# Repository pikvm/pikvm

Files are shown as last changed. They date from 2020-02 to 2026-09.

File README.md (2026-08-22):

# Open and inexpensive DIY IP-KVM based on Raspberry Pi
 

A very simple and fully functional Raspberry Pi-based KVM (Keyboard-Video-Mouse) over IP that you can make with your own hands. This device helps to manage servers or workstations remotely, regardless of the health of the operating system or whether one is installed. You can fix any problem, configure the BIOS, and even reinstall the OS using the virtual CD/DVD or Flash Drive.

The website: [pikvm.org](https://pikvm.org). Also check out [the documentation](https://docs.pikvm.org) and join the [Discord Community Chat](https://discord.gg/bpmXfz5) for news, questions and support! Also you can visit our [Support Forum](https://forum.pishop.com/c/pikvm).

| Web UI                                     |
| ------------------------------------------ |
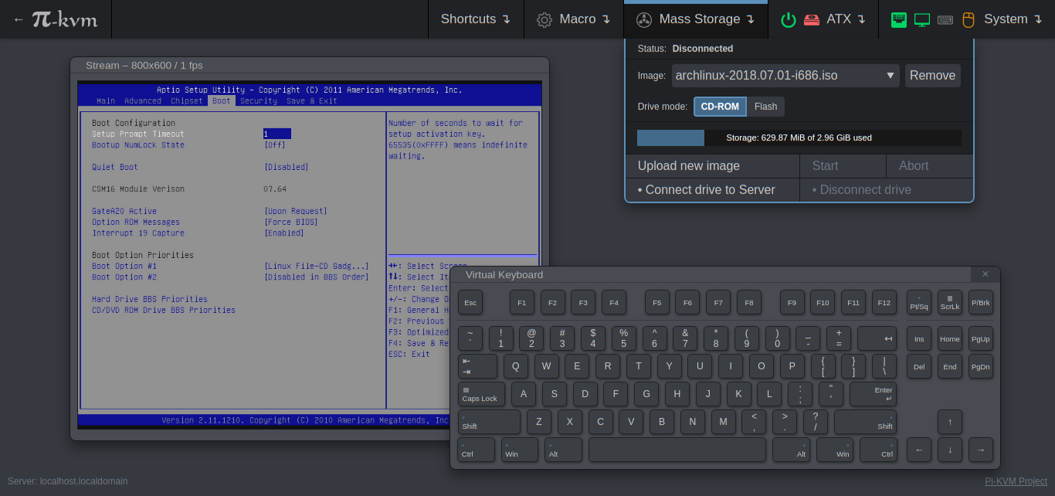
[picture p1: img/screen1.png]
|  |

# Features
* Can be made based on **Raspberry Pi 2**, **Pi 3**, **Pi 4**, **Pi 5** and **Zero2W**;
* **FullHD video** using advanced **HDMI-to-CSI bridge** or **USB dongle**;
* [Proven](https://docs.pikvm.org/latency) lowest **35-50ms H.264 latency** among all KVMs on the market;
* WebRTC, H.264-over-HTTP and MJPEG video;
* Bootable **Virtual CD/DVD** and **Flash Drive**, ability to store images on **NFS**;
* USB **Keyboard** and **mouse** (with leds and the wheel), Bluetooth HID, Mouse jiggler, full support of PS/2;
* **Control the server power** using ATX functions;
* Access via **Web UI** or **VNC**;
* Ability to use **IPMI BMC**, **IPMI SoL**, **Redfish** and **Wake-on-LAN** to control the server;
* **The ready-made OS** with read-only filesystem;
* **Extensible authorization** and HTTPS out of the box;
* **Health monitoring** of the Pi;
* Control **GPIO** ports and **USB relays**;
* 100% Open Source!

# Variants

PiKVM supports several different hardware configurations, referred to as **platforms**.
All of them uses our common open source software stack.

### PiKVM V3 & V4 - Now with web camera!

* **PiKVM V4** and **V3** are our own **plug-and-play, fully assembled, industrial grade, robust** devices.<br>
    Supports **H.264 video, audio, microphone and web camera** transmission, **host power management**, **mass-storage emulation** and much more.
    They are really well-made, reliable things which you can use yourself or provide to your clients.
    V4 and V3 also have more features than DIY builds.

* **PiKVM V2** and **V1** devices are **DIY** so you can make it with your own hands.<br>
   If you don't know where to put your old Raspberry Pi, here's a great goal.

**Look at what Tech Bloggers are saying about us :)**

<table>
<tr>
    <td align="center"><b>PiKVM V4 Plus &amp; Mini</b></td>
    <td align="center"><b>PiKVM V3</b></td>
    <td align="center"><b>DIY PiKVM</b></td>
</tr>
<tr>
    <td align="center"> <!-- V4 Plus/Mini -->
        <a href=https://youtu.be/2HqbQdZUEmY><b>Novaspirit Tech</b></a><br>
        <a href=https://youtu.be/Kx5MlT2jYxU><b>Level1Techs</b></a><br>
        <a href=https://www.youtube.com/watch?v=PppcpSVYh0E><b>Jeff Geerling</b><br>
    </td>
    <td align="center"> <!-- V3 -->
        <a href=https://www.youtube.com/watch?v=232opnNPGNo><b>~~~ LINUS TECH TIPS ~~~</b></a><br>
        <a href=https://youtu.be/dTchVKxx7Fo><b>Novaspirit Tech</b></a><br>
        <a href=https://www.youtube.com/watch?v=LwsznhIBPMc><b>Level1Techs</b></a><br>
        <a href=https://www.youtube.com/watch?v=aOgcqVcY4Yg><b>Techno Tim</b></a><br>
        <a href=https://www.youtube.com/watch?v=fnd6wojrw3c><b>The Geek Freaks</b> (DE)</a><br>
    </td>
    <td align="center"> <!-- DIY -->
        <a href=https://youtu.be/plP9Y1likRg><b>Novaspirit Tech</b></a><br>
        <a href=https://hackaday.com/2020/11/24/true-networked-kvm-without-breaking-the-bank><b>Hackaday</b></a><br>
        <a href=https://www.tomshardware.com/how-to/kvm-over-ip-raspberry-pi><b>Tom's HARDWARE</b></a><br>
        <a href=https://www.elektormagazine.com/news/pikvm-raspberry-pi-as-a-kvm-remote-control><b>Elector MAG</b></a><br>
        <a href=https://youtu.be/9YhPWjWv5gw>Our boring presentation of DIY</a><br>
    </td>
</tr>
<tr>
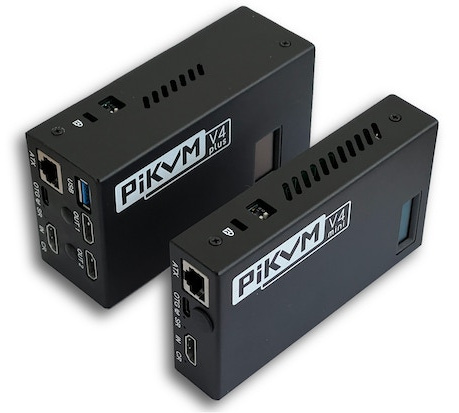
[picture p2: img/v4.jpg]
    <td align="center"></td>
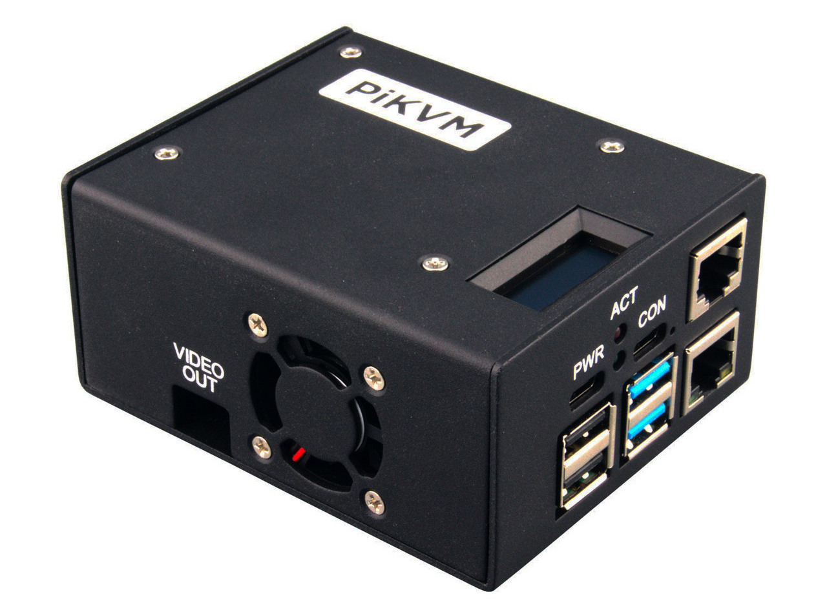
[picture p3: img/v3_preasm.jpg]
    <td align="center"></td>
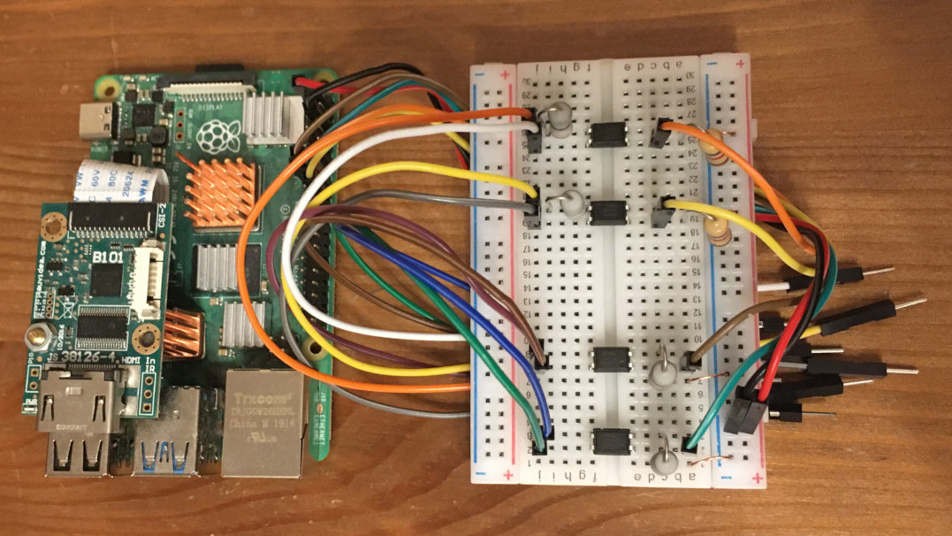
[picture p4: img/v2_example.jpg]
    <td align="center"></td>
</tr>
<tr>
    <td align="center"><a href=https://pikvm.org/buy><br><b>~~~ BUY IT NOW ~~~</b></a><br><br></td>
    <td align="center"><a href=https://pikvm.org/buy><br><b>~~~ BUY IT NOW ~~~</b></a><br><br></td>
    <td align="center"><a href=#diy-getting-started><br><b>DIY Getting Started</b></a><br><br></td>
</tr>
</table>

<hr>

**NEW PRODUCT! [PiKVM Switch](https://docs.pikvm.org/switch) will help you to transform PiKVM into a multiport device!**



<hr>

| <div align="center">⭐ ⭐ ⭐ **CORE SYSTEM** ⭐ ⭐ ⭐</div> | **V4 Plus** | **V4 Mini** | |  **V3**  | | **DIY V2** | **DIY V1** |
|---|:---:|:---:|---|:---:|---|:---:|:---:|
| | | | | | | | |
| **Plug and Play out of box!** | ✅ | ✅ | | ✅ | | DIY | DIY |
| Base Raspberry unit | CM4<br><sup>Included!</sup> | CM4<br><sup>Included!</sup> | | RPi4<br><sup>Included!</sup> | | RPi5<br>RPi4<br>Zero2W | RPi3<br>RPi2<br>Zero2W |
||
||
| <div align="center">⭐ ⭐ ⭐ **VIDEO** ⭐ ⭐ ⭐</div> | **V4 Plus** | **V4 Mini** | |  **V3**  | | **DIY V2** | **DIY V1** |
||
| [**Video passthrough** to local display](https://docs.pikvm.org/pass) | ✅ | ❌ | | ❌ | | ❌ | ❌ |
| **HDMI 1920x1200@60Hz** support<br>for big displays | ✅ | ✅ | | ❌ | | ❌ | ❌ |
| **HDMI 1920x1080@60Hz** support<br>for better BIOS/UEFI compatibility | ✅ | ✅ | | ❌ | | ❌ | ❌ |
| **HDMI audio** capture | ✅ | ✅ | | ✅ | | ❌ | ❌ |
| **Microphone** for two-way audio | ✅ | ✅ | | ✅ | | ❌ | ❌ |
| **Web camera** for video calls | ✅ | ✅ | | ✅ | | ❌ | ❌ |
| **Super fast H.264 & MJPEG video:**<br>up to 1080p 60fps | ✅ | ✅ | | ✅ | | ✅ | ✅ |
||
||
| <div align="center">⭐ ⭐ ⭐ **PERIPHERY** ⭐ ⭐ ⭐</div> | **V4 Plus** | **V4 Mini** | |  **V3**  | | **DIY V2** | **DIY V1** |
||
| USB keyboard/mouse emulation | ✅ | ✅ | | ✅ | | ✅ | ✅ |
| Virtual **Flash Drive** / **CD/DVD** emulation | ✅ | ✅ | | ✅ | | ✅ | ❌ |
| Ability to simulate **"eject/insert"** for USB | ✅ | ✅ | | ✅ | | ❌ | ❌ |
| **Onboard ATX controller** for power management of the host | ✅ | ✅ | | ✅ | | DIY | DIY |
| **Built-in OLED** with IP and other info | ✅ | ✅ | | ✅ | | ❌ | ❌ |
| **Multiport KVM switches** support | ✅ | ❌ | | ✅ | | ✅ | ✅ |
||
||
| <div align="center">⭐ ⭐ ⭐ **HARDWARE ABILITIES** ⭐ ⭐ ⭐</div> | **V4 Plus** | **V4 Mini** | |  **V3**  | | **DIY V2** | **DIY V1** |
||
| **Internal secured USB 3.0** storage port | ✅ | ❌ | | ❌ | | ❌ |  ❌ |
| **USB serial** console port | ✅ | ✅ | | ✅ | | ❌ |  ❌ |
| **CISCO-style RJ-45** console port | ✅ | ❌ | | ✅ | | ❌ |  ❌ |
| A **real-time clock** for accurate logging | ✅ | ✅ | | ✅ | | ❌ |  ❌ |
| **Locator LED** to find device in the rack | ✅ | ✅ | | ❌ | | ❌ |  ❌ |
| [**mPCIe slot** with USB lines for **LTE/5G** cards](https://docs.pikvm.org/modem) | ✅ | ❌ | | ❌ | | ❌ |  ❌ |
| **SIM card slot** for modem | ✅ | ❌ | | ❌ | | ❌ |  ❌ |
| **External antenna** support | ✅ | ✅ | | ❌ | | ❌ |  ❌ |
| USB host support (external USB devices connectivity) | ✅ | ❌ | | ✅ | | ✅ |  ✅ |
||
||
| <div align="center">⭐ ⭐ ⭐ **POWER AND COOLING** ⭐ ⭐ ⭐</div>  | **V4 Plus** | **V4 Mini** | |  **V3**  | | **DIY V2** | **DIY V1** |
||
| Cooling system / fan type | Quiet<br>Radial | Fanless | | Axial | | DIY | DIY |
| PWM fan controller | ✅ | ❌ | | ✅ | | ❌ |  ❌ |
| **Fan speed and health** monitoring | ✅ | ❌ | | ❌ | | ❌ |  ❌ |
| Power consumption in idle mode | 3.3W | 2.65W | | 3.3W | | | |
||
||
| <div align="center">⭐ ⭐ ⭐ **MISCELLANEOUS** ⭐ ⭐ ⭐</div> | **V4 Plus** | **V4 Mini** | |  **V3**  | | **DIY V2** | **DIY V1** |
||
| USB relays, lamps, smartplugs control | ✅ | ❌ | | ✅ | | ✅ | ✅ |
| Pi's GPIO ports control from the Web UI | ❌ | ❌ | | ✅ | | ✅ | ✅ |

<details>
  <summary><b>More indepth details about the PiKVM features</b></summary>

## Fully-featured and modern IP-KVM
* **Cheaper, but better than commercial solutions**  
  Costs between $30 and $100 depending on the features desired. Even the most expensive configuration will be cheaper than a $500 commercial IP-KVM.
* **Easy to build - For the V1 variant**  
  A ready-to-use OS that can be created just by running `make build` and installed to an SD-card using `make install`. The hardware can be made in half an hour and without soldering.
* **The widest hardware support**  
  There are many ways to build a PiKVM. Video capture devices can be attached using the CSI-2 or USB interfaces. Raspberry Pi models 2, 3, 4 or Zero2W may be used. Any combination of hardware is supported, and PiKVM implements the maximum possible set of features.
* **Very low latency**  
  ~35-50 milliseconds of video latency. This is the smallest delay of all existing solutions.
* **Extra lightweight and fancy Web UI**  
  No weird proprietary clients. No ugly Java applets. Just use your favorite browser to connect to the PiKVM. No flash plugins either!
* **Keyboard and mouse**  
  Mouse usage works directly in the browser. The keyboard emulator supports displaying the state of the keyboard LEDs.
* **Mass Storage Drive**  
  On the Raspberry Pi 4, 5 and Zero2W, PiKVM can emulate a virtual CD/DVD or Flash Drive. A live image can be uploaded to boot the attached server.
* **ATX power management**  
  With a very simple circuit that can be assembled on a breadboard, the power button of the attached server can be controlled using the ATX button headers on the motherboard.
* **Security**  
  PiKVM can be opened to the Internet and no one will get access without the password. SSL is used to protect traffic from being intercepted by third parties.
* **Local monitoring**  
  PiKVM monitors the health of the Raspberry Pi board and will warn you if it's too hot or is not receiving enough power.
* **GPIO management**
  You can control GPIO and USB relays via the web interface. The extensible interface allows you to make anything out of it.

## Production-ready  
* **Linux-based embedded OS**  
  The PiKVM OS is based on [Arch Linux ARM](https://archlinuxarm.org) and can be customized for any needs. Thousands of pre-built binary packages are at your service and can be updated with a single command!
* **Read-only filesystem**  
  By default the OS runs in read-only mode, as an embedded system should. This prevents damage to the memory card due to a sudden power outage.
* **VNC server**  
  The managed server and its BIOS can be accessed using a regular VNC client which supports JPEG compression.
* **IPMI BMC and Redfish**  
  Use `ipmitool`, `ipmiutil` or any existing network infrastructure that supports IPMI to monitor and manage the server's power. Redfish and `redfishtool` supported too.
* **Wake-on-LAN**  
  PiKVM can be configured to power up a managed server using WoL. This will be available in the Web menu.
* **Extensible authorization methods**  
  Multiple PiKVMs can be configured to use a [common authorization service](https://github.com/pikvm/kvmd-auth-server). PAM and its rich authorization mechanisms can also be used to integrate PiKVM into your existing authentication infrastructure.
* **Macro scripts**  
  If repetitive actions must be performed on the attached server (or on several different servers), a macro can be recorded with keyboard & mouse actions and can be played back multiple times.

## Open Source
* **Community & support**  
  PiKVM has a large community. Join the [discord chat](https://discord.gg/bpmXfz5) or [Forum](https://forum.pishop.com/c/pikvm) if you have any questions.
* **Extensible**  
  PiKVM was designed as a set of microservices with a plug-in architecture. It's very easy to modify and maintain.
* **Comprehensive API**  
  Everything that can be done via the user interface can also be done via a powerful HTTP API.
* **Know-how**  
  We created [our very own MJPG video server](https://github.com/pikvm/ustreamer) written in C with multi-threading support and GPU video encoding - the fastest streaming solution available to provide the best video quality for PiKVM. We also tested a lot of hardware configurations so that you can be sure devices you assemble will work reliably.
</details>

-----

# DIY Getting Started
PiKVM supports several different DIY platforms. Now available: **V2** and **V1**.
* **Recommended**: **V2** is the most powerful implementation for **Raspberry Pi 4**, **Pi 5** and **Zero2W** supporting all of the features of PiKVM including the **Mass Storage Drive**. **It's also the easiest to make**.
* **V1** was designed to work with **Raspberry Pi 2** and **3** that do not have USB emulation port and requires a few more components for a basic implementation. It also does not support the Mass Storage Drive feature.

The full list of parts is at the very beginning according to the assembly instructions for the corresponding platform.
You can review both options to decide which one is most suitable for you.

So, again, in short:

* **DIY PiKVM V2:**
  * [Here are the instructions and a complete list of components](https://docs.pikvm.org/v2).
  * Requires Raspberry Pi 4 (recommended), Pi 5 or Zero 2 W.
  * Supports H.264 (for recommended CSI capture).
  * Supports CD/DVD and Flash Drive (mass storage) emulation.
  * It is recommended as a simpler and more feature-rich way compared to V1.

* **DIY PiKVM V1:**
  * [Here are the instructions and a complete list of components](https://docs.pikvm.org/v1).
  * Requires Raspberry Pi 2 or 3.
  * Requires Raspberry Pi Pico for the keyboard/mouse emulation.
  * Requires extra wiring and little bit more parts.
  * Supports H.264 (for recommended CSI capture).
  * Doesn't support CD/DVD and Flash Drive (mass storage) emulation.

-----

# Donate
This project is developed by Open Source enthusiasts. If you find PiKVM useful or it has saved you a long trip to check on an unresponsive server, you can support us by donating a few dollars on [Patreon](https://www.patreon.com/pikvm) or [Paypal](https://paypal.me/pikvm) or buying our devices. With this money, we will be able to buy new hardware (Raspberry Pi boards and other components) to test and maintain various configurations of PiKVM, and generally devote significantly more time to the project. At the bottom of this page are the names of all the people who have helped this project develop with their donations. Our gratitude knows no bounds!

If you wish to use PiKVM in production, we accept orders to modify it for your needs or implement custom features you require. Contact us via [live chat](https://discord.gg/bpmXfz5) or email the lead developer at: mdevaev@gmail.com

-----

# Special thanks
These kind people donated money to the PiKVM project and supported work on it. We are very grateful for their help, and commemorating their names is the least we can do in return.

<details>
  <summary>View all people!</summary>

* A. Isenring
* Aaron Graubert
* Aaron Heise
* Aaron Stein
* Accalia
* Adam Goodbar
* Adam S
* Adam Stuart
* AdamBomb
* adipisicing
* Adrian Basham
* Adrian Popescu
* Ahmed Syed
* Alberto Bassi
* alejandro
* Aleksei Brusianskii
* Alessio Curri
* Alex T
* Alex Z
* Alexander Karmanov
* Alexander Lahuerta
* Alexander Martin
* Alexander Pankov
* Alexandre Jablonski
* Alexey Kamenskiy
* alm0241
* Alok Anand
* Alucard
* Ananthaneshan Elampoornan
* Andreas Grundler
* Andreas Marufke
* Andreas Schmid
* Andrew Brant
* Andrew Melton
* Andrew Reusch
* Andrew Ruan
* Andrzej V
* Andy
* Andy Keys
* Anish Patel
* Anix
* Anonymous
* Anthony Junk
* Anton Kovalenko
* Armen
* Aron Green
* Aron Perelman
* Artem Simonov
* Arthur Mayer
* Arthur Woimbée
* Ashlesh Chaudhari
* Asim Shakour
* Augusto Becciu
* AVS Computer
* awkspace
* Badal Patel
* baddog
* Bao Tin Hoang
* Bean Co.
* Bela Bargel
* Belf Igor
* Ben Gordon
* Ben Scott
* Benedikt Heine
* Benedikt Meier
* Benjamin Frewert
* Benjamin Melancon
* Benjamin Schwartz
* Benjamin Stegmann
* Benni Stauder
* Bernhard Fitzke
* Beu
* bikmaek
* bitjoe
* Bits and Bytes Computers LLC
* Bjoern Petsch
* Blair Hasler
* Blindside
* Blue Frog LLC
* Bootstrapper - Programmierung erklärt
* Bosco
* Bradford King
* Brainspore Networks
* Branden Shaulis
* Brandon Daniels
* Brian
* Brian Moses
* Brian T Mulcahy
* Brian Vecchiarelli
* Brian White
* brodonalds
* Bruno Gomes
* Bryan Adams
* Bryan Montgomery
* Buzzer
* C P ELSE
* Calanish
* Cameron Hatcher
* Cameron Tacklind
* Carl Mercier
* Carl-Fredrik Johansson
* Carlos Eduardo Porter Herrera
* Carlos Garcia
* Carlos Manuel Torres
* cbad536
* César Nascimento
* CHINATERA LIMITED
* Chris Blackmon
* Chris Burton
* Chris Campbell
* Chris Jackson
* Chris Lewis
* Chris Rizio
* Christi King
* Christian Schlögl
* Christian Svensson
* Christoph Dette
* Christof Maluck
* Christoffer Lund
* Christopher Bulla
* Christopher Gelatt
* Christopher Hearn
* Christopher Mandlbaur
* Christopher Mendoza
* Christopher Simms
* Chucktastic
* Cihan VURAL
* clauskj3r
* Clifford Coleman
* Clinton Lee Taylor
* Cole Imhoff
* Colin Goodman
* Corey Layton
* Corey Lista
* Craig Keenan
* Crossfactor
* Cruzzer
* ctag
* Curt Sammer
* CyB0rgg
* DeMentor
* Desmond Whitt
* Daegara
* DailyAneurism
* Damon Meledones
* Dan Berkowitz
* Dan Brakeley
* Daniel Bowder
* Daniel Cabrera
* Daniel Davila
* Danilo Saft
* Danne
* Dariusz Techmański
* David
* David Brausewetter
* David Davis
* David Godibadze
* David Howell
* David Irvine
* David Klinkman
* David Niemann
* David Shay
* David Ye
* David York
* Denis
* Denis Andreev
* Denis Yatsenko
* Dennis Becker
* Dennis Joslin
* Dennis Lomet
* Derek Jarvis
* Derek Yap
* Didrik
* digitalbaconbits
* Dimitrij Jedich
* dixon wong
* dizztrukshin
* Dmitry Shilov
* DogeLabs
* Dominic Phoon
* Dominik Klonowski
* Donald Hays
* Edmon Abdul Nur
* Edward Wang
* Egan Ford
* Elani Ferri
* Elliot Woo
* Entt
* Eric Phenix
* Ethan Shold
* Eugene Sukhodolin
* ewook
* eye-catcher.com
* Fabian Druschke
* Fabiano Sidler
* Far Pin Solutions, LLC
* Felyx Gabryel
* Fergus McKay
* Finn Ebenritter
* floppy
* fo0bar
* Foad Yousef
* Foamy
* Foli Ayivoh
* Folkert Weistra
* Francisco Pavon
* Frank
* Frank Sander
* Frederick Czajka
* Fredrik Idréus
* Garrett Dangerfield
* Ge Men
* Geekworm
* Genkinger Andreas
* Geijer
* Geoffrey Wright
* George Becker
* Georgy Brodsky
* Gerald
* Gerardus Vernimmen
* Gernot Neuschröer
* Giovanni Fulco
* GK
* Glen Dragon
* Greg Winterstein
* Gregory Smith
* Gregory Treantos
* grewil
* Grey Cynic
* Guenter Honisch
* Guido Bernacchi
* Gustin Johnson
* György Tamás Vizi
* Haiberg GmbH
* Haven Zheng
* Heibunny
* Heikki Tiittanen
* Helio Leonardo Pinheiro e Mota
* Henrik Ählström
* Henry Hood
* HimKo
* HouseFPV
* Howard Simons
* HyunohRyu
* Icculus
* iks
* INFO TRX INC
* Invader Monks
* Ioannis Karageorgos
* Isaac
* IT Lifesaver
* Ivan Ganev
* Ivan Josiah Lapis
* Ivan Shapovalov
* iwbjhbweriuhf
* J
* J L
* Jaanus
* Jackson Wyatt
* Jacob Karaffa
* Jacob Morgan
* James Cadd
* James Cobb
* James Edwards
* James Kocher
* James Mayhugh
* James Noonan
* James Ye
* Jamie Murphy
* Jamie Scott
* Jan Niehusmann
* Jannick Oursin
* Jari Hiltunen
* Jason Crossley
* Jason Downey
* Jason Toland
* Jasper Backer
* Jay Davis
* Jay Isaacs
* Jazereel Goh
* Jean-Daniel Croteau
* Jean-Philippe Guilbault
* Jeff
* Jeff Bowman
* Jeff Urlwin
* Jennifer Herting
* Jennifer Rowlett
* Jeremy Abel
* Jeremy Combs
* Jeremy Hines
* Jerremy Holland
* Jerry Nall
* Jerry Y. Chen
* Jim Bailey
* Jim Harbin
* Jimmy Burgett
* Jimmy Stanley
* Joachim Bruening
* Joe Hanson
* Joe Hinteregger
* Joe Ventura
* Joel Jacobs
* Johannes Heigermose
* John Andersen
* John Copeland
* John F Glenn
* John Holmes
* John Kelley
* John McGovern
* Johnny Henson
* Jon Ferguy
* Jon-Eric
* Joni Ruuskanen
* Jonas Fischer
* Jonathan Slenders
* Jonathan Vaughn
* Joost Backer
* Joseph Swift
* Josh Nethery
* Josh Ricker
* Josh VanDeraa
* Joshua Futterer
* Jordan Blake
* Jordi Pakey-Rodriguez
* Joris van Embden
* Jozef Riha
* Jörgen Fredriksson
* Julian Forero
* Julian Schneider
* Julien Angelier
* Justin
* Justin Waters
* Kai Hadler
* Kamil Chyba
* Kari Matti Korpi
* Karl Dunne
* Karl Moos
* Keith Muggleton
* Ken Lee
* Kenneth Younger III
* Kenny Hui
* KeonWoo PARK
* Kevin Bajohr
* Kevin Schwartz
* Kevin Sherwood
* Kiera Kujisawa
* Kiran Schuler
* Koloman
* Konrad Neitzel
* Krzysztof Żelaśkiewicz
* Lance Ward
* Larry Meaney
* Lars
* Lars Reinhardt
* Lee Wilkinson
* LeeNX
* Leon Siegl
* Leonard Feineis
* Lewis Wild
* Liran
* Liviu Dimitriu
* Lizardo Hernandez
* LoCascio
* Lordbob75
* Lothar Schweikle-Droll
* Louis Müller
* LSDTripp
* Ľubor Slušný
* Luca Di Diomede
* Lucio De Carli
* Luiz Bizzio
* Lukas Bischof
* Lukas Kammerer
* Lukas Söder
* Maksim Terehin
* Malcolm Cameron
* Manfred Radeschnig
* Marc Khouri
* Marcin Wilk
* Marcio Zimbres
* Marco Rossi
* Marcos Wolf
* Marek Marczykowski-Górecki
* Marius
* Mar. Balske
* Mark Farrell
* Mark Gilbert
* Mark Knam
* Mark Robinson
* Markrosoft
* Markus Halm
* Markus Schicker
* Markus Sobczack
* Marshall Bjerke
* Marten Hermans
* Martin Gasser
* Martin Hofbauer
* Martin Raine
* Martin Suelmann
* Martin Wilhelmi
* Marvin Honderboom
* Mateusz Grabowski
* Mathias Uhl
* Matt Kane
* Matthew Cameron
* Mauricio Allende
* Max Evans
* Mecky
* Mehmet Aydoğdu
* Michael Bartholomew
* Michael Bell
* Michael Bombe
* Michael Collins
* Michael Copeland
* Michael Ho
* Michael Kovacs
* Michael Lynch
* Michael Pennington
* Michael Sage
* Michael Stella
* Michael Thalmann
* Michael Wu
* MichaelZ
* Michel Bissonnette
* Mikael Wikström
* Mike Mason
* Mikhael Mariano
* Milan Burda
* Milan Múčka
* Miles Davis
* Minh Tang
* Moez Tharani
* Morgan Helton
* Murad Khasawneh
* Myron Weber
* N Patel
* Nathaniel Griswold
* Nelson Lee
* nezu
* Nicholas Jeppson
* Nicholas Kopas
* Nicholas Walczak
* Nick Leffler
* Nick Roethemeier
* Nico Baumgartner
* Nicolai Kragh-Hansen
* Nicolas Christener
* Nigel Smith
* Nihal Fernando
* Nils Orbat
* Nis Wechselberg
* Nithin Philips
* Nod Swal
* Nolan Haynes
* Noxigen LLC
* nubbn
* nybble
* Oh Be
* Oliver Schwarz
* Oliver Zimmer
* Omar El-Domeiri
* Omar Siam
* Oscar
* Patrick
* Patrick Fortin-Ducharme
* Patrick McDowell
* Patrick Wagstrom
* Paul Bishop
* Paul De La Rosa
* Paul Pietkiewicz
* Paul Tan
* Pawel Trofimiuk
* Peder Madsen
* Peter
* Peter Drayton
* Peter Farrelly
* Peter Okelmann
* Petra Lohmann
* Petri Heiskanen
* Phil Wu
* Philip Edwards
* Philip Merricks
* Pierre Brassart
* Pierre Peine
* posicat
* pozitron03
* Przemysław Szypowicz
* P_Dmitrij
* Qteal
* Quattro Uno
* Quentin Peten
* Ralph Borchers
* Ranc1d
* Randall D Bilbrey
* RandomJerk
* Ref Chowdhury
* Raphael Schitz
* René Rathenau
* ReysDad
* Ricardo Marques
* Richard
* Richard Bernarts
* Richard Fancher
* Richard Freemantle
* Richard Michael
* Rico Cantrell
* Rob
* Rob Holden
* Rob Tongue
* Robert Klauco
* Robert Weemhoff 
* Robin Gfatter
* Rodion DENISYUK
* Rohit Priyadarshi
* Rolfs 3D UG
* Ronald LeBaron
* Ronald Wells
* Ronny Haldorsen
* rotx
* Rufo Sanchez
* Russell Scott
* Ryan
* Ryan Peacock
* Samed Ozoglu
* Sameul Davies
* Samuel Cote
* Samuel Vetsch
* Samuel Walker
* Sarah Foster
* Sarten X
* Satish Alwani
* Scott
* Scott Gagon
* Scott Spicola
* Scott Tusing
* Scott Worthington
* Scuba
* Sean
* Sean Akers
* Sean c Rickard
* SEAT
* Sebastian
* Seonwoo Lee
* Sergey Lukjanov
* Seth Jennings
* Shane Selling
* Shawn Butts
* Sheran Gunasekera
* Shichun Chen
* Shin Guey Wong
* Simon Evans
* Simon Sundgaard
* Simplistic Realities
* Sirmo
* Snowy Maslov
* Solve Technology
* srepac
* Stefan Bautz
* Stefan Müller
* Stefan Stemmer
* Stefan Vaillant
* Stephan Schmidt
* Stephen
* Stephen Hocking
* Steve Jones
* Steve Kerr
* Steve Ovens
* Steve Stringham
* Steven Richter
* Stratagem Solutions Ltd
* Sven Breckler
* sudo34
* SuperHiTech
* Tango_Echo_Alpha
* Tarlak Desaydrone
* TechBear
* techlobo
* Ted
* Tejun Heo
* TheSnowedOne
* TheTechGiant
* Thomas Charisoulis
* Thomas Gitlin
* Thomas Hagenmaier
* Thomas Hedberg Jensen
* Thomas Price
* Thomas Søfteland
* Tim Lenz
* Tim Wilkinson
* Timo Brinkmann
* Timothee Besset
* TitomusPrime
* Tom Lawson
* Tom York
* Tomas Kuchta
* Tomáš hrubý
* Torsten Droste
* Torsten Knoll
* Tobias Schafferhans
* Tracy Fitch
* Tristan Schoening
* Truman Kilen
* turbochris
* tutanak
* Tyler
* Udo Schroeter
* Uli Fahrer
* Vasily Lazarev
* Venmo
* Vicente Salvador Cubedo
* Vidru Eduard
* Viktor Aschenbrenner
* Viktor Ekmark
* Vincent Chov
* Vlad Sterescu
* Volker Gropp
* Walli
* Walter_Ego
* William Wenzel
* Will Froning
* William Hooper
* William Perrin
* William Stearns
* Woojin Son
* xMdb
* Yanko Kaneti
* Yaroslav Kulikovskikh
* Yethal
* Yevgeniy Kuksenko
* Yew Kay Yan
* Yogi
* Yigal Dar
* YURI LEE
* Yurii Ostapchuk
* Zeljko
* zgen
* Zoltan Magyari
* Zsombor Vari
</details>

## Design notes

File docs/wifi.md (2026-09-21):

---
title: Setting up Wi-Fi
description: Learn how to configure a Wi-Fi connection on your PiKVM to one or multiple networks
---

!!! tip
    * There is nothing more reliable than wired Ethernet, so it's better to use it. Wi-Fi with the steel case (on PiKVM V3 and V4) results in poor performance. But who are we to stop you... :)
    * Devices based on Raspberry Pi Zero 2 W does not support 5GHz Wi-Fi.

The following describes how to setup a Wi-Fi connection. We recommend to
do this while having a display and keyboard or a serial console
connected directly to the Raspberry Pi as you will loose network
connectivity once you connect to a Wi-Fi. Alternatively you can connect
to the PiKVM via SSH. The built-in Web Terminal (available through the
browser) should also work.

!!! warning "Take a look at the easiest way"
    This guide describes how to manually set up a Wi-Fi. An easier way is to use [On-boot config](on_boot_config.md).
    It is also mandatory for Zero 2 W board.

-----
## Setting up Wi-Fi manually

1. Make filesystem writable using the `rw` command.

2. Create the Wi-Fi settings file `/etc/systemd/network/wlan0.network` with the following content:

    ```ini
    [Match]
    Name=wlan0

    [Network]
    DHCP=yes
    DNSSEC=no

    [DHCP]
    ClientIdentifier=mac
    RouteMetric=50
    ```

3. Set network ESSID and password:

    ```console
    [root@pikvm ~]# wpa_passphrase 'MyNetwork' 'P@assw0rd' > /etc/wpa_supplicant/wpa_supplicant-wlan0.conf
    [root@pikvm ~]# chmod 640 /etc/wpa_supplicant/wpa_supplicant-wlan0.conf
    ```

    [PiKVM V3](v3.md), [PiKVM V4](v4.md), and DIY builds based on Raspberry Pi 4
    include experimental support for connecting to WPA3 networks. To connect to
    a WPA3 network, you need to make sure your PiKVM is up-to-date, and edit the
    `/etc/wpa_supplicant/wpa_supplicant-wlan0.conf` file after creating it:

      1. uncomment the plain-text `psk=` line, and comment/remove the hashed `psk=` line;
      2. add options `key_mgmt=SAE` and `ieee80211w=2` before the closing `}` line;
      3. finally, add a global option `sae_pwe=2` before the `network={` line.

    For instance, if your `/etc/wpa_supplicant/wpa_supplicant-wlan0.conf` looks like this:
    ```
    network={
      ssid="MyNetwork"
      #psk="P@assw0rd"
      psk=4134d31e95e6387761d485796310894b1ac5e9bb86b3b96e0dd3473cea440014
    }
    ```

    You need to change it as follows:
    ```
    sae_pwe=2

    network={
      ssid="MyNetwork"
      psk="P@assw0rd"
      #psk=4134d31e95e6387761d485796310894b1ac5e9bb86b3b96e0dd3473cea440014
      key_mgmt=SAE
      ieee80211w=2
    }
    ```

    !!! note "Connecting to mixed WPA2/3 networks in WPA2 mode (older devices)"
        Add options `key_mgmt=WPA-PSK-SHA256 WPA-PSK` and `ieee80211w=1`
        to `/etc/wpa_supplicant/wpa_supplicant-wlan0.conf` inside the `network={` block.

        This enables WPA2 PMF (protected management frame) support, which is
        often necessary to connect to WPA2/3 mixed mode networks.

    !!! note "Using Wi-Fi with hidden ESSID"
        Add global option `scan_ssid=1` to `/etc/wpa_supplicant/wpa_supplicant-wlan0.conf`

    !!! note "Using 5GHz Wi-Fi in the USA"
        Add global option `country=US` to `/etc/wpa_supplicant/wpa_supplicant-wlan0.conf`

    !!! note "Block 2 GHz or 5 GHz"
        Add option `bssid=xx:xx:xx:xx:xx:xx` to `/etc/wpa_supplicant/wpa_supplicant-wlan0.conf`
        inside the `network={` block.

        Here, `xx:xx:xx:xx:xx:xx` is the MAC address of the specific 2 GHz or 5 GHz
        AP that you want to _allow_. All other APs in this network will be blocked.

4. Enable the `wpa_supplicant@wlan0` service:

    ```console
    [root@pikvm ~]# systemctl enable wpa_supplicant@wlan0.service
    ```

5. Make filesystem read-only again using `ro` command

6. Reboot PiKVM for immediate use with `reboot` command or apply network settings in current boot with `networkctl reload && networkctl reconfigure wlan0`.

-----
## Multiple Wi-Fi networks

You can configure PiKVM to connect to one of several known Wi-Fi networks.
To do this, just simply add the configuration of these networks.
Pay attention to the symbol `>>`, it is used to append at the end of configuration,
while a single `>` will overwrite the entire configuration.

1. Make the filesystem writeble with `rw` command.

2. Add some new networks:

    ```console
    [root@pikvm ~]# wpa_passphrase 'Wifi1' 'P@assw0rd' >> /etc/wpa_supplicant/wpa_supplicant-wlan0.conf
    [root@pikvm ~]# wpa_passphrase 'Wifi2' 'P@assw0rd' >> /etc/wpa_supplicant/wpa_supplicant-wlan0.conf
    [root@pikvm ~]# wpa_passphrase 'Wifi3' 'P@assw0rd' >> /etc/wpa_supplicant/wpa_supplicant-wlan0.conf
    ```

    If any of those networks enable or require WPA3, edit your `wpa_supplicant-wlan0.conf`
    as described above, making changes to relevant `network={...}` blocks.

3. Restart the service: `systemctl restart wpa_supplicant@wlan0.service`.

4. Make the filesystem read-only again using `ro` command

-----
## Antenna on PiKVM V4

PiKVM V4 has a robust metal case that protects your device from physical damage and electromagnetic interference.
This also means that an external antenna must be used for Wi-Fi. We recommend the official Antenna Kit for Raspberry Pi.

To install the antenna, fix it in the round hole in the back side of the PiKVM, and plug the wire to the connector
on the Compute Module 4.

Next, to activate the antenna, add line `dtparam=ant2` to the `/boot/config.txt` file on PiKVM, and perform `reboot`.

type:video

-----
## Useful console commands

* `iwconfig` - Manipulate the basic wireless parameters.
* `iwlist` - Allow's you to initiate scanning and list frequencies, bit-rates, encryption keys, etc.
* `iwspy` - Displays per node link quality.
* `iwpriv` - Allow's you to manipulate the Wireless Extensions specific to a driver (private).

??? example "Some examples"
    ```console
    [root@pikvm ~]# iw dev wlan0 scan | egrep "signal:|SSID:" | sed -e "s/\tsignal: //" -e "s/\tSSID: //" | awk '{ORS = (NR % 2 == 0)? "\n" : " "; print}' | sort
    ```
    ```console
    [root@pikvm ~]# iwlist wlan0 scan | egrep "Cell|ESSID|Signal|Rates"
    ```
    ```console
    [root@pikvm ~]# iwlist wlan0 scan
    ```
    ```console
    [root@pikvm ~]# iw wlan0 info
    ```

-----
## Additional resources

* [Arch Linux Wiki for systemd-networkd](https://wiki.archlinux.org/title/systemd-networkd)

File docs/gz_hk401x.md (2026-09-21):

# GZVich (广正维创) 4-port HDMI USB KVM Switch



This KVM seems only selling in China (On [Taobao](https://item.taobao.com/item.htm?id=608572288478) and [JD](https://item.jd.com/61870996709.html)). It can control by the buttons on panel, by remote control (IR or RF), and a RS232 port in a 3.5mm headphone Jack

!!! warning
    Audio was not tested, it is assumed to be non-functional

## Connections

1. Make a custom RS232 cable with a 3.5mm headphone jack. See the pin definition at below table

    | Pin | Definition (From host prospective) |
    | ---| ---|
    | Top | RX |
    | Middle | TX |
    | Bottom | GND |

2. Connect the HDMI out from the KVM switch to the Raspberry Pi CSI-2 to HDMI input.

3. Connect host USB and HDMI cables from the KVM switch to the machines to be managed per the switch instructions.

4. Connect the RS232 port to Raspberry Pi via USB to serial bridge or TTL to RS232 Converter

## Serial port control protocol

 !!! info
    This KVM switch does not have serial command to query active port. Also, it does not send notify message to serial when switching port by using panel button or IR remote. So the LED in Web UI will not sync if the port was switched in these 2 ways.

|Action|Command|
|---|---|
|Switch to port 1|0xfe 0x00 0x33 0x31 0xaa|
|Switch to port 2|0xfe 0x00 0x33 0x32 0xaa|
|Switch to port 3|0xfe 0x00 0x33 0x33 0xaa|
|Switch to port 4|0xfe 0x00 0x33 0x34 0xaa|

## Adding UI elements to control the KVM switch

The UI can be updated to add buttons to switch between KVM inputs and indicators for which input is currently selected.  The instructions below will make these available in the PiKVM UI after clicking the "GPIO" menu button in the KVM view.

1. SSH into PiKVM

2. Enable read-write mode on the sd card via `rw`

3. Edit the `/etc/kvmd/override.yaml` file and include the following. 

   | Method   | Device         |
   |----------|----------------|
   | USB to RS232 Bridge   | `/dev/ttyUSB0` |
   | TTL to RS232 Converter | `/dev/ttyAMA0` |

   ```yaml
   kvmd:
       gpio:
           drivers:
               hk:
                   type: gz_hk401x
                   device: /dev/ttyUSB0
           scheme:
               ch0_led:
                   driver: hk
                   pin: 0
                   mode: input
               ch1_led:
                   driver: hk
                   pin: 1
                   mode: input
               ch2_led:
                   driver: hk
                   pin: 2
                   mode: input
               ch3_led:
                   driver: hk
                   pin: 3
                   mode: input
               ch0_button:
                   driver: hk
                   pin: 0
                   mode: output
                   switch: false
               ch1_button:
                   driver: hk
                   pin: 1
                   mode: output
                   switch: false
               ch2_button:
                   driver: hk
                   pin: 2
                   mode: output
                   switch: false
               ch3_button:
                   driver: hk
                   pin: 3
                   mode: output
                   switch: false
           view:
               table:
                   - ["#Input 1", ch0_led, ch0_button]
                   - ["#Input 2", ch1_led, ch1_button]
                   - ["#Input 3", ch2_led, ch2_button]
                   - ["#Input 4", ch3_led, ch3_button]
   ```

4. Return to read-only mode for the sd card via `ro`

5. Restart the kvmd service: `systemctl restart kvmd`

## Switching between hosts in the UI

To switch between hosts, enter the KVM UI and click the "GPIO" menu. You should see 4 inputs, one of which will have a green circle indicating it is currently selected. Click the other inputs to change the selected host.

## Regarding HDMI Backpower

This KVM switch have the HDMI backpower issue. You can use either the solutions in [Multiport KVM over IP](https://docs.pikvm.org/multiport/). Or use the below solution (Need a hot air rework station).

1. Remove the diode marked below.
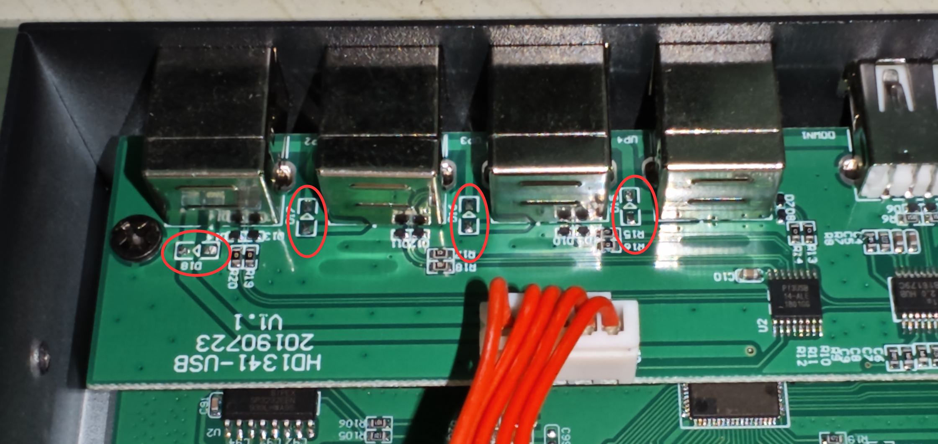
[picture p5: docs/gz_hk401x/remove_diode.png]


2. Use USB to DC Cable to power the KVM switch by using the USB port on the Pi

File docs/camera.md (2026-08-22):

---
title: Web Camera on PiKVM V4 and V3
description: How to setup web camera on PiKVM V4 Mini/Plus and PiKVM V3
---

Official [PiKVM V4 Mini/Plus](v4.md) and [PiKVM V3](v3.md) devices have an exclusive webcam feature.
With it, you can transfer an image from your local web camera to the remote host to use it for streaming,
video calls, debugging, and so on.

The host sees the virtual camera as a completely ordinary USB device which doesn't require any special drivers.
The maximum supported resolution at present is 1280x720.

If you also want enable a microphone for video calls and other applications,
after this instruction, please follow [here](audio.md#microphone-outgoing-audio).

!!! warning "Limitations"

    By installing the `ucamera` (follows), you agree that it will be used only on official [PiKVM V3](v3.md) and [PiKVM V4](v4.md) devices.

    We put a lot of effort into making this feature possible, so we want to keep it exclusive to PiKVM for a certain period.
    After that, we will publish the full source code of `ucamera` under GPLv3.

    Please note that this feature is in early access. Using the camera may cause PiKVM to fail.
    This is not fatal for PiKVM V3 and V4 since they have a robust hardware watchdog
    which reboot your device after a fail, but just remember that not everything can work perfectly.

    If you encounter a problem, we will be glad to receive your bug report to fix it:
    use our [support chat](https://pikvm.org/support) or [GitHub Issues](https://github.com/pikvm/pikvm/issues).

-----
## Enabling the camera

{!_usb_limits.md!}

??? info "A recommended hardware modification for PiKVM V3"

    [PiKVM V3](v3.md) is a good old workhorse that was not designed for the kind of computing loads that the camera provides.
    It was released many years ago and was made for completely different requirements.
    However, we want V3 users to be able to enjoy our latest features as long as possible.

    A cooling system fan is installed inside V3, but there is no radiator on the CPU since it was simply not needed.

    Using the camera uses a lot of hardware blocks that we haven't used before,
    so in order to avoid potential overheating (if the fan is turned off or fails),
    we recommend [buying and attaching additional heatsinks](https://www.pishop.us/product/aluminum-heatsink-for-raspberry-pi-4b-3-pack/).

    Both PiKVM V4 contains a good heatsink inside, so no modifications are required.

1. Perform OS update:

    {!_update_os.md!}

2. Switch filesystem to RW-mode:

    ```console
    [root@pikvm ~]# rw
    ```

3. Install `ucamera` package:

    ```console
    [root@pikvm ~]# pacman -S ucamera
    ```

3. Add a config to `/etc/kvmd/override.yaml`:

    ```yaml
    otg:
        devices:
            camera:
                enabled: true
    ```

5. Add parameter `gpu_freq=700` to `/boot/config.txt` **on a separate line**.

6. Add parameter `isolcpus=3` to `/boot/cmdline.txt` **to the end of existing one-line**, separate with a space.

4. Perform reboot:

    ```console
    [root@pikvm ~]# reboot
    ```

-----
## Using the camera

To use the camera, you will need Firefox, Chrome, or Safari of the latest version,
operability on old/other browsers is not guaranteed. If you use macOS, you will have to
update macOS entirely to update Safari.

A camera is a device that is completely controlled by the host.
The host tells it when to turn on the stream and what resolution should be used.

To receive audio in the PiKVM Web UI, go to the **System** menu and switch the video mode to `WebRTC`.
Before using the camera, you need to allow the PiKVM Web UI to access it.
Enable **Multimedia** switch and enable the **Camera** switch too. You can also choose a specific device.
The settings are saved in the browser's local storage.

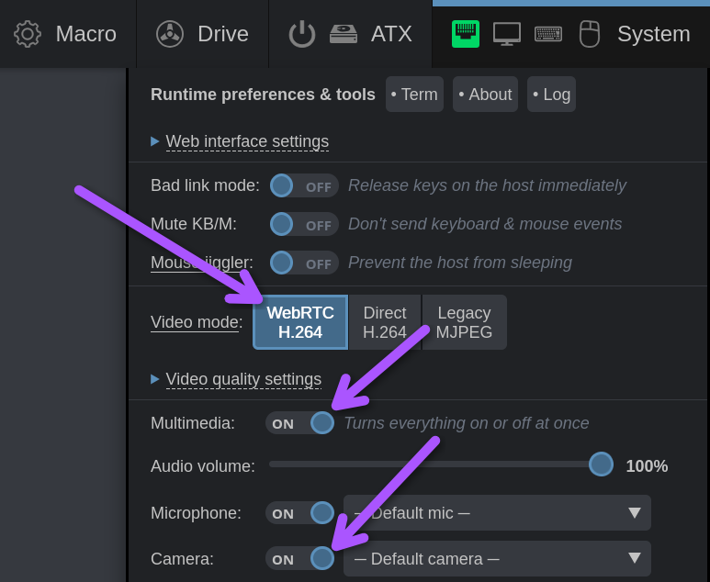
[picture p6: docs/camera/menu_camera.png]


When the host asks the PiKVM device to provide it with an image, the stream will start.

-----
## Troubleshooting

* If the browser does not play sound or does not show multimedia submenu, try a different browser
    and/or incognito mode without extensions. Firefox and Google Chrome works best.

* Check the log: `journalctl -u kvmd-janus` -u `ucamera`.

* If nothing helped, please report about the problem [to our support](https://pikvm.org/support/)

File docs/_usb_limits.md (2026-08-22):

---
search:
    exclude: true
---

!!! info "USB limitations"

    Each emulated USB device consumes a limited hardware resource called **endpoints**.
    On the default PiKVM, **you can add only one or two of additional USB devices**
    depending of its endpoint requirements.

    [See here](usb.md) to get more information about the endpoints, add devices
    and flexibly manage the configuration on the fly.

    Also note that all USB devices uses [the same USB identifiers](id.md)
    as the keyboard, mouse and other stuff.
    You can change everything together, but not separately.

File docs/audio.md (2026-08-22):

---
title: PiKVM V4 and V3 two-way audio
description: How to setup two-way audio on PiKVM V4 Mini/Plus and PiKVM V3
---

Official [PiKVM V4 Mini/Plus](v4.md) and [PiKVM V3](v3.md) devices have an exclusive audio transmission feature,
including **two-way** communication with microphone directly in the browser.

The incoming stream is captured from the target host via HDMI, the outgoing stream is transmitted to an emulated USB microphone.
This brings the user experience of working with voice applications on the remote host even closer to the local one.

!!! note

    * Audio does not work with DIY devices, either CSI or USB video dongles.

    * [VNC](vnc.md) does not support audio, it only works in the Web UI in [WebRTC](video.md) mode.

-----
## Speakers (incoming audio)

* On [PiKVM V4 Mini and Plus](v4.md), this feature is enabled by default, unless you didn't disable it [with custom EDID](edid.md).

* On [PiKVM V3](v3.md), this is disabled for historical reasons so as not to break old user's configurations
    that was created before audio support was introduced.

    ??? example "Enabling audio on PiKVM V3"

        1. Make sure that you have not removed the [audio jumpers (4)](v3.md#io-ports-and-jumpers)
            on the V3 HAT board and have not deleted or commented the `dtoverlay=tc358743-audio`
            line in `/boot/config.txt`. Return everything as it was, if you changed it.

        2. Update OS and reboot:

            {!_update_os.md!}

        3. Enable the Basic Audio support in the [EDID](edid.md) in the `/etc/kvmd/tc358743-edid.hex` and reboot the device again:

            ```console
            [root@pikvm ~]# rw
            [root@pikvm ~]# kvmd-edidconf --set-audio=yes
            [root@pikvm ~]# reboot
            ```

The target host determines whether it is possible to output audio via HDMI. Each OS does this in its own way.
In general, make sure that the audio output is HDMI in the mixer.
PiKVM supports stereo mode with any standard bits and frequencies like 32/44.1/48 kHz with 16/24 bit.

* **Mac OS** usually understands the priority of HDMI for audio output on its own,
    but you can specify this explicitly in the settings.

* **Windows** requires explicit specifying of the audio output device.

* In **Linux**, everything depends on the distribution you use. In ancient times, the audio required performing
    a ritual dance under the full Moon. For now, a working Pipewire or Pulseaudio most likely be enough.
    Just specify HDMI as the audio sink in the mixer.

To receive audio in the PiKVM Web UI, go to the **System** menu and switch the video mode to `WebRTC`.
If everything is in order, the multimedia section will appear. Set the **Multimedia** switch on,
and and just the volume for non-zero value.
The video stream will restart and you should start hearing sounds from the target host.

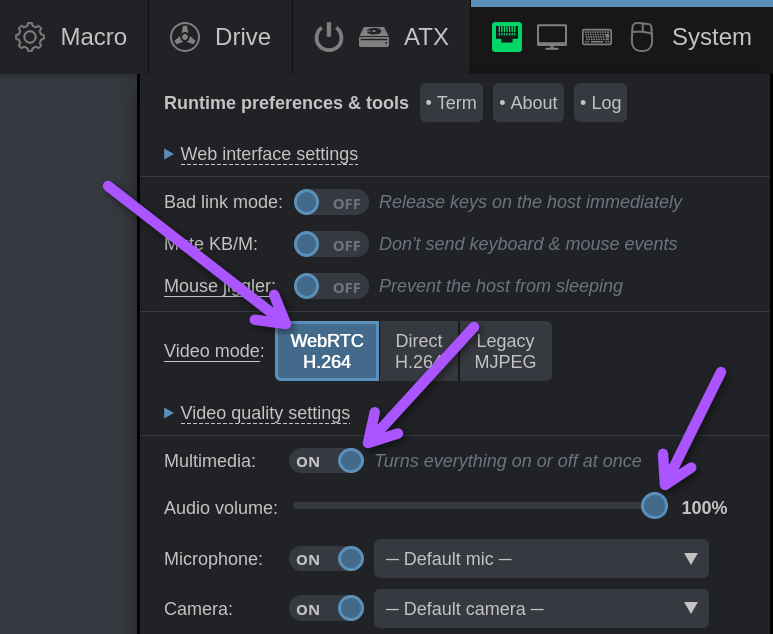
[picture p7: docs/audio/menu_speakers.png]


If the volume slider is set to zero, PiKVM does not accept the audio stream to save traffic,
while the target host will still assume that the audio output to HDMI is available.

-----
## Microphone (outgoing audio)

PiKVM [V3](v3.md) and [V4](v4.md) is able to emulate a USB microphone on the target host to transmit
your speech from the browser to the host.

If you also want enable a webcam for video calls and other applications,
after this instruction, please follow [here](camera.md).

{!_usb_limits.md!}

??? example "Enabling USB Microphone"

    1. Microphone requires speakers support so check the previous paragraph. Also perform OS updating and reboot if you didn't:

        {!_update_os.md!}

    2. Switch filesystem to RW-mode:

        ```console
        [root@pikvm ~]# rw
        ```

    3. Add a config to `/etc/kvmd/override.yaml`:

        ```yaml
        otg:
            devices:
                audio:
                    enabled: true
        ```

    4. Perform reboot:

        ```console
        [root@pikvm ~]# reboot
        ```

To receive audio in the PiKVM Web UI, go to the **System** menu and switch the video mode to `WebRTC`.
Before using the microphone, you need to allow the PiKVM Web UI to access it.
Enable **Multimedia** switch and enable the **Microphone** switch too. You can also choose a specific device.
The settings are saved in the browser's local storage.

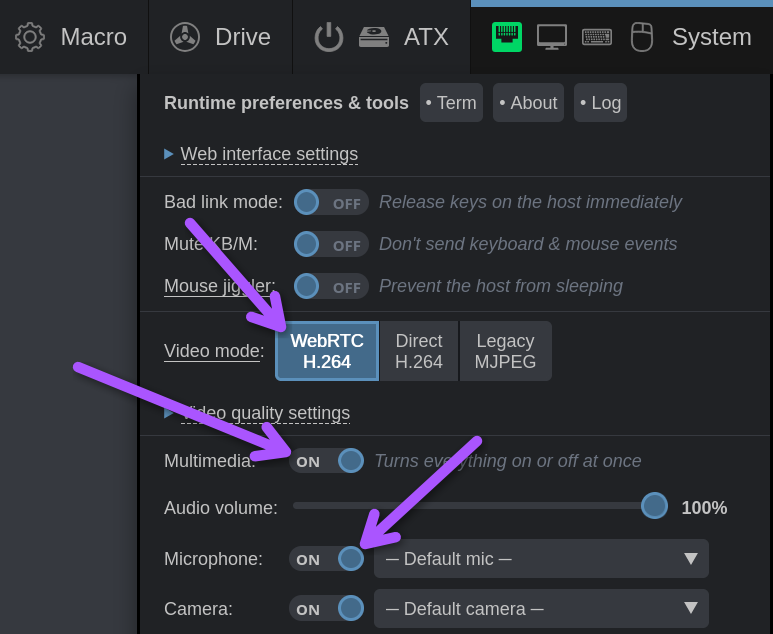
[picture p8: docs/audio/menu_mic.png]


-----
## Troubleshooting

* If the browser does not play sound or does not show audio slider, try a different browser
    and/or incognito mode without extensions. Firefox and Google Chrome works best.

* Check the log: `journalctl -u kvmd-janus`.

* If nothing helped, please report about the problem [to our support](https://pikvm.org/support/)

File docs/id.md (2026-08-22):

---
title: Identifying PiKVM on the target host
description: How PiKVM is presented to the target host's operating system, and how this can be changed
---

This page explains how PiKVM is presented to the target host's operating
system, and how this can be changed. This is useful for developers,
testers and system administrators who need PiKVM to emulate a specific
USB device or monitor.

!!! tip

    Before exploring this page, we recommend to read the [PiKVM configuration guide](config.md)
    so that you understand the terminology and how exactly the parameters described below change.

-----
## Basics

PiKVM is a combined emulator of several devices for user interaction.
Simply put, your host sees the connected PiKVM not just as a single device, but as a set of multiple devices.

In the most default case out of the box, these are the following:

- HDMI video display;
- USB keyboard;
- USB mouse (two mice for [PiKVM V4](v4.md));
- USB mass storage drive (ejectable);

Thus, PiKVM emulates two types of devices: HDMI and USB. Each of them has a specific set of identifiers.
For example, if you go to monitor settings on the host, you will see something like `PiKVM V4 Plus`.
It works in a similar way with USB.

-----
## Replicating setups

Using PiKVM utilities, you can replicate the entire IDs of peripheral devices in automatic or manual way.

* [PiKVM V4 Plus](v4.md) is able to import and adopt both EDID and USB IDs directly from your physical display and some USB device.
* [PiKVM V4 Mini](v4.md) doesn't have HDMI output and extra USB, but you can change configuration manually.
* [PiKVM V3](v3.md) or [DIY V2](v2.md) is able to import USB IDs, but not EDID.

**Both automatic and manual paths are fully described later on this page.**

-----
## HDMI Identifiers

The EDID (Extended Display Identification Data) is responsible for presenting the display.
It also provides the host with information about the resolutions that PiKVM supports.
More information about this is written on the [EDID guide](edid.md), and here we will provide brief information.

Please note that this applies to [PiKVM V3](v3.md), [V4](v4.md) and DIY based on CSI bridge.
It is impossible to change the EDID for the HDMI-USB dongle.

{!_edidconf_options.md!}

For a detailed guide on customizing EDID identifiers, please visit the [EDID guide](edid.md).

-----
## USB Identifiers

What is described here concerns only the USB identifiers, not the device structure.
Your typical PiKVM setup is recognized as a keyboard with a built-in mouse and flash drive.
If you encounter USB compatibility issues due to legacy OS or buggy drivers on the target host,
there are two things you can do:

  * Change USB identifiers (described further);
  * [Disable some of emulated devices to simplify the device structure](usb.md).
    For example, keep only keyboard and one mouse (for example, this is useful for buggy UEFI on DELL and HP),
    and disable Mass Storage and other devices.

Please note that this applies to PiKVM V2+. Identifiers on V1 and/or the [Pico HID](pico_hid.md) can't be changed
without recompilation and reflashing of the firmware.

!!! tip "Quick USB IDs changing"

    All PiKVMs (except DIY based on Zero W) have a simple way to read and adopt USB identifiers
    from a physical USB keyboard or mouse connected to any USB port. This way, the target host
    will recognize PiKVM as your regular USB device.

    To adopt USB identifiers, connect a keyboard or mouse to PiKVM and run these commands:

    ```console
    [root@pikvm ~]# rw
    [root@pikvm ~]# kvmd-otgconf --import-usb-ids
    [root@pikvm ~]# reboot
    ```

    Now the device can be unplugged. PiKVM will remember the new settings (in `/etc/kvmd/override.yaml`)
    and apply them after reboot (the last command).

As you may have found out from the [PiKVM configuration guide](config.md) (if you haven't read it yet, now is the time),
you can get the list of all configuration parameters using the `kvmd -m` command.

Below is a listing of all the parameters, from which the unrelated and those USB parameters
that should not be changed have been removed. In the context of identifiers, we are interested in the following:

```yaml
[root@pikvm ~]# kvmd -m
otg:
    vendor_id: 7531
    product_id: 260
    manufacturer: PiKVM
    product: PiKVM Composite Device
    serial: CAFEBABE
    device_version: -1
    max_power: 250

    devices:
        drives:
            default:
                inquiry_string:
                    cdrom:
                        vendor: PiKVM
                        product: Optical Drive
                        revision: '1.00'

                    flash:
                        vendor: PiKVM
                        product: Flash Drive
                        revision: '1.00'

        msd:
            default:
                inquiry_string:
                    cdrom:
                        vendor: PiKVM
                        product: Optical Drive
                        revision: '1.00'

                    flash:
                        vendor: PiKVM
                        product: Flash Drive
                        revision: '1.00'
```

Pay attention to the nesting levels. The parameters are always located in certain sections.
All numeric values are displayed in decimal form, but in the config you can use a hex form.
The generally accepted names from the USB specifications are shown too.

| Parameter | USB Spec | Description |
|---|---|---|
| `vendor_id` | `idVendor` | Unique [vendor ID](https://usb.org/sites/default/files/vendor_ids051920_0.pdf) assigned by USB.org. |
| `product_id` | `idProduct` | Just an ID for the product assigned by this vendor. |
| `manufacturer` | `iManufacturer` to 0x409 | ASCII name of the vendor. |
| `product` | `iProduct` to 0x409 | ASCII name of the product. |
| `serial` | `iSerialNumber` to 0x409 | ASCII serial number of the product. |
| `device_version` | `bcdDevice` | Kinda the revision of the device. Assigned automatically. It can be changed to 256, 257, 258 or something like this |

These IDs are also used for the [microphone](audio.md#microphone-outgoing-audio) and [camera](camera.md) on PiKVM V3 and V4.

The strings under `otg/drives` and `otg/msd` sections deserve a special description.
They relate to virtual media emulation and are separate parts of the SCSI inquiry string, the drive identifier used by the OS driver.
All three parameters `vendor`, `product`, and `revision` are short ASCII strings responsible for CD/DVD or Flash representation.

The `msd` refers to a virtual drive accessible from the Web UI,
and the `drives` describes all additional drives if you have configured them (disabled by default).
Note that mass storage drive can be [completely disabled](msd.md#disabling-mass-storage).

To change the parameters, use the `/etc/kvmd/override.yaml`, for example, like this:

```yaml
otg:
    vendor_id: 0x6940
    product_id: 0x6973
    manufacturer: Corsair
    product: Gaming RGB
    serial: 1000

    devices:
        msd:
            default:
                inquiry_string:
                    cdrom:
                        vendor: Corsair
                        product: DVD
                        revision: '1.00'

                    flash:
                        vendor: Corsair
                        product: STICK
                        revision: '1.00'
```

After changing validate the config using `kvmd -M`. You will see a list with your changes and default values,
or a message about configuration error.

If everything is fine, perform the soft `reboot` command.

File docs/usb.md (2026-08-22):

---
title: USB configuration
description: How USB works on the PiKVM, what endpoints are available, and how to configure it
---

PiKVM V2+ emulates a small set of USB devices to ensure normal
operation: a keyboard, [mouse](mouse.md) and [mass storage
drive](msd.md). However, the possibilities are not limited to this.
Optionally, you can add a [USB ethernet](usb_ethernet.md), [serial
port](usb_serial.md), or (exclusive to [PiKVM V3](v3.md) and [V4
Mini/Plus](v4.md)) [a microphone to support two-way audio](audio.md).

In rare cases, the target host's BIOS/UEFI may not understand such a
large number of emulated devices on single USB port, and some of them
may need to be disabled.

A complete USB configuration changing (adding or removing devices)
requires a reboot, but it is possible to temporarily disable and then
re-enable existing emulated devices in preset.

-----
## Basics

For information on how emulated devices are represented on the target host
and how to change USB identifiers, please see [this page](id.md).

Each emulated USB device consumes a limited hardware resource called **endpoints**.
Depending on the device, the number of required endpoints varies:

| Device | Endpoints |
|---|---|
| Keyboard, mouse | 1 for each |
| Mass Storage Drive | 2 for each |
| USB Microphone | 2 |
| USB Web Camera | 2 |
| USB Ethernet, USB Serial | 3 for each |

**In total, PiKVM provides 9 endpoints for USB emulation**, some of which are used by default:

* PiKVM V2-V3 emulates one absolute mouse and one mass storage and uses 4 of 9 endpoints.

* PiKVM V4 Mini/Plus also adds a relative mouse by default so it uses 5 of 9 endpoints.

You can add other devices remaining endpoints, disable existing ones
at all to free some endpoints, or do this only temporarily.

Moreover, you can configure the preset with a large number of devices
(more than PiKVM allows by endpoints), and then dynamically enable only
the necessary ones.

If you have configured too many devices that consume more than
9 endpoints in total, the least important of them will be inactive.
You can enable them using dynamic configuration.

To configure additional devices, please refer to the corresponding pages:

* [USB Microphone](audio.md) - Two-way audio communication for voice
  applications on the target host. Exclusive to [PiKVM V3](v3.md) and [V4 Mini/Plus](v4.md).

* [USB Web Camera](camera.md) - Two-way video with web camera for video
  calls from the target host and much more. Exclusive to [PiKVM V3](v3.md) and [V4 Mini/Plus](v4.md).

* [Absolute and relative mouse](mouse.md) - The most convenient type
  of mouse is an absolute mouse, but some BIOSes may not understand it.
  In this case, the relative one will help you.

* [USB Ethernet](usb_ethernet.md) - An FTP or Samba server on PiKVM
  can be configured, and the target host will see this over the network.
  It is also possible that PiKVM can work as a router to connect a host
  to a big network.

* [USB Serial Port](usb_serial.md) - It can be used for terminal access
  from the target host to the PiKVM, or for any other purpose that
  requires a serial connection.

-----
## Default preset

Device setup includes two stages: adding to config and starting.

When you add a device as described on the pages above, it automatically
turns on after PiKVM reboot and becomes available on the target device.
This behaviour can be changed: the device will be created, but not
active until you turn it on dynamically.

The `/etc/kvmd/override.yaml` file is used for such changes. In the following example,
there are [USB Serial Port](usb_serial.md) and [Microphone](audio.md) enabled,
but the serial port is not started by default:

```yaml
otg:
    devices:
        serial:
            enabled: true
            start: false
        audio:
            enabled: true
```

The `start` parameter is also available for all USB devices, see `kvmd -m` for the entire configuration tree.

## Dynamic configuration

### Command-line utility

The `kvmd-otgconf` utility allows you to view and modify the USB configuration on the fly.

It will also inform you about the number of endpoints used.

Changing requires root permissions.

Let's take a look at the configuration:

```console
[root@pikvm ~]# kvmd-otgconf 
# Endpoints used: 5 of 9
# Endpoints free: 4
+ hid.usb0  # [1]  Keyboard  # otg/devices/hid/keyboard/start
+ hid.usb1  # [1]  Absolute Mouse  # otg/devices/hid/mouse/start
+ hid.usb2  # [1]  Relative Mouse  # otg/devices/hid/mouse_alt/start
+ mass_storage.usb0  # [2]  Mass Storage Drive  # otg/devices/msd/start
```

Each line represents an emulated device, left to right:

* Plus or minus sign: the state (enabled or not).
* The device name (e.g., `hid.usb0`).
* The number of required endpoints (e.g., `[2]`).
* The description (e.g., `Absolute mouse`).
* Path to the relevant configuration parameter (e.g., `otg/devices/hid/mouse/start`) you can use to boot or not boot a service when `kvmd` launches.

Sometimes it's impossible to get into the UEFI/BIOS due to their bugs
in USB support, and you need to boot from the PiKVM mass storage.

In this case, you can disable all devices except keyboard and relative
mouse, and enter the BIOS:

```console
[root@pikvm ~]# kvmd-otgconf -d mass_storage.usb0 uac2.usb0 hid.usb1
# Endpoints used: 2 of 9
# Endpoints free: 7
+ hid.usb0  # [1]  Keyboard  # otg/devices/hid/keyboard/start
- hid.usb1  # [1]  Absolute Mouse  # otg/devices/hid/mouse/start
+ hid.usb2  # [1]  Relative Mouse  # otg/devices/hid/mouse_alt/start
- mass_storage.usb0  # [2]  Mass Storage Drive  # otg/devices/msd/start
```

Then change the boot order in the BIOS by setting the USB sticks
as first priority.

Exit the BIOS, and turn on mass storage again. Use it as usual to boot
the image from PiKVM mass storage:

```console
[root@pikvm ~]# kvmd-otgconf -e mass_storage.usb0
# Endpoints used: 4 of 9
# Endpoints free: 5
+ hid.usb0  # [1]  Keyboard  # otg/devices/hid/keyboard/start
- hid.usb1  # [1]  Absolute Mouse  # otg/devices/hid/mouse/start
+ hid.usb2  # [1]  Relative Mouse  # otg/devices/hid/mouse_alt/start
+ mass_storage.usb0  # [2]  Mass Storage Drive  # otg/devices/msd/start
```

You can also enable `uac2.usb0` and `hid.usb1` again.

### Web UI menu

Using the pseudo-GPIO driver, you can USB control devices via the menu in the web interface.
Read about GPIO basics [here](gpio.md).

To setup the menu, use `kvmd-otgconf --make-gpio-config` to generate the configuration, and merge it
with your existing one in `/etc/kvmd/override.yaml` in a usual way.

??? example "The example of `kvmd-otgconf --make-gpio-config` output"
    ```yaml
    # kvmd-otgconf --make-gpio-config
    kvmd:
        gpio:
            drivers:
                otgconf:
                    type: otgconf
            scheme:
                hid.usb0:
                    driver: otgconf
                    mode: output
                    pin: hid.usb0
                    pulse: false
                hid.usb1:
                    driver: otgconf
                    mode: output
                    pin: hid.usb1
                    pulse: false
                hid.usb2:
                    driver: otgconf
                    mode: output
                    pin: hid.usb2
                    pulse: false
                mass_storage.usb0:
                    driver: otgconf
                    mode: output
                    pin: mass_storage.usb0
                    pulse: false
            view:
                table:
                    - ["#Keyboard", "#hid.usb0", hid.usb0]
                    - ["#Absolute Mouse", "#hid.usb1", hid.usb1]
                    - ["#Relative Mouse", "#hid.usb2", hid.usb2]
                    - ["#Mass Storage Drive", "#mass_storage.usb0", mass_storage.usb0]
    ```

Please note that this menu is not dynamically generated, you need
to update the configuration if you added or deleted devices.

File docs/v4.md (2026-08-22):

---
title: PiKVM V4 Mini & Plus quickstart guide
description: Getting started with PiKVM V4 Mini & Plus
---

# PiKVM V4 Mini & Plus quickstart guide

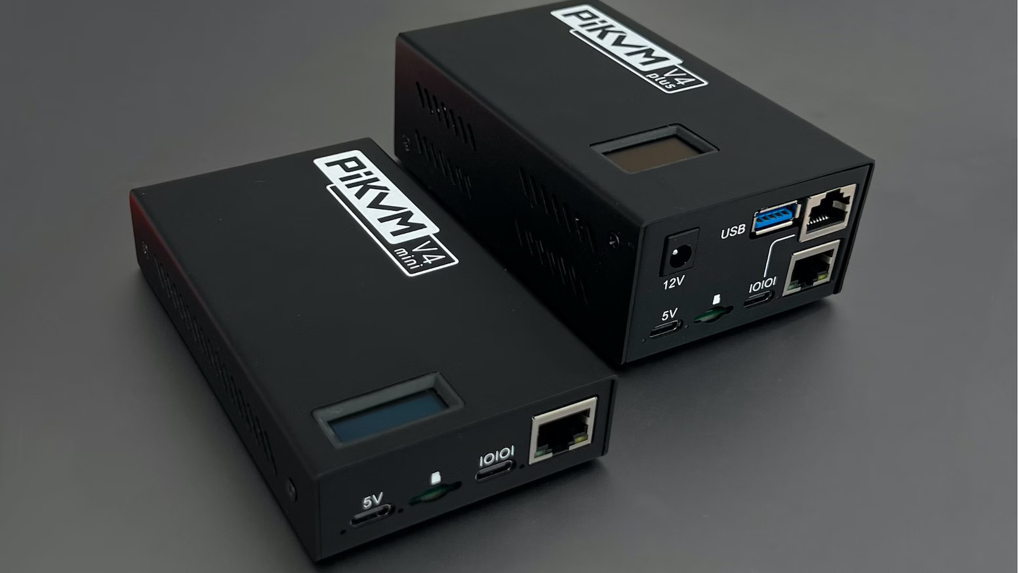
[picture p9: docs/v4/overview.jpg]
PiKVM V4 Mini & Plus PiKVM V4 Mini (left) & Plus (right)


PiKVM is a feature-rich, production-grade, open-source, Raspberry Pi based KVM-over-IP device. It allows you to turn your computer on or off, restart it, configure the UEFI/BIOS, and even reinstall the OS using the Virtual CD-ROM or flash drive.

PiKVM uses your remote keyboard and mouse to simulate a local keyboard, mouse, and monitor, which are then presented in a web browser as if you were working on a remote system directly.

**Datasheets**:

[PiKVM V4 Mini](v4mini_datasheet.pdf){ .md-button } [PiKVM V4 Plus](v4plus_datasheet.pdf){ .md-button }

-----
## What's in the box

- PiKVM V4 Mini or Plus device
- Micro SD card with pre-imaged PiKVM software
- ATX control board
- ATX connection cables
- ATX installation brackets
- 1 x Ethernet cable
- 1 x ATX cable
- 1 x USB C to USB A cable
- 12V 2A Power Supply (international adapters)

-----
## Interface

=== "Front view"

    V4 front view

    1. Power LED (Green)
    2. Power Input 5.1V 3A
    3. Activity LED (Red)
    4. Micro SD card slot
    5. USB 2.0 Serial console port
    6. Serial console active LED / Beacon LED (Green)
    7. RJ45 1Gb Ethernet port
    8. RJ45 Serial console port **(V4 Plus only)**
    9. USB 3.0 port 1 **(V4 Plus only)**
    10. Power Input 12V 2A **(V4 Plus only)**

=== "Rear view"

    V4 rear view

    1. RJ45 ATX control port
    2. USB 2.0 OTG connector
    3. Beacon LED
    4. Video source ready status LED
    5. HDMI video input port
    6. Video capture ready status LED
    7. Optional antenna mounting hole **(only one in V4 Mini)**
    8. HDMI video output port 2 **(V4 Plus only)**
    9. HDMI video output port 1 **(V4 Plus only)**
    10. USB 3.0 port 2 **(V4 Plus only)**
    11. Optional antenna mounting hole **(only one in V4 Mini)**

=== "Right view"

    V4 right view

    1. Service switches
    2. Kensington Security Slot

=== "Top view"

    V4 top view

    1. Display

-----
## Flashing the OS

Most of the time, this step is not necessary. However, if there is a possibility that your device had a previous owner (e.g. "Used - Like New" on Amazon), we recommend reflashing the OS to ensure a clean start. Please follow [this guide](flashing_os.md).

-----
## Wiring

Let's connect all the wires before you power up the device.

### Network

Ethernet wiring

Connect **Ethernet** (**bottom right** on the **front** side) to the network using the cable from the kit. The kit includes two Ethernet cables of different colors: one for the network, the second for ATX. Use whichever one you like best.

### HDMI and USB-C

HDMI and USB-C wiring

**HDMI input** (the **bottom right** on the **rear** side) and **OTG** port (USB emulation) should be connected to the computer.

Optionally, the **[ATX port](atx_board.md)** can be connected to control the power. There should be no USB hub between PiKVM and the computer, as some UEFI/BIOS cannot detect them at the boot stage.

-----
## Power up

Power supply wiring

V4 Mini and V4 Plus have different power supplies:

- The Mini comes with USB-C 5V power supply
- The Plus comes with with Barrel 12V

The Plus can also work from 5V. In that case, avoid creating a significant power load on USB (external flash sticks, cameras, and so on).

Attach the appropriate connector on the **front** side. Do **not** block the ventilation holes on the sides of the device.

After turning on the power, PiKVM OS generates unique SSH keys and certificates and performs all necessary operations on the memory card. It takes a few minutes. Do **not** turn off the device until it's fully booted for the first time. Once it's done, the PiKVM will show a greeting on the built-in display.

-----
## Connect and set up

### Configure the display

The operating system on your remote computer will treat PiKVM as an additional display and use it in the Extend mode by default. That's why you will see an empty desktop when you first connect.

To avoid that, go to the display settings in your remote computer's operating system and enable the mirror mode for the external screen that your operating system identifies as PiKVM. Refer to your operating system's documentation on that.

### Access PiKVM

By default, PiKVM receives a dynamic IP address via DHCP and shows it in the top row of the OLED display:

```console
192.168.0.26
(|) iface: eth0
cpu: 1% mem: 13%
```

Let's assume that PiKVM has received the address `192.168.0.26` and has also been assigned a hostname `pikvm`.

Type the URL in the browser's address bar and press **Enter**: https://192.168.0.26/ or https://pikvm/.

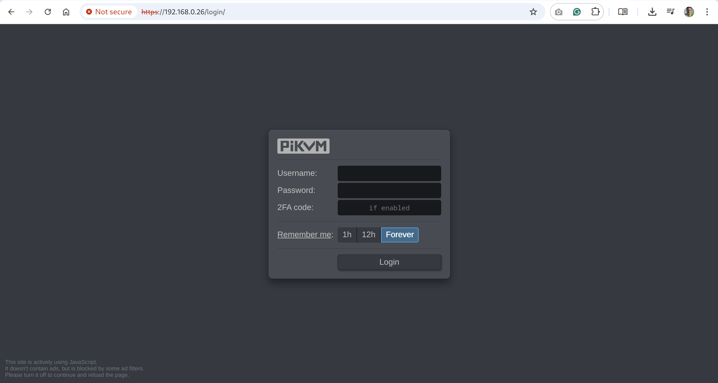
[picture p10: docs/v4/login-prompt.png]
Login screen


Submit the default credentials and click **Login**:

- Username: `admin`
- Password: `admin`
- 2FA Code: disabled by default, skip this field

You will see the initial dashboard screen of the PiKVM, where you can access the remote host, connect to the PiKVM command line, or log out:

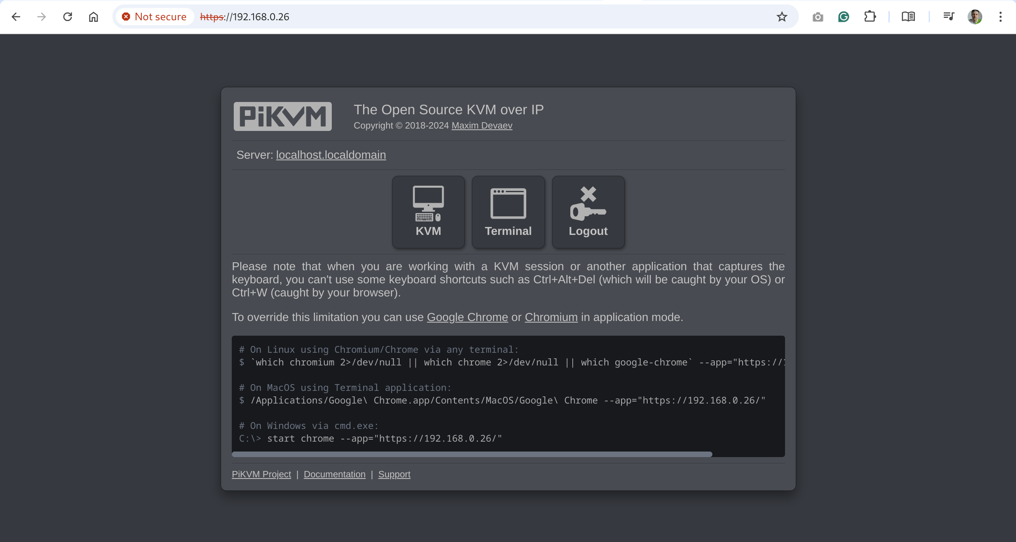
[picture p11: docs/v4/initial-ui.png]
Initial UI


### Change the default passwords

For security's sake, it's best to change the default passwords immediately after running PiKVM for the first time. 

!!! danger "Passwords are important!"
    Please ensure that you change **both** passwords: for Web UI access and for the Linux superuser (root).

To do that:

1. On the initial dashboard screen, click the **Terminal** button to open the web terminal. You will see this command line interface:

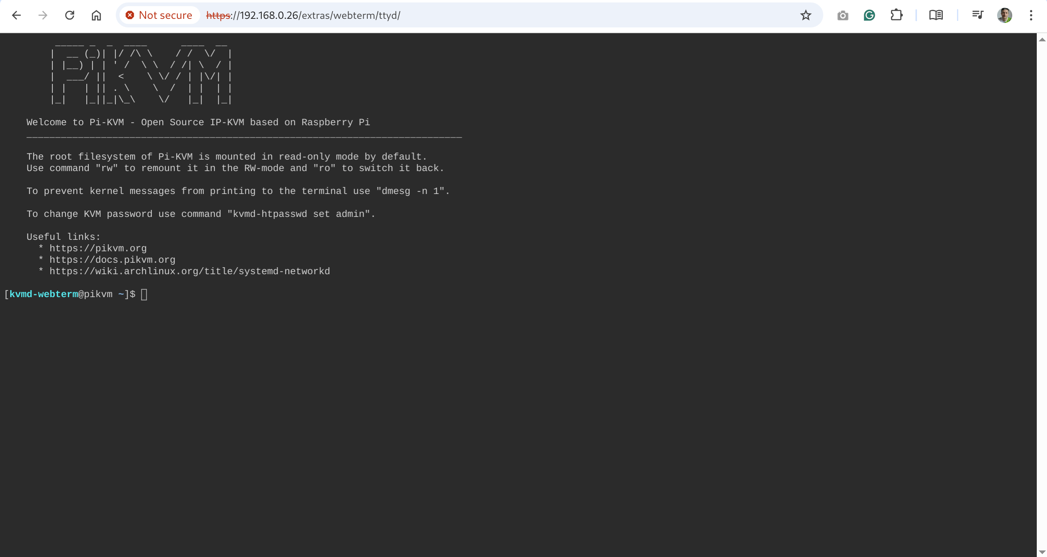
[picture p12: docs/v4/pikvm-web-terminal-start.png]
MISSING SCREENSHOT
    

2. Gain superuser privileges:

    ```console
    $ su -
    ```

    When prompted for a password, use `root`.

3. Run `rw` to change the access to the SD card to the write mode:

    ```console
    [root@pikvm ~]# rw
    ```

4. Change the password for the superuser:

    ```console
    [root@pikvm ~]# passwd root
    ```

    Submit the new password, retype it the second time to confirm, press **Enter**, and you should see this:

    ```console
    passwd: password updated successfully
    ```

5. Change the password for web access:

    ```console
    [root@pikvm ~]# kvmd-htpasswd set admin
    ```

    Submit the new password, retype it the second time to confirm, and press **Enter**.

6. Run `ro` to change the access to the SD card back to the read-only mode:

    ```console
    [root@pikvm ~]# ro
    ```

7. Press **Ctrl+D** or type "exit" and press **Enter** to drop the root privileges.

8. Go back one page in the browser. You should be back to the initial dashboard screen.

### Access the remote system

1. On the initial dashboard screen, click the **KVM** button to access the remote host.

2. You should now see the host system's display and interact with it remotely using a keyboard and a mouse.

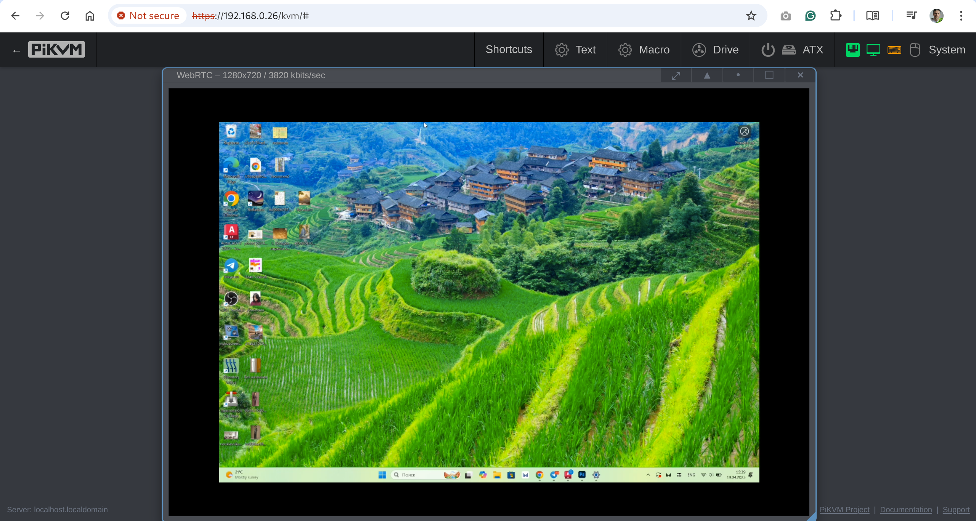
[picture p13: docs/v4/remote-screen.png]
Work remotely
    

-----
## Important next steps

- **We strongly recommend updating the PiKVM OS** after the first launch:

    {!_update_os.md!}

- Learn the basics of **PiKVM OS Configuration**: where to find configs, how to edit the, etc.

    {!_config.md!}

- **Get to know PiKVM Web UI**: read [this help section](webui.md) to better understand all the possibilities of the web user interface.

- **Configure the magic key**: define which key to use to start [sending shortcuts](shortcuts.md) to the target host system.

- **Set up an [ATX connection](atx_board.md)** if you need to control the power of the remote system.

-----
## Further recommendations

1. **Customize the system**:

    - [Harden the remote access](auth.md) by enabling 2FA.
    - Configure access to PiKVM from the Internet using [port forwarding](port_forwarding.md) or [Tailscale VPN](tailscale.md).
    - Enable a microphone for [two-way audio](audio.md).
    - Enable a web camera for [video calls and much more](camera.md).
    - Enable [HDMI pass-through](pass.md) and [USB passthrough](usb_pass.md) on V4 Plus.
    - Enable [H.264 60 fps streaming](video.md#boost-pikvm-v4-to-60fps-h264).
    - [Learn](config.md) how configuration files are structured.
    - Read how PiKVM is [identified](id.md) on the target host.

2. **Configure hardware**:

    - Install and set up the [Wi-Fi antenna](wifi.md#antenna-on-pikvm-v4).

    - Install and set up [LTE/5G modem](modem.md) (**only for PiKVM V4 Plus**).

    - Set up internal USB port for USB 3.0 (**only for PiKVM V4 Plus**):

        ??? note "Enable USB 3.0 on the internal port"

            PiKVM V4 Plus has an internal USB port. It supports USB 3.0, but only works with USB 2.0 devices by default to minimize the power consumption. You need to flash the USB controller to enable USB 3.0. To do so, follow these steps:

            1. Open a terminal window and log into the PiKVM via SSH:

                ```console
                $ ssh user@host
                ```

            2. Flash the USB controller using the built-in `flashrom` utility. Choose `usb3` for USB 3.0 support:

                ```console
                [root@pikvm ~]# flashrom-vl805 usb3
                ```

                If you need to disable USB 3.0 support at any time later, run the same command, but use `default` instead:

                ```console
                [root@pikvm ~]# flashrom-vl805 default
                ```

            3. Perform the soft reboot:

                ```console
                [root@pikvm ~]# reboot
                ```

            4. After the soft reboot, perform the **reboot by power**: unplug and plug again the power cable.

    - Learn about DIP switches:

        ??? note "DIP switches purpose"

            The left switch **[1]**:
            : When pulled down (**ON** state), the advanced backpower protection is used. On the default state is **OFF** (up), "diode protection" is used. This is required for debugging at the request of technical support. Under normal conditions, it is not necessary to change the mode.

            The right switch **[2]**:
            : When pulled down (**ON** state), the Power Delivery chip is activated on the USB OTG port. The default state is **OFF** (up).

            To change the position of switches:

            1. Turn the PiKVM off.
            2. Change the position of the switched.
            3. Turn the PiKVM on.

            !!! warning
                Do not do that change the state of the DIP switched while the device is turned on. **This may cause irreparable damage.**

    - Choose Fahrenheit over Celsius to display on the OLED:

        {!_fahrenheit.md!}

-----
## Known issues and limitations

* There may be compatibility issues with certain motherboards, such as **HP** or **DELL**. If there is no image from the BIOS, you can fine-tune the HDMI settings, but it is possible that mass storage devices may not be available in the BIOS. In the latter case, [USB dynamic configuration](usb.md) will solve the problem.

* While the V4 Plus features a Mini-PCIe slot, it was only designed for LTE modems. An NVME card will not work.

-----
## Basic troubleshooting

* Ensure that you are using the right [OS image](flashing_os.md) for your platform
    by running the following command: `pacman -Q | grep kvmd-platform`.

* If you are not getting a display, run the two following commands:

    * `dmesg | egrep 'tc35|1-1.4|uvc'`
    * `systemctl status kvmd-tc358743`

-----
## Getting user support

If something doesn't work, check out our [FAQ](faq.md). Otherwise, head straight to our [Support](https://pikvm.org/support/).

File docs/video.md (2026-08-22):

---
title: Video modes
description: Key differences between available video modes on PiKVM and tips for using them
---

# Video modes

PiKVM [V3](v3.md), [V4 Plus/Mini](v4.md) and all DIY devices based on
HDMI-CSI bridge provides three video streaming modes. This page explains
the key differences between them and helps you to achieve optimal video
performance.

The video mode can be switched in the **System** menu in the Web UI. If
you don't see the switch, probably your browser does not support H.264
video.



!!! tip "Quick tips"

    * Good network: use `WebRTC` or `Direct` mode, set `H.264 gop = 0`.

    * Bad network and `WebRTC` mode: Set `H.264 gop = 60`.

    * Bad network and `Direct` mode: Set `H.264 gop = 0`.

    * If the `WebRTC` mode is not working, try the `Direct`.

    * The `Direct` mode doesn't support audio yet. If you need audio, but `WebRTC` is not working, follow [this guide](webrtc_config.md).

-----
## Settings

* **H.264 kbps** *(Bitrate)* - with a large value, the video quality will be better, but the network traffic will increase.

* **H.264 gop** *(Group of Pictures)* - the number of frames between which a reference frame must be forcibly added.
    The recommended values are described above.

-----
## Boost PiKVM V4 to 60fps H.264

By default, the performance of PiKVM in 1080p mode is limited to 30fps, but this limitation can be lifted.
The result will be a slightly lower video [latency](latency.md) and a full 60fps stream
with a slight increase in processor temperature
(it's not critical for both [V4 Plus and Mini](v4.md), as they have a very good cooling system).
It will also double the consumption of network traffic.

!!! warning "This is ONLY for PiKVM V4"

    Don't try it on DIY or V3 devices.

??? example "Enabling H.264 boost"

    1. Perform OS updating and reboot:

        {!_update_os.md!}

    2. Switch filesystem to RW-mode:

        ```console
        [root@pikvm ~]# rw
        ```

    3. Add `gpu_freq=700` to `/boot/config.txt` as a separate line.

    4. Enable H.264 boost:

        ```console
        [root@pikvm ~]# kvmd-override --set kvmd/streamer/h264_boost=true
        ```

    5. Optional: change default FPS limit from 30 to 60 with following command:

        ```console
        [root@pikvm ~]# kvmd-override --set kvmd/streamer/desired_fps/default=60
        ```

    6. Perform reboot:

        ```console
        [root@pikvm ~]# reboot
        ```

Please don't use the boost on [PiKVM V3](v3.md) and DIY devices.

-----
## WebRTC H.264 mode

This is the default mode. It'is using the efficient H.264 encoding to
save traffic. The video is streamed over WebRTC protocol which you may
have encountered when you used video calls in Discord or Google Chat.
Since WebRTC does not use HTTP for video, establishing a connection is
quite tricky (but PiKVM automates 99% of cases). If you have problems
with the WebRTC mode, please [check this guide](webrtc_config.md).

!!! info "Advantages / Disadvantages"

    * ✅ Supported by all modern browsers.

    * ✅ Lowest latency, [fast as hell](latency.md) with `H.264 gop = 0`.

    * ✅ Provides [two-way audio](audio.md) and [web camera](camera.md) on PikVM [V3](v3.md) and [V4 Plus/Mini](v4.md).

    * ❌ The video may be lost due to a poor connection (like mobile internet, bad Wi-Fi, etc.),
        or because of the router settings, when WebRTC is given low priority.

    * ❌ It may be blocked at all in some networks.

-----
## Direct H.264 mode

The new experimental mode for real-time streaming, introduced by PiKVM.
It also uses H.264 encoding, but streams the video over regular HTTP (WebSocket).

!!! info "Advantages / Disadvantages"

    * ✅ Very stable on poor networks, better than WebRTC (based on our tests and user reviews).

    * ✅ It is not blocked by firewalls because it appears to be regular HTTPS traffic.

    * ✅ The latency is low and stable too.

    * ❌ No audio support right now (but it will), no camera.

    * ❌ Some [older browsers](https://caniuse.com/webcodecs) doesn't have the WebCodes support needed for this mode.

-----
## Legacy MJPEG mode

Good old Motion JPEG. This is the way IP cameras have been streaming videos to browsers since ancient times.
The stream is just infinite queue of JPEGs that replace each other in `<img>` HTML tag.
There is no point in using it now if one of the previous modes is working.

!!! info "Advantages / Disadvantages"

    * ✅ Sometimes the H.264 is disabled in a browser by OS license limitations (for example, in Red Had Linux or Debian).
        But MJPEG is working always.

    * ✅ It is not blocked by firewalls because it appears to be regular HTTPS traffic.

    * ✅ Low latency if you have a good network.

    * ❌ No audio and camera support.

    * ❌❌❌ Consumes a HUGE amount of traffic. No Wi-Fi, no mobile, nothing but cable connection will work.

-----
## What if H.264 is not supported by browser at all

There are some Linux distro's that require more work to be able to use H.264,
this may include any RedHat or Debian variant. Here some examples:

  * In case of Chromium on Fedora, you can connect the [RPM Fusion](https://rpmfusion.org) repo
    and then install the `chromium-freeworld` package instead of `chromium`.

  * On Debian GNU/Linux and Firefox, make sure the OpenH264 Plugin both exists and is enabled.
    Press `Ctrl+Shift+A` to open the `Add-on Manager`, then press `Plugins`. There you should see
    *OpenH264 Video Codec provided by Cisco Systems, Inc.*
    Make sure it is enabled by pressing the "more options" button (tree dots), then pressing `Always Activate`.

-----
## Video recording

At the moment, it is not possible to record videos in a convenient way from the Web UI,
but a small trick in the console can be used to record videos without sound.
It's only available on all PiKVM models which support H.264 video.

Available since KVMD 4.110

??? example "Recording video from terminal on Linux or Mac OS"

    1. Install `ffmpeg` and `websocat`.

    2. Let's assume that your PiKVM is located on `https://pikvm` and uses a self-signed certificate.
        Request the stream from it from the first opened console on your PC (not PiKVM):

        ```console
        [user@host ~]$ websocat -k wss://pikvm/api/ws?stream=1 -H X-KVMD-User:admin -H X-KVMD-Passwd:admin
        ```

    3. Keeping the previous command running, open a new terminal and run the video recording process:

        ```console
        [user@host ~]$ websocat -b -B 10000000 -k wss://pikvm/api/media/ws?video=h264 -H X-KVMD-User:admin -H X-KVMD-Passwd:admin | ffmpeg -use_wallclock_as_timestamps 1 -i pipe: -c:v copy my_captured_video.mp4
        ```

    4. Same can be done on PiKVM itself, locally.

    5. Press `Ctrl+C` to stop the recording.

??? example "Take a screenshot from terminal on PiKVM"

    To take a screenshot, switch filesystem to RW-mode like in previous example and run the stream.

    Next, take a screenshot:

    ```console
    [root@pikvm ~]# curl --unix-socket /run/kvmd/ustreamer.sock http://localhost/snapshot -o /tmp/screen.jpg
    ```

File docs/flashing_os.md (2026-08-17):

---
title: Flashing PiKVM OS image
description: How to flash a PiKVM OS image to an SD card
---

!!! warning "Micro-SD Card Requirements"

    Minimum **32 Gb, Class 10** recommended.

-----
## Download the image

Download the appropriate SD card image. Select it based on the board, platform, and the video capture device you are using.

!!! abstract "Official PiKVM Devices"

    These images are not suitable for DIY and are intended only for our branded devices.

    * **PiKVM V4** <sub>*64-bit*</sub>
        * [PiKVM V4 Mini](https://files.pikvm.org/images/v4mini-hdmi-rpi4/aarch64/v4mini-hdmi-rpi4-aarch64-latest.img.xz)
            <sub>- [*sha1*](https://files.pikvm.org/images/v4mini-hdmi-rpi4/aarch64/v4mini-hdmi-rpi4-aarch64-latest.img.xz.sha1)
        * [PiKVM V4 Plus](https://files.pikvm.org/images/v4plus-hdmi-rpi4/aarch64/v4plus-hdmi-rpi4-aarch64-latest.img.xz)
            <sub>- [*sha1*](https://files.pikvm.org/images/v4plus-hdmi-rpi4/aarch64/v4plus-hdmi-rpi4-aarch64-latest.img.xz.sha1)

    * **PiKVM V3** <sub>*64-bit*</sub>
        * [PiKVM V3 HAT BOX Image, OLED/FAN preactivated](https://files.pikvm.org/images/v3-hdmi-rpi4/aarch64/v3-hdmi-rpi4-aarch64-box-latest.img.xz)
            <sub>- [*sha1*](https://files.pikvm.org/images/v3-hdmi-rpi4/aarch64/v3-hdmi-rpi4-aarch64-box-latest.img.xz.sha1)
        * [PiKVM V3 HAT DIY Assembly](https://files.pikvm.org/images/v3-hdmi-rpi4/aarch64/v3-hdmi-rpi4-aarch64-latest.img.xz)
            <sub>- [*sha1*](https://files.pikvm.org/images/v3-hdmi-rpi4/aarch64/v3-hdmi-rpi4-aarch64-latest.img.xz.sha1)</sub>

!!! abstract "DIY PiKVM V2 Platform"

    * **Raspberry Pi 5** <sub*64-bit*</sub>
        * HDMI-CSI bridge is not supported due to lack of hardware image encoders on Pi 5.
        * [For HDMI-USB dongle](https://files.pikvm.org/images/v2-hdmiusb-rpi5/aarch64/v2-hdmiusb-rpi5-aarch64-latest.img.xz)
            <sub>- [*sha1*](https://files.pikvm.org/images/v2-hdmiusb-rpi5/aarch64/v2-hdmiusb-rpi5-aarch64-latest.img.xz.sha1)</sub>

    * **Raspberry Pi 4** <sub>*64-bit*</sub>
        * [For HDMI-CSI bridge](https://files.pikvm.org/images/v2-hdmi-rpi4/aarch64/v2-hdmi-rpi4-aarch64-latest.img.xz)
            <sub>- [*sha1*](https://files.pikvm.org/images/v2-hdmi-rpi4/aarch64/v2-hdmi-rpi4-aarch64-latest.img.xz.sha1)</sub>
        * [For HDMI-USB dongle](https://files.pikvm.org/images/v2-hdmiusb-rpi4/aarch64/v2-hdmiusb-rpi4-aarch64-latest.img.xz)
            <sub>- [*sha1*](https://files.pikvm.org/images/v2-hdmiusb-rpi4/aarch64/v2-hdmiusb-rpi4-aarch64-latest.img.xz.sha1)</sub>

    * **Raspberry Pi Zero 2 W** <sub>*32-bit*</sub>
        * [For HDMI-CSI bridge](https://files.pikvm.org/images/v2-hdmi-zero2w/arm/v2-hdmi-zero2w-arm-latest.img.xz)
            <sub>- [*sha1*](https://files.pikvm.org/images/v2-hdmi-zero2w/arm/v2-hdmi-zero2w-arm-latest.img.xz.sha1)</sub>

!!! abstract "DIY PiKVM V1 Platform"

    * **Raspberry Pi 3** <sub>*32-bit*</sub>
        * [For HDMI-CSI bridge](https://files.pikvm.org/images/v1-hdmi-rpi3/arm/v1-hdmi-rpi3-arm-latest.img.xz)
            <sub>- [*sha1*](https://files.pikvm.org/images/v1-hdmi-rpi3/arm/v1-hdmi-rpi3-arm-latest.img.xz.sha1)</sub>
        * [For HDMI-USB dongle](https://files.pikvm.org/images/v1-hdmiusb-rpi3/arm/v1-hdmiusb-rpi3-arm-latest.img.xz)
            <sub>- [*sha1*](https://files.pikvm.org/images/v1-hdmiusb-rpi3/arm/v1-hdmiusb-rpi3-arm-latest.img.xz.sha1)</sub>

    * **Raspberry Pi 2** <sub>*32-bit*</sub>
        * [For HDMI-CSI bridge](https://files.pikvm.org/images/v1-hdmi-rpi2/arm/v1-hdmi-rpi2-arm-latest.img.xz)
            <sub>- [*sha1*](https://files.pikvm.org/images/v1-hdmi-rpi2/arm/v1-hdmi-rpi2-arm-latest.img.xz.sha1)</sub>
        * [For HDMI-USB dongle](https://files.pikvm.org/images/v1-hdmiusb-rpi2/arm/v1-hdmiusb-rpi2-arm-latest.img.xz)
            <sub>- [*sha1*](https://files.pikvm.org/images/v1-hdmiusb-rpi2/arm/v1-hdmiusb-rpi2-arm-latest.img.xz.sha1)</sub>

    * **Raspberry Pi Zero 2 W** <sub>*32-bit*</sub>
        * [For HDMI-CSI bridge](https://files.pikvm.org/images/v1-hdmi-zero2w/arm/v1-hdmi-zero2w-arm-latest.img.xz)
            <sub>- [*sha1*](https://files.pikvm.org/images/v1-hdmi-zero2w/arm/v1-hdmi-zero2w-arm-latest.img.xz.sha1)</sub>
        * [For HDMI-USB dongle](https://files.pikvm.org/images/v1-hdmiusb-zero2w/arm/v1-hdmiusb-zero2w-arm-latest.img.xz)
            <sub>- [*sha1*](https://files.pikvm.org/images/v1-hdmiusb-zero2w/arm/v1-hdmiusb-zero2w-arm-latest.img.xz.sha1)</sub>

!!! abstract "Any other combinations for advanced users"
    Please check the [file archives](https://files.pikvm.org/images/) for ready-made image or [build the image yourself](building_os.md).

-----
## Flashing the image

!!! tip
    After inserting the memory card into your computer, ignore request to format. This is not necessary.

### Using Linux CLI (ADVANCED USERS)

Decompress (if necessary) and flash the image. **Be careful when choosing the device path, it may be different on your machine** (use `lsblk -dpno NAME,SIZE,MODEL`):

```console
[user@localhost]$ xz --decompress v2-hdmi-rpi4-latest.img.xz
[user@localhost]$ sudo dd if=v2-hdmi-rpi4-latest.img of=/dev/mmcblkX bs=4M status=progress conv=fsync oflag=direct
[user@localhost]$ sync
[user@localhost]$ sudo eject /dev/sdb
```

You can also use `dd_rescue` or `ddrescue`.

### Using RPi Imager (Linux, MacOS and Windows)

1. Download and install **the latest version** of [RPi Imager](https://github.com/raspberrypi/rpi-imager/releases).

2. Run RPi Imager:

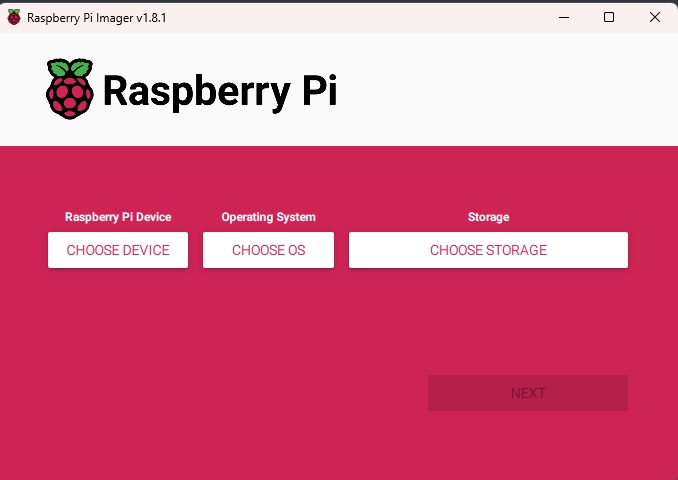
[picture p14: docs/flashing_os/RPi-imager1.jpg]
    

3. Press **NO FILTERING** then **CHOOSE OS** and select **Use custom** image at bottom of the list:

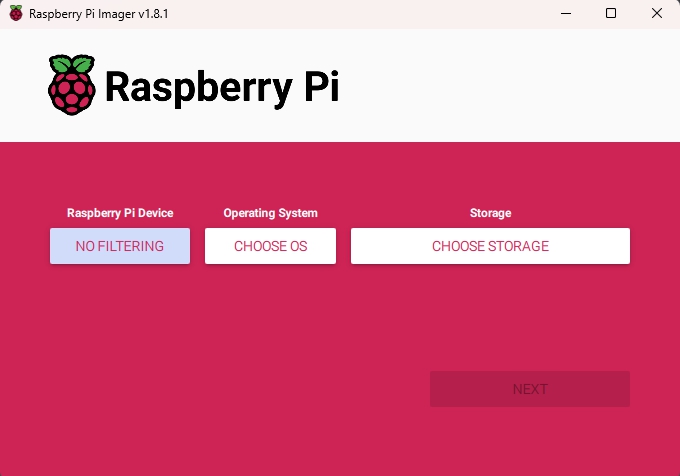
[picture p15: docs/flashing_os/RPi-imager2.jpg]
    

4. After clicking on this item, select the image file (`*.img` or `*.img.xz`), then click **CHOOSE STORAGE**:

    !!! warning
        This should already be set to blank though the flashing process from step 7 but its best to double check the advanced settings (`CTRL+SHIFT+X`), make sure they are blank or the flash will fail.

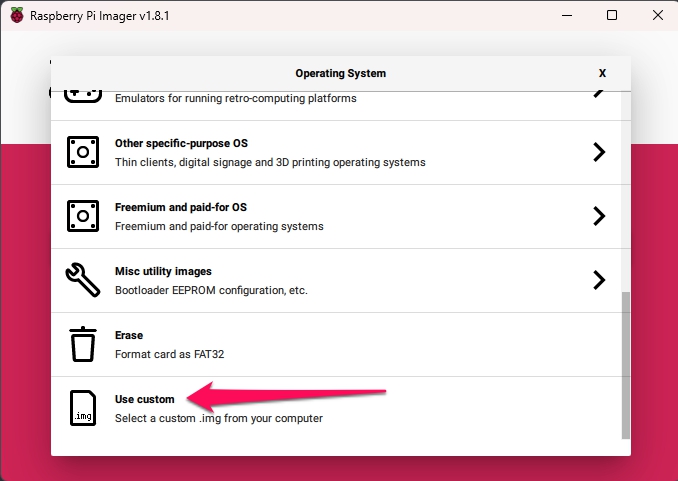
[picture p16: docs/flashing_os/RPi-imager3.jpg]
    

5. Insert the memory card into the card reader. Choose the card reader from this list. **Be careful** and choose the right device:

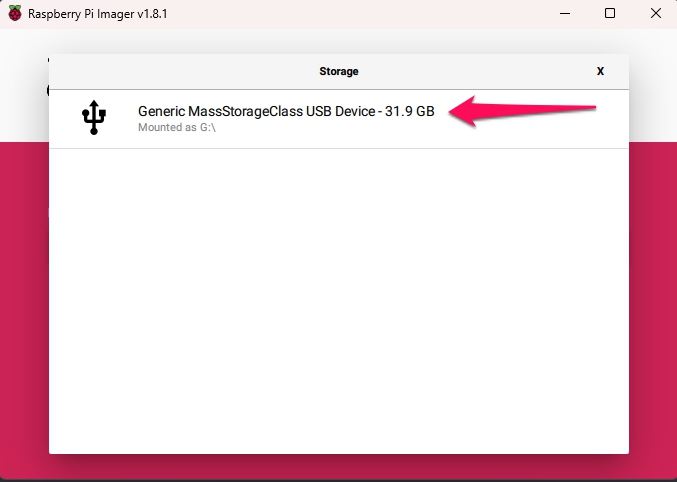
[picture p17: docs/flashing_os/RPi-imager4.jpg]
    

6. After choosing the memory card, press the **WRITE** button. Confirm the operation when you are asked about it:

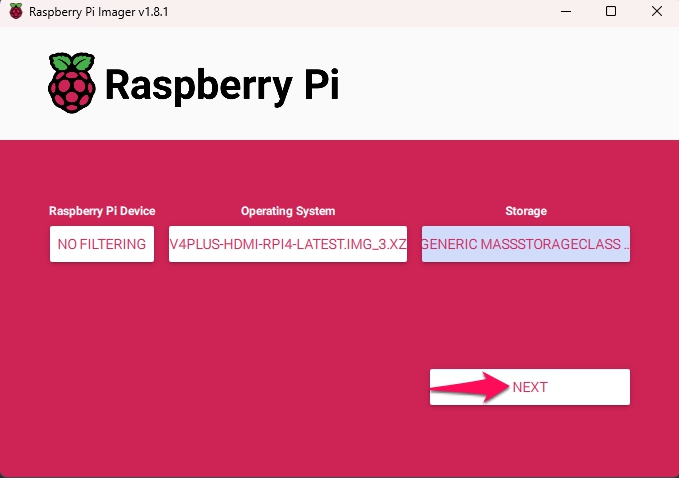
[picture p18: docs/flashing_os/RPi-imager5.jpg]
    

7. Refuse customization options.

    !!! warning

        The customization is designed for Raspberry OS and will not work in PiKVM OS.
        If you apply any custom settings, this will cause the image to malfunction.

        PiKVM OS has its [own settings mechanism](on_boot_config.md), please use it after the flashing
        if you need to configure Wi-Fi or something similar.
        
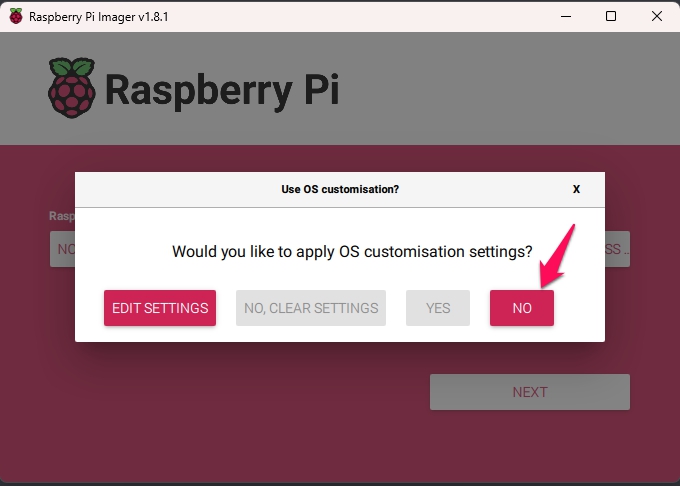
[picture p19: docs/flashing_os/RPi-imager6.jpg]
    

8. Wait for the process to finish. Get yourself a coffee or do some stretching :)
    The process may hang at 99% for a long time, this is okay, just wait for it to complete.

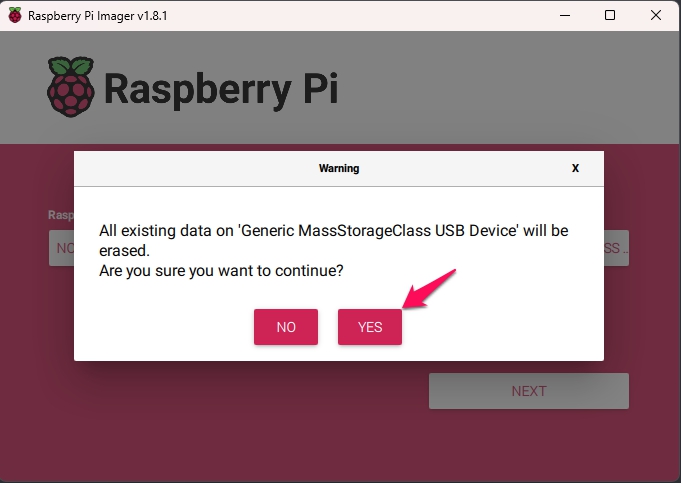
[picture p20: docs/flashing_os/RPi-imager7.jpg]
    

9. Remove the memory card after successful completion. If an error occurs during flashing or booting PiKVM, repeat the process.
    If the error persists, use a different memory card.

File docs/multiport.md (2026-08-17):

---
title: Multiport KVM-over-IP
description: If you need to connect multiple hosts to a single PiKVM, your options are PiKVM Switch and a number of 3rd-party KVMs
---

??? note
    V4 MINI can ONLY be used with the TESmart or other KVMs with LAN control, the TESmart has a convenience driver for easier setup

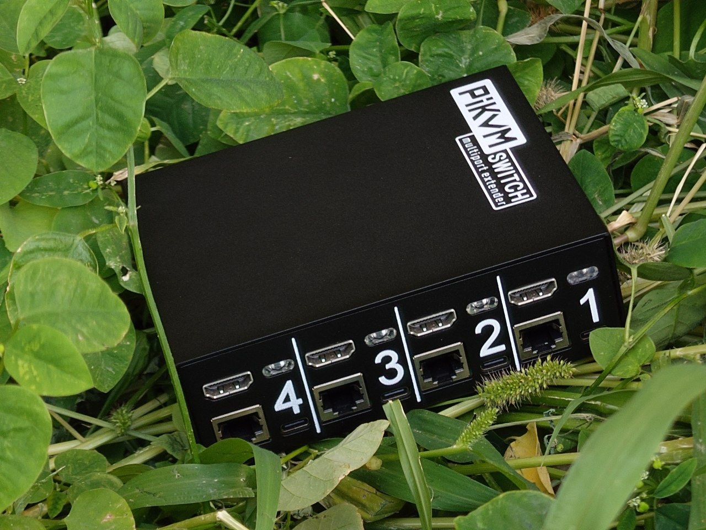
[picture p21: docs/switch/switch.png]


If you need to connect multiple hosts to a single PiKVM, then the best way to do this is to use our [PiKVM Switch](switch.md). It is designed specifically for PiKVM and has many advantages and features compared to regular desktop multiport switches.

* ATX control on each port.
* Per-port EDID configuration.
* HDMI dummy plug functionality.
* True Plug-n-Play with no need for override.yaml setups and complete control via Web UI.
* Multifunctional RGB LEDs with beacon mode and customizable color schemes.
* Firmware update directly from PiKVM and ready for future hardware extensions.
* Compatible with V4 Plus, V3 and DIY devices based on Pi2-Pi5 except Zero and V4 Mini.

And now the best part: **the switches can be chained!** Need four ports? Get a PiKVM Switch.
As your server fleet expands to eight, simply add another switch and link it to the first one.
Need even more? No worries — **connect up to five switches and enjoy 20 fully functional ports on your PiKVM**.

[Just take a look!](switch.md).

You can order PiKVM Switch Multiport Extender from our [international store](https://shop.hipi.io/product/pikvm-switch-multiport-extender).

Canadian customers can place an order at [PiShop.ca](https://www.pishop.ca/product/pikvm-switch-multiport-extender/).

----- 
## List of tested third-party KVMs

There are many ways to do this with third-party switches. For example you can choose a switch with USB control connection like [ezCoo KVM switch](ezcoo.md).

Also, PiKVM can be connected to a multi-port HDMI/USB switch and the switch's buttons can be connected via optocouplers to [the Pi's GPIO to switch channels](gpio.md).

If your KVM switches channels using keyboard shortcuts, there is a chance that it will not be able to work with OTG (v2+ platform, see below), since it does not fully implement the USB stack. In this case, you will have to [use the Pico HID](pico_hid.md) to emulate the keyboard & mouse (PiKVM supports this configuration).

!!! warning
    If you choose AIMOS, be aware that it has a back powering issue that you need to use work arounds for. Limitations are are listed below. Also please be aware that Pico's will not work with the AIMOS KVM's.

Here the status is:

* ✔ - Everything is working as expected. There may be some subtleties.
* ☹ - Not everything works. Additional work is needed for some functions to work, like MSD.
* ✘ - The keyboard or mouse does not work at all, the switch loses the image, etc.

| Model | Status | Notes |
|:---|:---|:---|
| [ezCoo EZ-SW41HA-KVMU3L 4x1 switch](https://www.easycoolav.com/products/hdmi20-switch-4x1-with-usb30-kvm-3-port-usbsupport-4k60hz-444-and-hdr-audio-breakout-36) ~~[ezCoo SW41HA HDMI 4x1 switch](https://www.easycoolav.com/products/hdmi20-switch-4x1-with-usb20-kvm-4-port-usbsupport-4k60hz-444-and-hdr-audio-breakout)~~ (legacy) | ✔ | [Using with PiKVM](ezcoo.md) - 4 Port is the ONLY supported KVM, 2 Port does not work the same and is not supported, the same can be said about any of the HDMI splitters 1-in-2 Out |
| [eccoo EZ-SW41HA-KVMU3P 4x1 switch](https://www.amazon.com/gp/product/B09ZKZK7ZB) |  ✔ | [Using with PiKVM](ezcoo.md). Make sure you buy the with hotkey version as that has the control port | 
| [ezcoo EZ-SW41H21-KVMU3P 8K 4x1 switch](https://www.easycoolav.com/products/8k-hdmi-kvm-switch-4x1-with-usb30-kvm-4k120hz-hotkey-switch) | ☹ | Does NOT have a control port. Can be managed through key combo (ctrl+ctrl+#). Absolute mouse and MSD broken depending on the firmware version/model revision. See [#1463](https://github.com/pikvm/pikvm/issues/1463#issuecomment-4275771178) for more information.
| [Level1Techs KVM switches](https://www.store.level1techs.com/products/hardware) |  ✔ | [Just working pretty good](https://www.youtube.com/watch?v=P6qdXpucm0Q) |
| [TESmart 8 or 16 PORT - HDMI KVM SWITCH](https://www.tesmart.com/collections/for-8-16-pcs-1-monitor) |  ✔ | Use OTG with USB 2.0 Hub only, limited hotkey support on certain models, but MSD only works through Hub ports. Switching available with serial (DIY/v4Plus) or IP-to-serial interface using fixed IP (v4mini et al) (/31 peer-to-peer addressing supported). Can be managed [via WebUI](tesmart.md) or [CLI tool](https://github.com/bbeaudoin/bash/tree/master/tesmart) |
| [XH-HK4401 4-port HDMI USB KVM Switch](https://www.aliexpress.com/item/4000849336545.html) | ✔ | [Using with PiKVM](xh_hk4401.md) - USB MSD works, requires the HDMI backpower solutions found below |
| [AIMOS 8-port HDMI USB-C KVM Switch](https://www.amazon.de/AIMOS-Umschalter-Tastatur-unterst%C3%BCtzen-verbunden/dp/B08FR5K111/) | ☹ | Similar to Ali's noname model, available in 4/8port editions, has same HDMI bridge boot problem/solution using a Marmitek 312 UHD HDMI splitter. ONLY supports HotKey switching.  Limitations are are listed below |
| [Aten CS1758 8-port PS/2 / USB VGA KVM switch](https://www.aten.com/global/en/products/kvm/rack-kvm-switches/cs1758/) | ☹ | Older Aten switches can be had for cheap and can be a viable alternative. Devices are connected via PS/2 so USB media support does not work. The setup relies on a VGA-> HDMI adapter to make the video signal work and there can be issues with unsupported VGA resolutions with some adapters. KVM hotkeys and switching all work and so does mouse and keyboard. |

Limitations:

* HDMI backpower solutions:
    * See [here](https://github.com/pikvm/pikvm/issues/128)
    * See [here](https://github.com/pikvm/pikvm/issues/382) - Advanced soldering required
    * [This loop capture device](https://www.amazon.com/gp/product/B08B346353)
    * v3 HAT v3.3 (Kickstarter model and later) also takes care of the back power issue
* Mass Storage Device (MSD) workaround (will not work OOB)
    * RPi4 and RPi5 OTG needs to be in the KB port for mouse and KB funtionality, ZeroW is required and needs to be connected to the HUB port for MSD functionality - ✔**KNOWN WORKING**✔
    * AIMOS 4/8-port: See [here](https://github.com/pikvm/pikvm/issues/371) - Advanced soldering required - allows use of GPIO menu to change input by cycling
    * AIMOS 8-port: See [here](https://github.com/749/PiKVM-AIMOS-AM-KVM803-UART-Mod) - Advanced soldering required - allows use of GPIO menu to change input directly

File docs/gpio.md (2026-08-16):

---
title: GPIO
description: "How to use GPIO on a PiKVM: drivers, configuration, modules, and more"
---

[GPIO (general-purpose input/output)](https://en.wikipedia.org/wiki/General-purpose_input/output) is a series of digital interfaces that can be used to connect relays, LEDs, sensors, and other components.

!!! warning
    * Before using GPIO on **PiKVM v3 HAT**, carefully study [the purpose of its ports](v3.md#io-ports-and-jumpers).
    * Using GPIO on a PiKVM was designed as a feature for advanced users, so please familiarize yourself with the topic to make sure you understand how to use use it before setting it up.
    * **Careless usage of GPIO can damage your Raspberry Pi or components.**

When talking about PiKVM and GPIO it refers not solely to the [physical interface of the Raspberry Pi](https://www.raspberrypi.org/documentation/usage/gpio), but also to various plugins (for example, for [USB relays](http://vusb.wikidot.com/project:driver-less-usb-relays-hid-interface)) that can also be used transparently by emulating an abstract GPIO API.

-----
## Basics

Setting up GPIO is considerably complex. The interface is divided into several layers for flexibility. Any configuration is performed using a file `/etc/kvmd/override.yaml` which uses the [YAML syntax](https://docs.ansible.com/ansible/latest/reference_appendices/YAMLSyntax.html). We will look at each part of the configuration individually with an example for each. Sections should be combined under shared keys.

* **Wrong:**

    ```yaml
    kvmd:
        gpio:
            drivers: ...
    kvmd:
        gpio:
            scheme: ...
    ```

* **Correct:**

    ```yaml
    kvmd:
        gpio:
            drivers: ...
            scheme: ...
    ```

-----
## Drivers

The first part of the configuration refers to the hardware layer, which defines which IO channels are used (standard GPIO pins of the Raspberry Pi, a USB relay, and so on). If you just want to use GPIO with the default settings you can skip to the next section [Scheme](#Scheme).

Each hardware input/output requires a individual driver configuration entry. Each driver has a type (which refers to the plugin that handles the communication between PiKVM and the hardware) and a unique name. This allows you to either can add multiple drivers of the same type with different settings or connect multiple USB HID relays.

!!! note
    Each driver requires a unique name. Names surrounded by double underscore are system reserved and should not be used.

The only exception to this is the default GPIO driver with the name `__gpio__`, representing the physical GPIO interface of the Raspberry Pi. The configuration section for `__gpio__` is only required in your `/etc/kvmd/override.yaml` if you want to change the default settings. It can be omitted if you are fine with the defaults.

```yaml
kvmd:
    gpio:
        drivers:
            # This example shows how the default __gpio__ driver settings can be changed. It can be omitted if you are fine with the defaults.
            __gpio__:  # Names surrounded by double underscore are system reserved
                type: gpio  # Refers to the plugin name handling the communication

            # You can define another gpio driver for some reason
            my_gpio: 
                type: gpio
                    
            # Example for a USB HID relay connected to PiKVM
            relay:
                type: hidrelay
                device: /dev/hidraw0  # The path to the linux device
```

-----
## Scheme

The second part defines how the various driver channels are configured. Each channel has a unique name, a mode (`input` or `output`), a pin number, and a reference to the driver configured in the previous part.

!!! note
    Names that starts and ends with two underscores (like `__magic__`) are reserved.

Two interaction modes are available for outputs: `pulse` and `switch`. In pulse mode, the output quickly switches its state to logical 1 and back (just like pressing a button). In switch mode, it saves (toggles) the state that the user set. When PiKVM is started/rebooted (any time the KVMD daemon is started or stopped) all output channels are reset to 0. This can be changed using the `initial` parameter. For example, `initial=true` for logic 1 on startup.

If you don't specify a driver for the channel in the scheme the default driver, `__gpio__` will be used.

| Parameter | Type | Allowed values | Default |  Description |
|---|---|---|---|---|
| `led1`, `button1`, `relay1`, etc. | `string`  | `a-Z`, numbers, `_`, `-` | | A section for the named channel |
| `driver` | `string`  | `a-Z`, numbers, `_`, `-` | | Optional, Name of the section defined above in `Drivers` if not GPIO|
| `pin` | `integer` | `X >= 0` | | Refers to a GPIO pin or driver's pin/port |
| `mode` | `enum` | `input` or `output` | | Defines if a channel is used for input or output, may be limited by driver plugin |
| **Input only** | | | | |
| `debounce` | `float` | `x >= 0` | `0.1` | [Debounce](https://www.arduino.cc/en/Tutorial/Debounce) time in seconds. `0` for disable debounce |
| **Output only** | | | | |
| `switch` | `bool`  | `true` or `false` | `true` | Enables or disables the switch mode on the channel (enabled by default).  |
| `initial` | `nullable bool` | `true`, `false` or `null` | `false` | Defines the initial state of the switch upon boot, `null` for don't make changes (the last one does not supported by generic GPIO) |
| `inverted` | `bool` | `true` or `false` | `false` | Inverts the active logical level |
| `pulse` | | | | A section header to define switch pulse configuration |
| `delay` | `float` | `X >= 0` | `0.1` | Defines the pulse time in seconds, `0` for disable pulsing |
| `min_delay` | `float` | `X >= 0.1` | `0.1` |
| `max_delay` | `float` | `X >= 0.1` | `0.1` |

```yaml
kvmd:
    gpio:
        scheme:
            # A certain device sends signals to the RPi and we want the PiKVM to display this as an led
            led1:
                pin: 19 # GPIO pin number on the RPi
                mode: input 
            led2:
                pin: 16
                mode: input 

            # Two outputs of RPi's GPIO
            button1:
                pin: 26 # GPIO pin number on the RPi
                mode: output
                switch: false  # Disable switching, only pulse available
            button2:
                pin: 20
                mode: output
                switch: false

            relay1:  # Channel 1 of the relay /dev/hidraw0
                driver: relay  # Not GPIO, so add name from the above Drivers section
                pin: 0  # Numerating starts from 0
                mode: output  # Relays can't be inputs
                initial: null  # Don't reset the state to 0 when initializing and terminating KVMD
            relay2:  # Channel 2
                driver: relay
                pin: 1
                mode: output
                initial: null
                pulse:
                    delay: 2  # Default pulse value
                    max_delay: 2  # The pulse interval can be between min_delay=0.1 (by default) and max_delay=2
```

-----
## View

This is the last part of the required configuration. It defines how the previous driver and channel configuration is rendered on the Web interface. Here's an example for the example configuration above:

```yaml
kvmd:
    gpio:
        view:
            header:
                title: Switches  # The menu title
            table:  # The menu items are rendered in the form of a table of text labels and controls
                - ["#Generic GPIO leds"]  # Text starting with the sharp symbol will be a label
                - []  # creates a horizontal separator and starts a new table
                - ["#Test 1:", led1, button1]  # Text label, one input, one button with text "Click"
                - ["#Test 2:", led2, button2]
                - []
                - ["#HID Relays /dev/hidraw0"]
                - []
                - ["#Relay #1:", "relay1|Boop 0.1"]  # Text label and button with alternative text
                - ["#Relay #2:", "relay2|Boop 2.0"]
```

This will be rendered as:

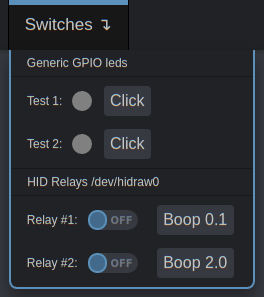
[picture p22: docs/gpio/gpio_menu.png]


Some rules and customization options:

* Text starting with the `#` symbol will be a label.
* To place a channel in a cell, use the name you defined in the scheme.
* Inputs are displayed as round LEDs.
* Outputs are displayed as a switch AND a button.
* If the switch mode is disabled, only a button will be displayed. If pulse is disabled, only a switch will be shown.
* To change the LED's color specify it after the channel name like `"led1|red"`. Available: `green`, `yellow`, `red`, `blue`, `cyan`, `magenta`, `pink` and `white`.
* To change title of the button, write some its name like `"relay1|My cool relay"`.
* Buttons and switches can request confirmation on acting. To do this write its name like `"relay1|confirm|My cool relay"`. The third argument with a title is required in this case.
* The button can automatically close the menu when clicked. Use something like `"relay1|hide|My button"`. It can be used with confirmation option: `"relay1|confirm,hide|My button"`.

Also you can place some leds in the menu title using the similar syntax:

```yaml
kvmd
    gpio:
        view:
            header:
                title: ["#Test1:", led1, "Test2:", led2]
```

-----
## Hardware modules and pseudo-drivers

### Raspberry's GPIO
??? note "Click to view"
    The driver `gpio` provides access to regular GPIO pins with input and output modes. It uses `/dev/gpiochip0` and the libgpiod library to communicate with the hardware. Does not support saving state between KVMD restarts (meaning `initial=null`).

    You can use the [interactive scheme](https://pinout.xyz/) when selecting the pins to use. Please note that when selecting a pin for a channel, you need to use a logical number instead of a physical number. That is, if you want to use a physical pin with the number 40, the channel must have the number 21 corresponding to the logical GPIO21.

    Channels should not use duplicate pins. You can also not use already used pins. To see which pins are currently used, run the command `gpioinfo`.

### USB HID Relay
??? note "Click to view"
    The driver `hidrelay` provides access to cheap managed [USB HID relays](http://vusb.wikidot.com/project:driver-less-usb-relays-hid-interface) that can be found on AliExpress. This driver does not support input mode, only output. To use it, you need to specify the path to the device file (like `/dev/hidraw0`) using the `device` parameter.

    Additionally, we recommend to configure access rights and static device name using [UDEV rules](https://wiki.archlinux.org/index.php/udev). For example, create `/etc/udev/rules.d/99-kvmd-extra.rules`:

    ```
    KERNEL=="hidraw[0-9]*", SUBSYSTEMS=="usb", ATTRS{idVendor}=="16c0", ATTRS{idProduct}=="05df", GROUP="kvmd"
    ```

    Channels should not use duplicate physical numbers. The driver supports saving state between KVMD restarts (meaning `initial=null`).

### ezCoo KVM switch
??? note "Click to view"
    You can use GPIO to control KVM port switching. This usually requires the use of relays and buttons, but for the [ezCoo switch](ezcoo.md) there is a special `ezcoo` driver that simulates GPIO by sending commands to the switch via serial port. So you can make a menu in PiKVM to control the multiport switch.

### IPMI
??? note "Click to view"

    The driver `ipmi` provides the ability to send IPMI commands (on, off, reset) and show the power status of the remote host. In fact, this is not a hardware driver, but something like a pseudo-GPIO. Each "pin" is actually responsible for a specific IPMI operation of `ipmitool`:

    | Pin | Type     | Command |
    |-----|----------|---------|
    | `0` | `input`  | `ipmitool ... power status`, can be used to draw the LED in the menu |
    | `1` | `output` | `ipmitool ... power on`, sends the `on` command (and only this), so like all other outputs it should be a button |
    | `2` | `output` | `ipmitool ... power off` |
    | `3` | `output` | `ipmitool ... power cycle` |
    | `4` | `output` | `ipmitool ... power reset` |
    | `5` | `output` | `ipmitool ... power diag` |
    | `6` | `output` | `ipmitool ... power soft` |

    You are supposed to define one driver per host:

    ```yaml
    kvmd:
        gpio:
            drivers:
                my_server:
                    type: ipmi
                    host: myserver.local
                    user: admin
                    passwd: admin
            scheme:
                my_server_status:
                    driver: my_server
                    pin: 0
                    mode: input
                my_server_on:
                    driver: my_server
                    pin: 1
                    mode: output
                    switch: false
                my_server_off:
                    driver: my_server
                    pin: 2
                    mode: output
                    switch: false
            view:
                table:
                    - [my_server_status, "my_server_on|On", "my_server_off|Off"]
    ```

### Intel AMT
??? note "Click to view"

    The driver `amt` provides the ability to send Intel AMT power commands (poweron, poweroff, reset) and show the power status of the remote host. In fact, this is not a hardware driver, but something like a pseudo-GPIO. Each "pin" is actually responsible for a specific AMT operation of [meshcmd](https://docs.meshcentral.com/meshcmd/):

    !!! warning
        To use this driver, you have to download the [meshcmd binary](https://meshcentral.com/executables/meshcmd-linux-arm-64) and install it to `/usr/local/bin`. ([Download page](https://meshcentral.com/downloads.html)). ** This is a third-party binary and we are not responsible for it. Use it at your own risk.**

        ```console
        [root@pikvm ~]# rw
        [root@pikvm ~]# curl -L https://meshcentral.com/executables/meshcmd-linux-arm-64 -o /usr/local/bin/meshcmd
        [root@pikvm ~]# chmod +x /usr/local/bin/meshcmd
        ```

    | Pin | Type     | Command |
    |-----|----------|---------|
    | `0` | `input`  | `meshcmd ... amtpower status`, can be used to draw the LED in the menu |
    | `1` | `output` | `meshcmd ... amtpower poweron`, sends the `poweron` command (and only this), so like all other outputs it should be a button |
    | `2` | `output` | `meshcmd ... amtpower poweroff` |
    | `3` | `output` | `meshcmd ... amtpower cycle` |
    | `4` | `output` | `meshcmd ... amtpower reset` |
    | `5` | `output` | `meshcmd ... amtpower sleep` |
    | `6` | `output` | `meshcmd ... amtpower hibernate` |

    You are supposed to define one driver per host:

    ```yaml
    kvmd:
        gpio:
            drivers:
                my_server:
                    type: amt
                    host: myserver.local
                    user: admin
                    passwd: admin
                    tls: true
            scheme:
                my_server_status:
                    driver: my_server
                    pin: 0
                    mode: input
                my_server_on:
                    driver: my_server
                    pin: 1
                    mode: output
                    switch: false
                my_server_off:
                    driver: my_server
                    pin: 2
                    mode: output
                    switch: false
            view:
                table:
                    - [my_server_status, "my_server_on|On", "my_server_off|Off"]
    ```

### Wake-on-LAN
??? note "Click to view"
    The driver `wol` provides a simple generator of Wake-on-LAN packages. One driver and one output are generated for one host if a [simplified configuration method](wol.md) is used. However, you can define multiple drivers if you want to manage different hosts. One driver controls one host, and can only be used as an output. Pin numbers are ignored.

    ```yaml
    kvmd:
        gpio:
            drivers:
                wol_server1:
                    type: wol
                    mac: ff:ff:ff:ff:ff:f1
                wol_server2:
                    type: wol
                    mac: ff:ff:ff:ff:ff:f2
                    ip: 192.168.0.100
                    port: 9
            scheme:
                wol_server1:
                    driver: wol_server1
                    pin: 0
                    mode: output
                    switch: false
                wol_server2:
                    driver: wol_server2
                    pin: 0
                    mode: output
                    switch: false
            view:
                table:
                    - ["#Server 1", "wol_server1|Send Wake-on-LAN"]
                    - ["#Server 2", "wol_server2|Send Wake-on-LAN"]
    ```

### CMD
??? note "Click to view"
    The `cmd` driver allows you to run custom command on PiKVM OS.

    !!! note
        This driver does not support bash operators, that is, it is a direct call to commands with arguments. For more complex cases, write your own shell scripts.

    Commands are executed from the user `kvmd`. If you want to run the command as root, then you need to configure `sudo`. Example of the `/etc/sudoers.d/custom_commands`:
    
    Granular example

    ```sudoers
    kvmd ALL=(ALL) NOPASSWD: /usr/bin/reboot
    ```

    Example of the `/etc/kvmd/override.yaml`:

    ```yaml
    kvmd:
        gpio:
            drivers:
                reboot:
                    type: cmd
                    cmd: [/usr/bin/sudo, reboot]
            scheme:
                reboot_button:
                    driver: reboot
                    pin: 0
                    mode: output
                    switch: false
            view:
                table:
                    - ["reboot_button|confirm|Reboot PiKVM"]
    ```

    An example to help you get started:

    * `cmd: [/usr/bin/sudo, kvmd-otgconf, --disable-function, mass_storage.usb0]`
    * `cmd: [(absolute path to sudo, command, flag, flag, absolute path to file]`

    Then run the following:

    ```
    systemctl restart kvmd
    ```

### PWM
??? note "Click to view"
    The `pwm` driver allows you to use [some GPIO pins](https://pinout.xyz/pinout/pwm) on the Raspberry Pi for PWM.

    !!! note
        Due to hardware limitations, this module conflicts with the **kvmd-fan** (the fan controller) on PiKVM V3 and V4 Plus.
        To use it, you have to use hardware PWM for kvmfan. To do this, add the following lines to `/etc/kvmd/fan.ini`:

        ```ini
        [main]
        pwm_soft = 80
        ```

        *Not needed for V4 Mini because it does not have a fan.*

    Here the small example with servo control:

    1. Add some params to `/boot/config.txt`:

        * For PiKVM V3 or DIY device to enable [PWM0_0](https://github.com/dotnet/iot/blob/main/Documentation/raspi-pwm.md#enabling-hardware-pwm) on RPi GPIO18:

            ```ini
            dtoverlay=pwm
            ```

        * For PiKVM V4 to enable [PWM0_0](https://github.com/dotnet/iot/blob/main/Documentation/raspi-pwm.md#enabling-hardware-pwm) on CM4 GPIO12 (CN5 NeoPixel Pin) and set the PWM function to 4 (ALT0):

            ```ini
            dtoverlay=pwm,pin=12,func=4
            ```

    2. Connect Servo motor like SG90 PWM connection to RPi GPIO18 or CM4 GPIO12, +5V and GND to a 5V and GND pin on header:

    3. Add to /etc/kvmd/override.yaml

        ```yaml
        kvmd:
            gpio:
                drivers:
                    servo1:
                        type: pwm
                        chip: 0                      # PWM Chip Number
                        period: 20000000             # Servo Motor SG90 Period in nano-seconds
                        duty_cycle_push: 1500000     # Servo Motor SG90 duty_cycle for pushing button
                        duty_cycle_release: 1000000  # Servo Motor SG90 duty_cycle for releasing button
                scheme:
                    __v4_locator__:  # v4-mini only
                        pin: 25      # v4-mini only
                    short_press:
                        driver: servo1
                        pin: 0  # Pin number is the PWM channel number on the PWM Chip
                        mode: output
                        switch: false
                        pulse:
                            delay: 0.5
                            max_delay: 2
                    long_press:
                        driver: servo1
                        pin: 0
                        mode: output
                        switch: false
                        pulse:
                            delay: 2
                            max_delay: 2
                    extra_long_press:
                        driver: servo1
                        pin: 0
                        mode: output
                        switch: false
                        pulse:
                            delay: 10
                            max_delay: 20
                view:
                    header:
                        title: Controls
                    table:
                        - ["#Servo - Short Press", "short_press|Press"]
                        - ["#Servo - Long Press", "long_press|Press"]
                        - ["#Servo - Extra Long Press", "extra_long_press|Press"]
        ```

### Servo
??? note "Click to view"
    The `servo` module is built on top of the `pwm` module and allows user to define angles instead of `duty_cyles` to control a PWM enabled servo motor like SG90. When the button is pressed the servo motor moves to an angle defined by `angle_push` and when button is released it moves back to `angle_release`. In the example configuration for a [cheap 5V SG90 Servo](https://www.ebay.co.uk/sch/i.html?_nkw=5V+SG90+Servo), the motor moves to an angle of 45 degrees when button is pressed and moves back to 20 degress when released.

    !!! note
        Due to hardware limitations, this module conflicts with the **kvmd-fan** (the fan controller) on PiKVM V3 and V4 Plus.
        To use it, you have to use hardware PWM for kvmfan. To do this, add the following lines to `/etc/kvmd/fan.ini`:

        ```ini
        [main]
        pwm_soft = 80
        ```

        *Not needed for v4-mini because it does not have a fan.*

    To use Servo motors in PiKVM you need to follow steps 1-3 for [PWM Module](#pwm) and then use the following configuration.

    Add to `/etc/kvmd/override.yaml`:

    ```yaml
    kvmd:
        gpio:
            drivers:
                servo1:
                    type: servo
                    chip: 0                  # PWM Chip Number
                    period: 20000000         # Servo Motor SG90 Period in nano-seconds
                    duty_cycle_min: 350000   # Servo Motor SG90 duty_cycle for -90 degrees
                    duty_cycle_max: 2350000  # Servo Motor SG90 duty_cycle for +90 degrees
                    angle_max: 90            # Servo Motor SG90 angle at duty_cycle_max
                    angle_min: -90           # Servo Motor SG90 angle at duty_cycle_min
                    angle_push: 45           # Servo Motor SG90 angle to push button
                    angle_release: 20        # Servo Motor SG90 angle to release button
            scheme:
				__v4_locator__:  # v4-mini only
					pin: 25      # v4-mini only
				short_press:
					driver: servo1
					pin: 0  # Pin number is the PWM channel number on the PWM Chip
					mode: output
					switch: false
					pulse:
						delay: 0.5
						max_delay: 2
				long_press:
					driver: servo1
					pin: 0
					mode: output
					switch: false
					pulse:
						delay: 2
						max_delay: 2
				extra_long_press:
					driver: servo1
					pin: 0
					mode: output
					switch: false
					pulse:
						delay: 10
						max_delay: 20
            view:
                header:
                    title: Controls
                table:
                    - ["#Servo - Short Press", "short_press|Press"]
                    - ["#Servo - Long Press", "long_press|Press"]
                    - ["#Servo - Extra Long Press", "extra_long_press|Press"]
    ```

### Philips Hue
??? note "Click to view"
    The `hue` module can control [smartplugs](https://shop.ledvance.com/en/products/smart-plug-eu) and lamps over Philips Hue Bridge API. In general the plugin can switch any device on/off which is connected to the bridge. To use it you will need API token aka username:

    1. Open `http://bridge/debug/clip.html`.
    2. In the URL: Field type `/api/`.
    3. In the Message Body: Field type: `{"devicetype": "pikvm"}`.
    4. Hit the Get Button.
    5. As the Response you become the Username: `{"success": {"username": "apiusername"}`.

    Example:

    ```yaml
    kvmd:
        gpio:
            drivers:
                hue:
                   type: hue
                   url: http://bridge
                   token: YG-xxxxxxxxxxxx
            scheme:
                plug_button:
                    driver: hue
                    pin: 32
                    mode: output
                    initial: null
                    switch: true
                    pulse:
                        delay: 0
                plug_led:
                    driver: hue
                    pin: 32
                    mode: input
            view:
                table:
                    - ["plug_led", "plug_button"]

    ```

### ANEL NET-PwrCtrl
??? note "Click to view"    
    The `anelpwr` plugin allows you to use ANEL NET-PwrCrtl IP-PDUs (switchabel sockets) as gpios. There are up to 8 Ports per PDU. Input pulls the the current state from the PDU, Output switches the Socket. 

    ```yaml
    kvmd:
        gpio:
            drivers:
                anel_pdu_0:
                    type: anelpwr
                    url: http://IP:port
                    user: admin
                    passwd: anel
            scheme:
                pdu0_0_pwr:
                    pin: 0
                    driver: anel_pdu_0
                    mode: output
                    pulse:
                        delay: 0
                pdu0_0_led:
                    pin: 0
                    driver: anel_pdu_0
                    mode: input
            view:
                header:
                   title: "PDUs"
                table:
                    - ["#PDU0"]
                    - []
                    - ["#PDU0_Port0:", pdu0_0_led, "pdu0_0_pwr|confirm|test"] 
    ```

### Extron SW Series Switchers
??? note "Click to view"
    The `extron` plugin allows you to control Extron SW series switchers (ex. SW4 USB, SW4 VGA, etc.). There are up to 4 Ports per switcher. Input pulls the the current state from the switcher, Output switches the active port.

    ```yaml
    kvmd:
        gpio:
            drivers:
                extron_vga:
                    type: extron
                    device: /dev/ttyUSB0  # The path to the RS-232 serial adapter
            scheme:
                vga_port1_led:
                    pin: 0
                    driver: extron_vga
                    mode: input
                vga_port2_led:
                    pin: 1
                    driver: extron_vga
                    mode: input
                vga_port3_led:
                    pin: 2
                    driver: extron_vga
                    mode: input
                vga_port4_led:
                    pin: 3
                    driver: extron_vga
                    mode: input
                vga_port1_button:
                    pin: 0
                    driver: extron_vga
                    mode: output
                vga_port2_button:
                    pin: 1
                    driver: extron_vga
                    mode: output
                vga_port3_button:
                    pin: 2
                    driver: extron_vga
                    mode: output
                vga_port4_button:
                    pin: 3
                    driver: extron_vga
                    mode: output
            view:
                header:
                   title: "Extron SW4 VGA"
                table:
                    - ["vga_port1_led|red", "vga_port1_button||Port 1"]
                    - ["vga_port2_led|red", "vga_port2_button||Port 2"]
                    - ["vga_port3_led|red", "vga_port3_button||Port 3"]
                    - ["vga_port4_led|red", "vga_port4_button||Port 4"]
    ```

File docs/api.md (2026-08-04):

---
title: HTTP API reference
description: Documentation for all functions of PiKVM microservices exposed via RESTful APIs
---

This document describes the PiKVM API. Since the system consists of microservices, here is a common API with a common entry point provided by Nginx. The below examples use `curl` and [`websocat`](https://github.com/vi/websocat) with the `-k` option disables SSL certificate verification, since the self-signed certificates are used in the default installation.

There is a [third-party library](https://github.com/guanana/pikvm-lib) for using the PiKVM API. Please note that this is an unofficial library, so use it carefully.

-----
## Authentication

All APIs are restricted to authentication. To make requests, you either need to auth each request individually, or get a token and pass it as a cookie with each request.

With enabled [2FA](auth.md#two-factor-authentication), you will need to add the one-time code to the password without spaces. That is, if the password is `foobar` and the code is `123456`, then you need to use `foobar123456` as the password.

The code can be generated using any TOTP library, for example in Python:

```python
import requests
import pyotp

user = "admin"
passwd = "admin"
secret = "3OBBOGSJRYRBZH35PGXURM4CMWTH3WSU"  # Can be found in /etc/kvmd/totp.secret

print(requests.get(
    url="https://pikvm/api/info",
    verify=False,  # For self-signed SSL certificate
    headers={
        "X-KVMD-User": user,
        "X-KVMD-Passwd": passwd + pyotp.TOTP(secret).now(),
    },
).text)
```

Since in the borderline case of the 2FA code lifetime, the code may be invalid,
it makes sense to either handle error 403 by repeating the request in seconds.

A more correct way is to combine this method and check the remaining lifetime
and postpone the request if there is a second or so left. You can find out how much
time is left in this way:

```python
totp = pyotp.TOTP(secret)
now = int(time.time())
remaining = now - (now % totp.interval)
```

### Single-request authentication

There are two options here:

* **Using X-headers.** Just pass `X-KVMD-User` and `X-KVMD-Passwd` with the request:

    ```
    $ curl -k -H X-KVMD-User:admin -H X-KVMD-Passwd:admin https://<pikvm-ip>/api/auth/check
    ```

* **Using HTTP Basic Auth.** Please note: contrary to the standard, this method DOES NOT use the `WWW-Authenticate` header. HTTP Basic Auth in this implementation is intended only for compatibility with other systems, such as [Prometheus](prometheus.md).

    ```console
    $ curl -k -u admin:admin https://<pikvm-ip>/api/auth/check
    ```

### Session-based cookie auth

1. Get the access token for the user using `POST /api/auth/login`:

    ```console
    $ curl -k -v -X POST --data user=admin --data passwd=admin https://pikvm/api/auth/login
    ...
    < Set-Cookie: auth_token=796cb83b11de4fcb749bc1bad14a91fb06dede84672b2f847fef1e988e6900de; Path=/
    ...
    ```

    On success the cookie `auth_token` will be received with `200 OK`. On invalid user or password you will get `403 Forbidden`.

2. The handle `GET /api/auth/check` can be used for check the auth status. Return of `200 OK` will signal that user is authenticated. If the token or any of the single-request auth methods are missing, `401 Unauthorized` will be returned. In case of incorrect credentials or token, `403 Forbidden` will be returned.

3. The handle `POST /api/auth/logout` can be used to invalidate session token. The response codes will be similar to the previous handle.
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

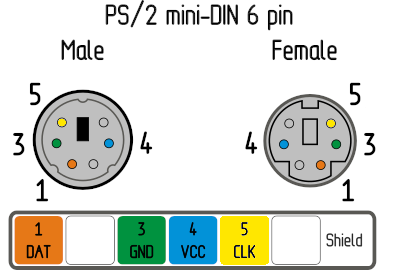
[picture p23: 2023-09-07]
docs/pico_hid/ps2_pinout.png

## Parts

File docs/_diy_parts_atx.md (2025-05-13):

---
search:
    exclude: true
---

With this part, you will be able to remotely turn on, turn off and restart your computer!

* *x4* optocouplers
  [TLP241BF(F](https://eu.mouser.com/ProductDetail/Toshiba/TLP241BFF?qs=CiayqK2gdcK1m25Yj88BfQ%3D%3D)
  or [PC817X2NSZ9F](https://eu.mouser.com/ProductDetail/Sharp-Microelectronics/PC817X2NSZ9F?qs=rrS6PyfT74ehABo1g8zXHw%3D%3D) (the input polarity must be observed)
  or [OMRON G3VM-61A1](https://www.digikey.com/products/en?keywords=G3VM-61A1)
  or [OMRON G3VM-61AY1](https://www.digikey.com/products/en?keywords=G3VM-61AY1)<br>
  *Don't use random relay modules or random optocouplers! Some of these may not be sensitive enough
  for the Raspberry Pi, some others may be low-level controlled. Either use relays that are activated by a high logic level,
  or follow the design provided. See details [here](https://github.com/pikvm/pikvm/issues/13).*
* *x4* 390 Ohm resistors (see [here](https://github.com/pikvm/pikvm/issues/46) for alternatives).
* *2x* 4.7 kOhm resistors.
* *x10+* dupont wires male-male.
* *x1* a breadboard.
* *various* wires for the breadboard.

This can be partially replaced by using [Wake-on-LAN](wol.md) in the software, but it will not allow
to reboot a hung system, and it is not as reliable as an ATX controller. Sometimes the Wake-on-LAN
on the host just stops working, for its own or network reasons.

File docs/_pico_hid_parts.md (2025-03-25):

---
search:
    exclude: true
---

* *x1* [Raspberry Pi Pico board](https://www.raspberrypi.com/products/raspberry-pi-pico/) with soldered pins. Pico 2 is not supported right now.

* *x1* USB-A to Micro-USB cable.

* *x10* dupont wires female-female.

* *x1* 1N5819 diode. It's optional but strongly recommended. Any similar one will do.

    !!! warning
        The diode is needed to provide power to the Pico HID regardless of the target host state,
        which prevents the backpowering problem. It will allow you to keep the keyboard buttons pressed
        during the target host power cycle, which is, for example, important for MacOS to get into the boot menu.

        Do not connect the red wire (the `VSYS (Pico) -> 5V (Pi)` line) without a diode.
        If you can't find a diode, don't connect this wire at all.

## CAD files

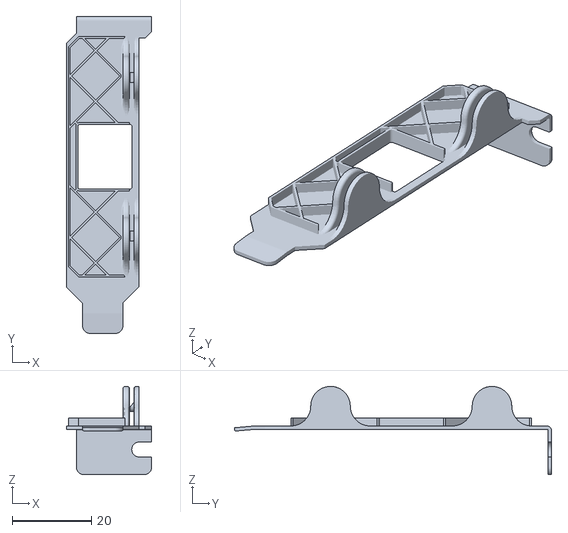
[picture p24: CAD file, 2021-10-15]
docs/stl/atx/pci_short.stl
21.6 x 80.1 x 22.3

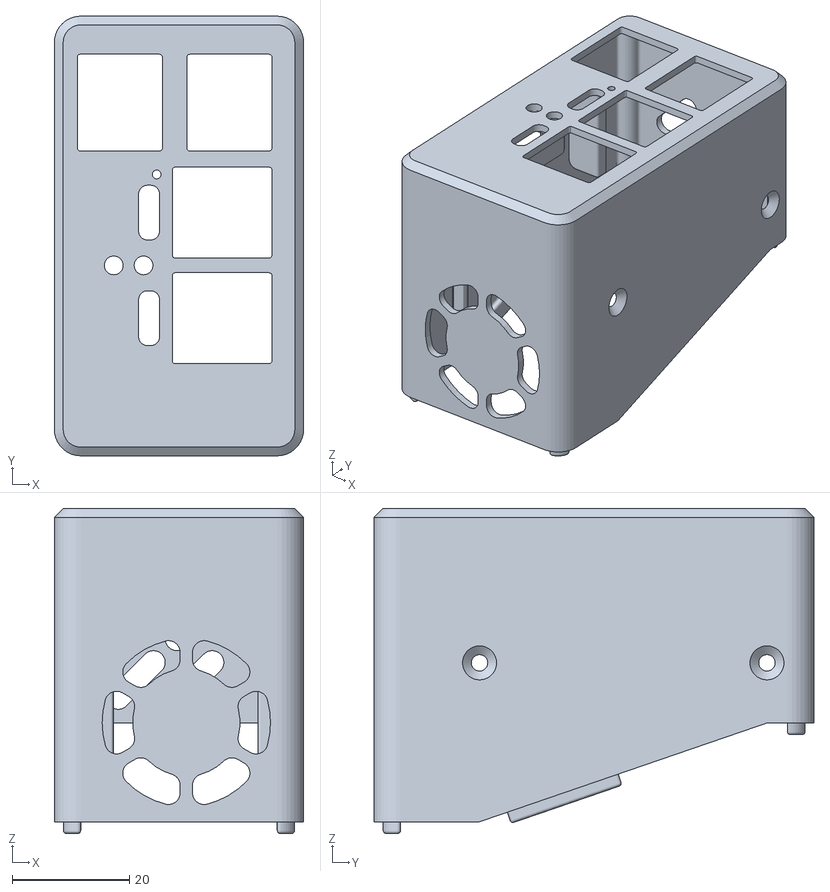
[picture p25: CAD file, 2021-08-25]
docs/stl/v3.3/case_a.stl
42.5 x 75.0 x 55.4

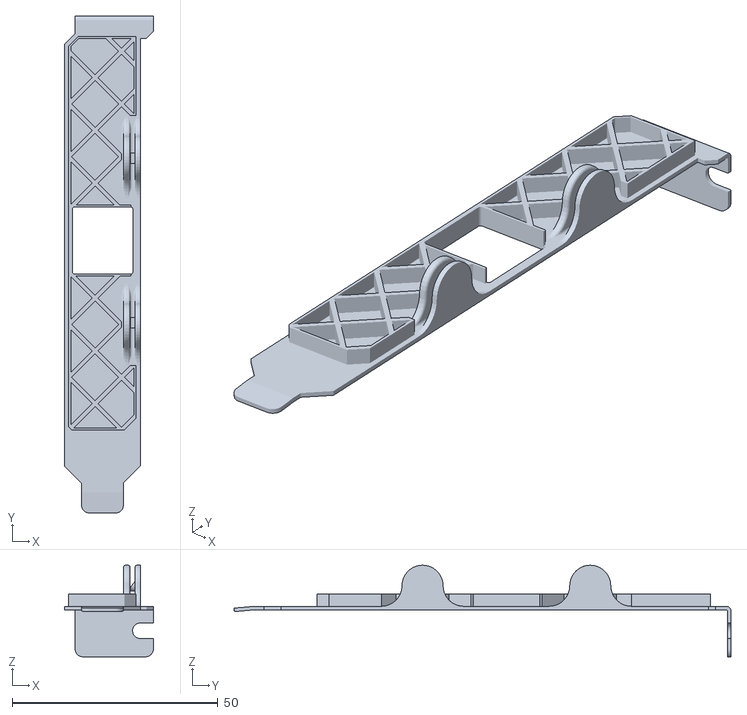
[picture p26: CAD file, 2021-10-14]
docs/stl/atx/pci_long.stl
21.6 x 120.9 x 22.3

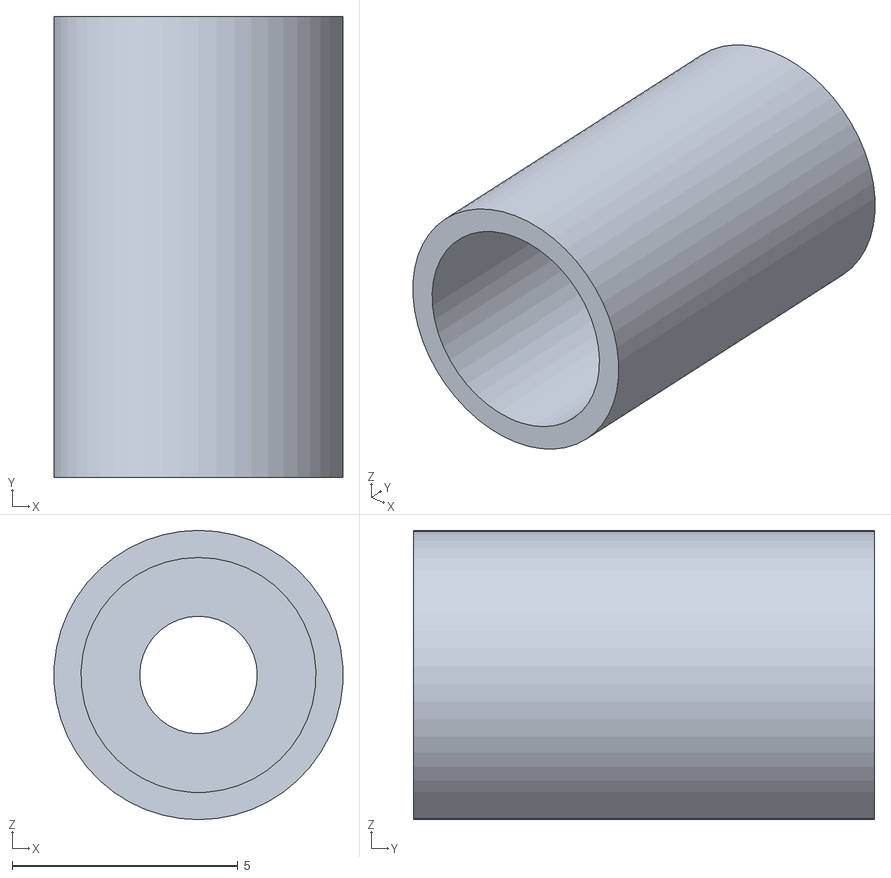
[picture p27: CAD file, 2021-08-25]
docs/stl/v3.3/spacer_6.2mm.stl
6.39 x 10.2 x 6.40

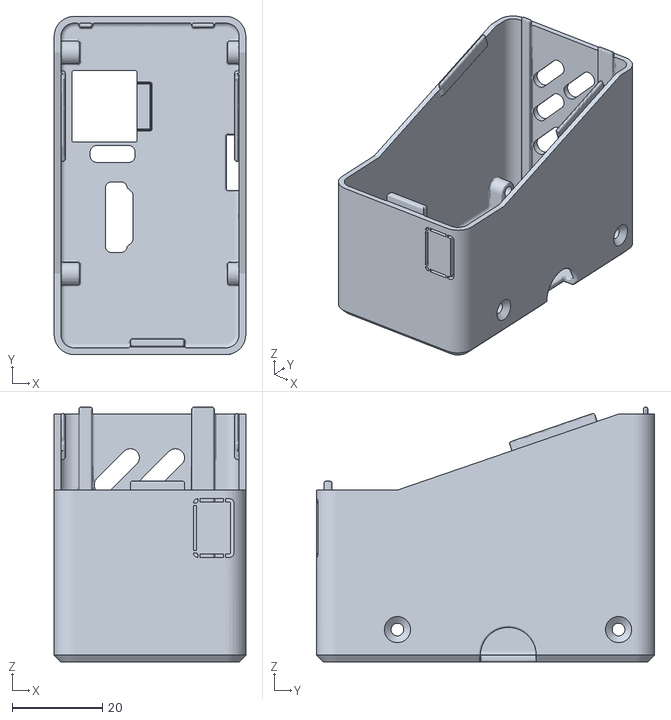
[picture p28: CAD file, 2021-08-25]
docs/stl/v3.3/case_b.stl
42.5 x 75.0 x 56.5

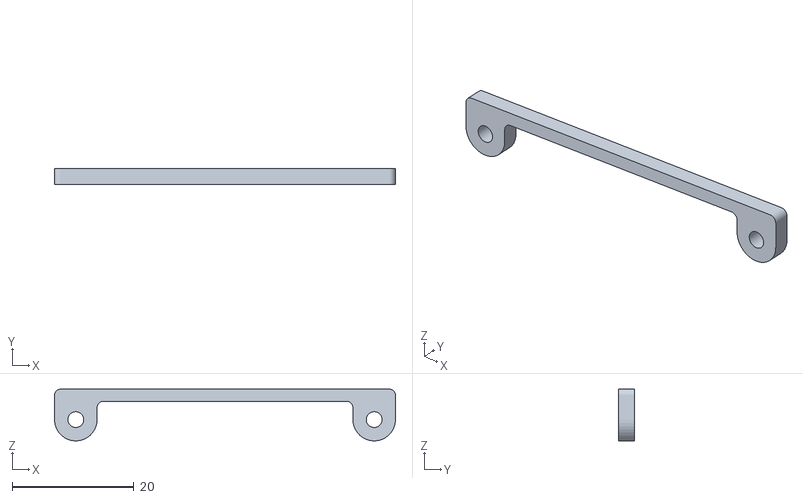
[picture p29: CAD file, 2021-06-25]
docs/stl/v3.3/low_spacer.stl
56.0 x 2.60 x 8.49

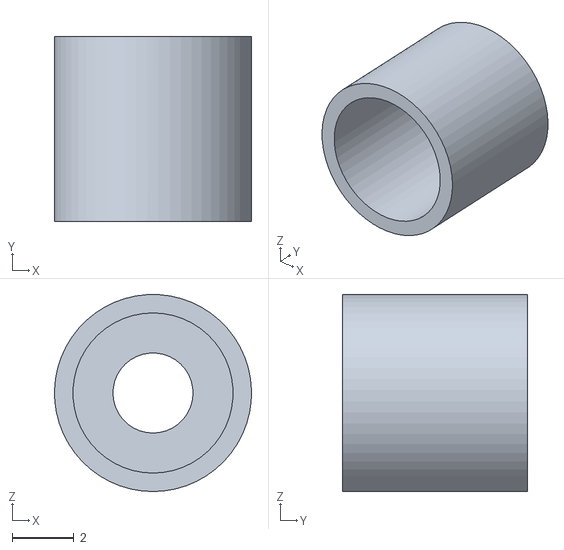
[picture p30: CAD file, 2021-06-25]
docs/stl/v3.3/spacer_1mm.stl
6.40 x 6.00 x 6.40

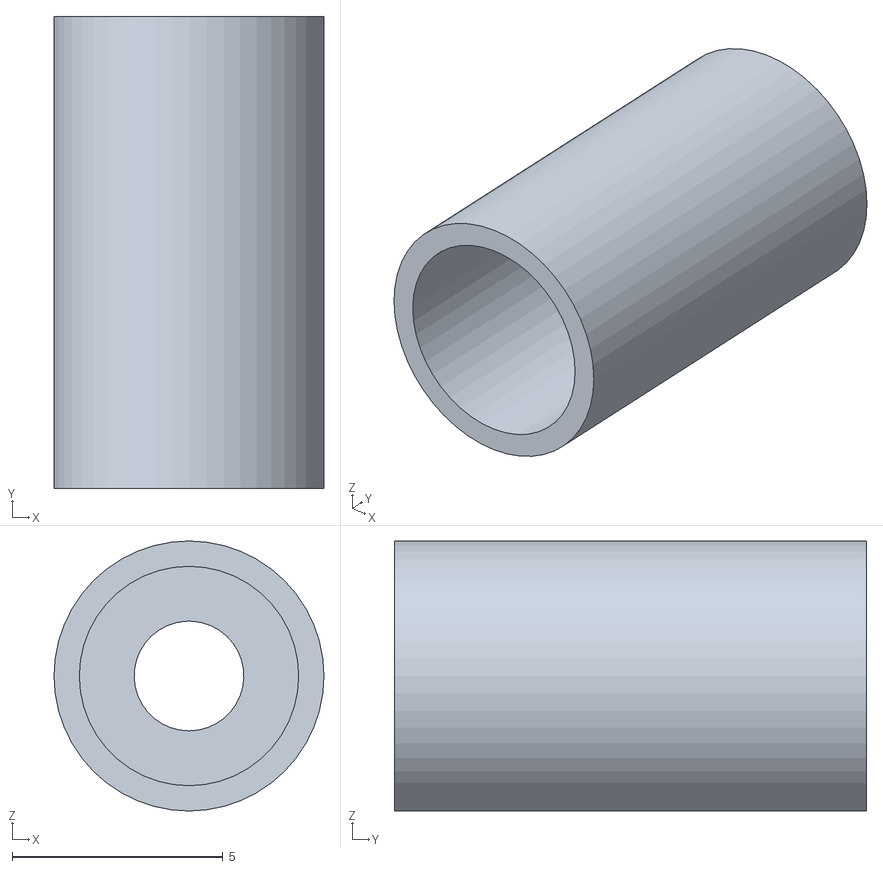
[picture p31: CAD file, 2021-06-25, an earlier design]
docs/stl/v3.2/spacer_6.2mm.stl
6.40 x 11.2 x 6.40

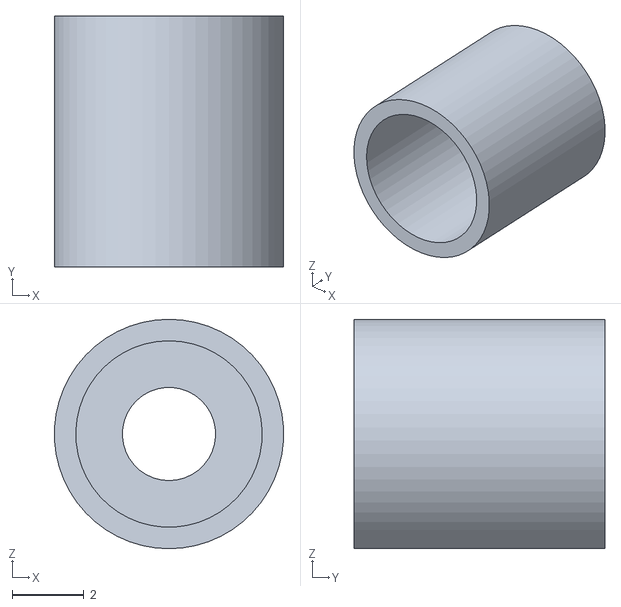
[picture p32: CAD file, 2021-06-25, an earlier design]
docs/stl/v3.2/spacer_2mm.stl
6.39 x 7.00 x 6.40

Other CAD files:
docs/stl/v3.3/case_a_no_oled.stl
docs/stl/v3.2/case_a_no_oled.stl
docs/stl/v3.2/case_b_no_aum.stl
docs/stl/v3.2/case_b.stl
docs/stl/v3.2/case_a.stl

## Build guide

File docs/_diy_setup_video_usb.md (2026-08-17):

---
search:
    exclude: true
---

Connect USB dongle to exactly this port. It is bound in the software so the OS does not confuse the video device with something else.

| Raspberry Pi 2, 3 and 5 | Raspberry Pi 4 |
|---|---|
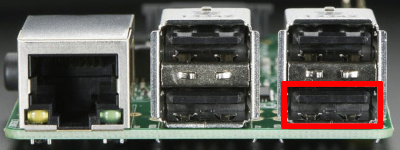
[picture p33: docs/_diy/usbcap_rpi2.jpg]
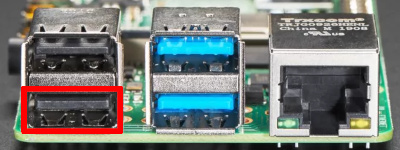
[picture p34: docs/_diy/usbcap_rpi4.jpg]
|  |  |

There are many revisions of the Raspberry Pi boards and you may come across one that we haven't tested.
If the binding fails, the device will be available for all ports.
Everything will work, but if you use a webcam and Linux mistakes it for a dongle,
[write to us](https://pikvm.org/support/) and we will fix it.

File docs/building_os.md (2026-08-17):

---
title: Building PiKVM OS
description: How to build PiKVM OS from source code with Docker
---

The assembly of PiKVM OS is carried out using a special build environment.
Here the minimum required for its use, imposed on the build machine:

* kernel >= 5.8
* glibc >= 2.33
* docker >= 19.03.13
* git

Docker must work in privileged mode.

1. When starting with a clean OS you need to install and configure Docker. An example for Ubuntu:

    ```console
    [user@localhost ~]$ sudo apt-get install git make curl binutils -y
    [user@localhost ~]$ sudo apt-get install docker.io
    [user@localhost ~]$ sudo usermod -aG docker $USER
    ```

    Re-login to apply the changes.

2. Checkout the build environment:

    ```console
    [user@localhost ~]$ git clone --depth=1 https://github.com/pikvm/os
    [user@localhost ~]$ cd os
    ```

3. Determine the target board and platform:

    * Choose the board:
        * `BOARD=rpi4` for Raspberry Pi 4.
        * `BOARD=rpi5`
        * `BOARD=zero2w`
        * `BOARD=rpi3`
        * `BOARD=rpi2`

    * Choose the platform:
        * `PLATFORM=v4mini-hdmi` for PiKVM V4 Mini.
        * `PLATFORM=v4plus-hdmi` for PiKVM V4 Plus.
        * `PLATFORM=v3-hdmi` for RPi4 and PiKVM V3 HAT.
        * `PLATFORM=v2-hdmi` for RPi3a+/RPi4 or Zero2W with HDMI-CSI bridge.
        * `PLATFORM=v2-hdmiusb` for RPi4 and RPi5 with HDMI-USB dongle.
        * `PLATFORM=v1-hdmi` for RPi2 or 3b+ with HDMI-CSI bridge and the Pico HID.
        * `PLATFORM=v1-hdmiusb` for RPi2 or 3b+ with HDMI-USB dongle and the Pico HID.

4. Create the build config file `config.mk` for the target system and and the `BOARD` and `PLATFORM` variables.
    You can also set some other parameters as you wish (see below).
    Please note: if your password contains the # character, you must escape it using a backslash like `ROOT_PASSWD = pass\#word`.

    ```bash
    # Base board
    BOARD = rpi4

    # Hardware configuration
    PLATFORM = v2-hdmi

    # Target hostname
    HOSTNAME = pikvm

    # ru_RU, etc. UTF-8 only
    LOCALE = en_US

    # See /usr/share/zoneinfo
    TIMEZONE = Europe/Nicosia

    # For SSH root user
    ROOT_PASSWD = change_me

    # Web UI credentials: user=admin, password=admin_change_me
    WEBUI_ADMIN_PASSWD = admin_change_me

    # IPMI credentials: password=ipmi_change_me
    IPMI_ADMIN_PASSWD = ipmi_change_me
    ```

   !!! warning

       Due to the [legacy of the IPMI protocol](ipmi.md), passwords for it are stored as plain text in `/etc/kvmd/ipmipasswd`.

       Do not use passwords for IPMI that you use somewhere else.

4. Build the OS. It may take about one hour depending on the Internet connection:

    ```console
    [user@localhost os]$ make os
    ```

    !!! tip
        If you get an error about failing to retrieving a file, please edit the Makefile and remove `de3.` from the repo URL.

5. Create an image. It will be stored in the `images` directory as a file with `*.img` extension:

    ```console
    [user@localhost os]$ make image
    ```

6. [Flash the result image to SD card](flashing_os.md#flashing-the-image).

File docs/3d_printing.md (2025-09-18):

---
title: Cases for 3D printing
description: Download and 3D-print your own case for a PiKVM
---

## PiKVM V3 HAT cases

* [**v3.3 model (Kickstarter, Store)**](stl/v3.3/index.md)
* [Unofficial but great v3.3 case mod for Noctua fan](https://www.printables.com/model/218724-pikvm-case-mod-for-silent-noctua-40mm-fan)
* [v3.2 model (Pre-release)](stl/v3.2/index.md)

## DIY cases

| Model | Notes |
|---|---|
| https://www.thingiverse.com/thing:4799094 | Case for the [USB-C/PWR Splitter without Barrel jack](https://www.tindie.com/products/8086net/usb-cpwr-splitter/) |
| https://www.thingiverse.com/thing:4931970 | Raspberry Pi 4 Pi-KVM Case |
| https://www.thingiverse.com/thing:4862304 | Case for PiKVM (LCD + ATX) |
| https://www.thingiverse.com/thing:4868258 | R4C3R - Low Profile PCIe bracket for PiKVM based on Raspberry Pi Zero + Lusya + ATX controls |
| https://www.thingiverse.com/thing:4866005 | R4C3R - Full Profile PCIe bracket for PiKVM based on Raspberry Pi Zero + Lusya + ATX controls |
| https://www.thingiverse.com/thing:4832248 | Case for the [USB-C/PWR Splitter without Barrel jack](https://www.tindie.com/products/8086net/usb-cpwr-splitter/) and HDMI-CSI bridge |
| https://www.thingiverse.com/thing:4916230 | A very compact case without internal power splitter |
| https://www.thingiverse.com/thing:4915627 | ZeroW + CSI case |
| https://www.thingiverse.com/thing:4950281 | PiKVM RETRO Case for CSI-2 C779 Bridge w/ OLED Display Screen |
| https://www.thingiverse.com/thing:4950280 | USB Power Blocker Case |
| https://www.thingiverse.com/thing:4642116 | Conix's PI-KVM case for v2 |
| https://www.thingiverse.com/thing:7148243 | Wall mount for PiKVM v3 |

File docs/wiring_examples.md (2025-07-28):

---
title: Some example wiring setups
description: Learn how to wire your DIY PiKVM from these examples
---

## HDMI-CSI

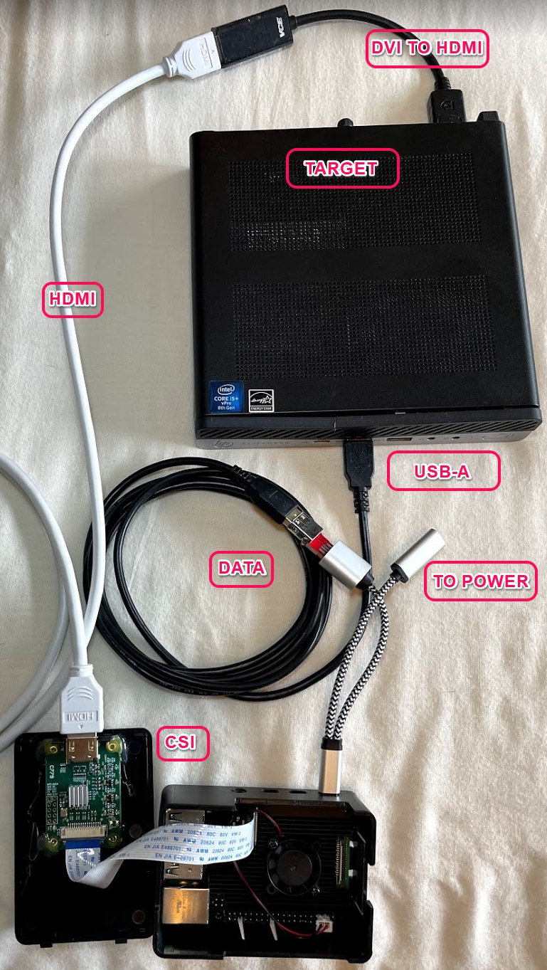
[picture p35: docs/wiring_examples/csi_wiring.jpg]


List of items: (WARNING! Links may dissappear or no longer work, this just gives you an idea)

- USB-A male to USB-A male (For data)
- [PortaPow USB Power Blocker](https://www.amazon.com/gp/product/B092MLT2J3)
- [USB C OTG Splitter](https://www.amazon.com/gp/product/B08C5FWQND)
- Normal HDMI Cable
- DisplayPort TO HDMI pigtail (Cable) (Pic is displayed wrong)
- TARGET (Anything you want to control)

## Another CSI example using the PCB splitter

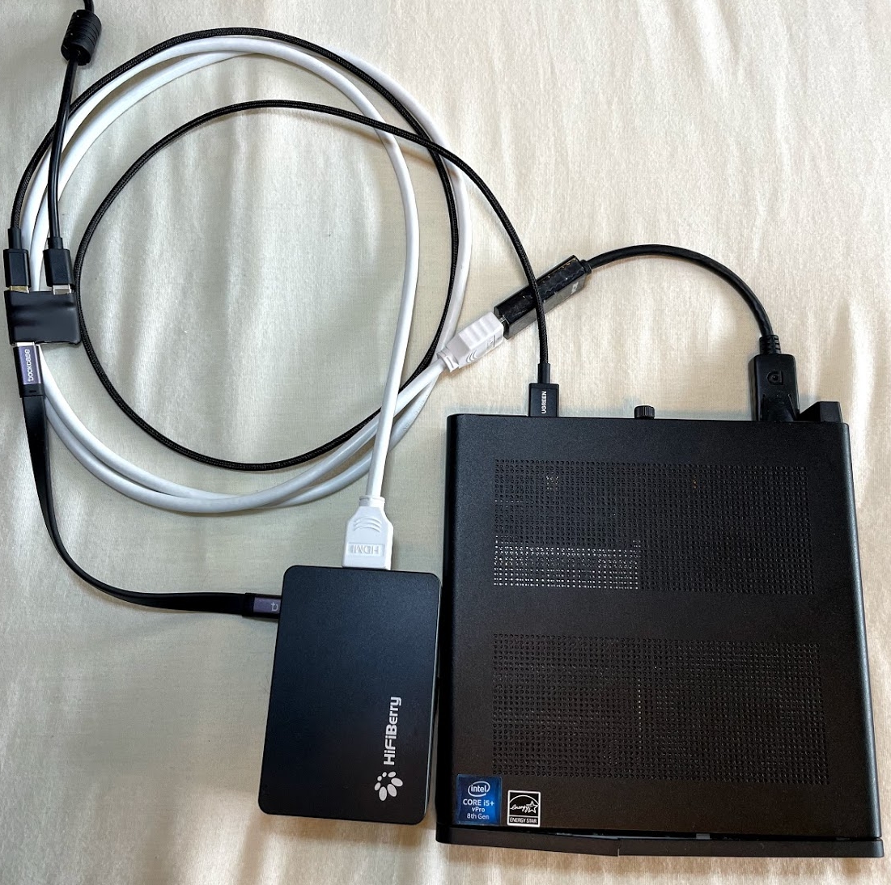
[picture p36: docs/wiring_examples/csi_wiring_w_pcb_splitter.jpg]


## HDMI-USB

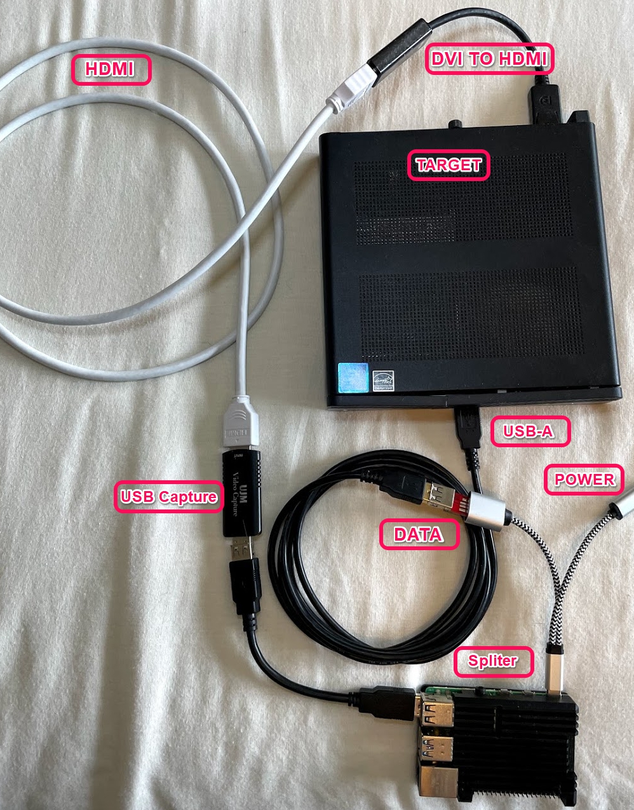
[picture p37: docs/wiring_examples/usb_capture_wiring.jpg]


## Direct connect to target

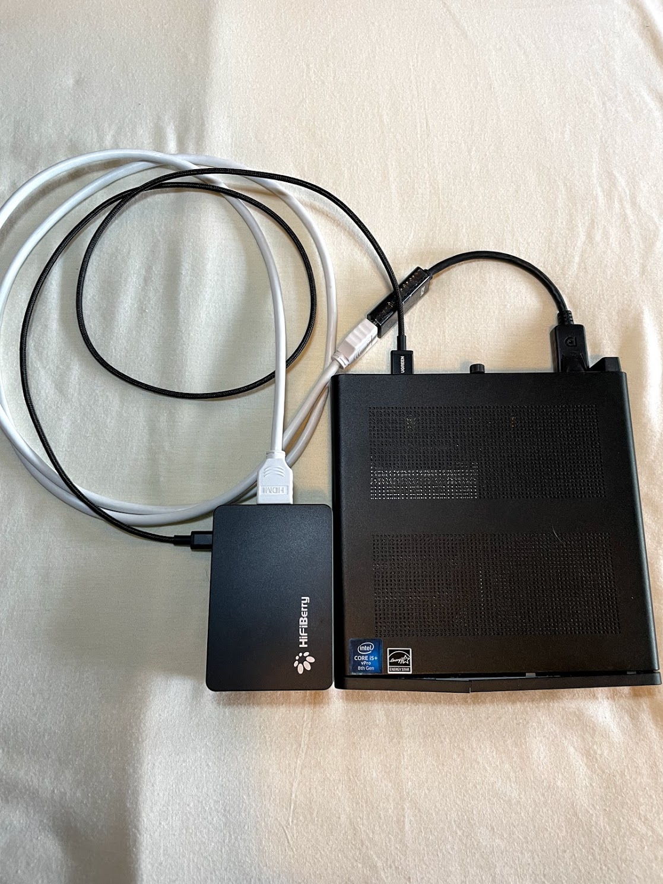
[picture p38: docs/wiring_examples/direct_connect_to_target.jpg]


Explanation of pic
- USB-C from PI to USB-A onto target which also powers the PI

Use case: 
- Trying to determine if the data cable is truly a data cable and not just a power cable
- Testing to see if the splitter or cable is defective
- Basic troubleshooting

## EZCOO wiring example
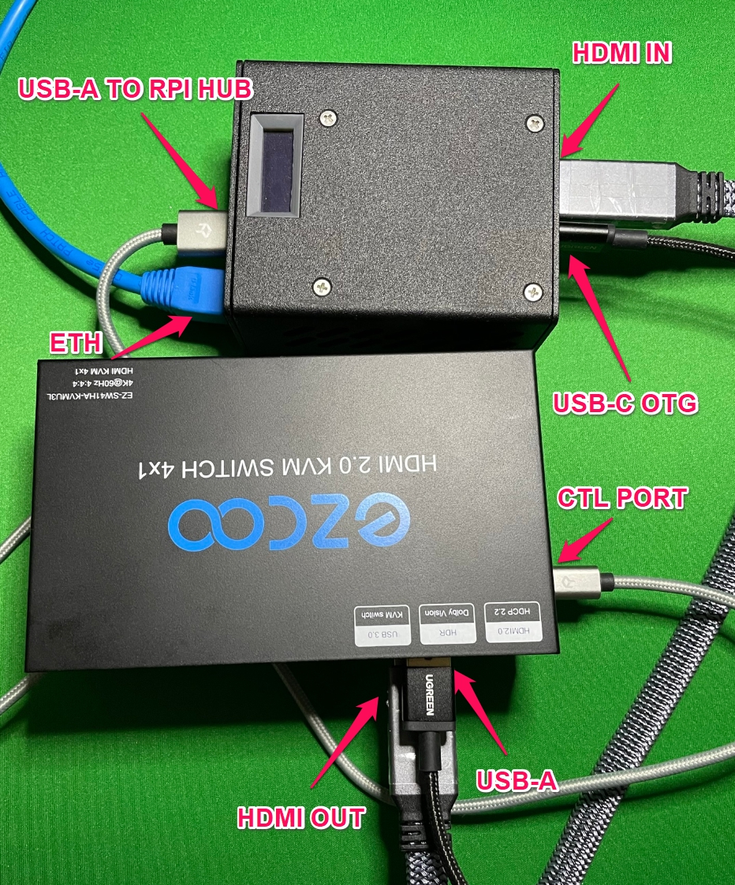
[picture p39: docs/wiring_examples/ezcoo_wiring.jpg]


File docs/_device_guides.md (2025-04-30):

---
search:
    exclude: true
---

<div class="grid" markdown>

[PiKVM V4 Mini & Plus](v4.md){ .md-button .md-button--stretch }

[PiKVM V3](v3.md){ .md-button .md-button--stretch }

[DIY PiKVM V2](v2.md){ .md-button .md-button--stretch }

[DIY PiKVM V1](v1.md){ .md-button .md-button--stretch }

</div>

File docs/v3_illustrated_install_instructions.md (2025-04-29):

---
title: Assembling PiKVM V3 HAT
description: How to build PiKVM V3 HAT from the assembly kit
---

# Assembling PiKVM V3 HAT

PiKVM V3 HAT is an assembly kit. You can build it without any case whatsoever, order a metallic case separately, or 3D-print a case yourself. These videos cover all those use cases.

??? tip "Video guide: Assembly with a metal case" 
    NOTE: OLED will not light up till step 5 is performed, video was performed after it was already configured, heat sinks NOT included.
    type:video

??? tip "Video guide: Assembly with or without a 3D-printed case"
    type:video

## Step 1

Get the parts that are not in the assembly kit:

* Raspberry Pi 4 with 1Gb RAM or more
* Heat sinks (Optional)
* MicroSD card (at least 16Gb, class 10 recommended)
* USB-C to USB-A cable
* HDMI cable
* [Straight Ethernet cable](./atx_board/straight.png)
* Power supply unit (5.1V 3A USB-C, recommended by the Raspberry Pi)

!!! tip
    * Please review the back of the box. All parts are required before the HAT is fully functional.
    * The USB-C bridge is located in with the ATX end which includes a pink foam spacer.
    * Please assemble the HAT onto the RPi and test all of the parts before installing in the case, it's easier to install in the case than to dissasemble it.
    * If going from a V2 to a V3, the splitter is **no longer needed**.

## Step 2

Remove contents from assembly kit box:

* 8x M.2 5x12mm screws for the case
* 4x M.2 5x12mm screws for the fan
* 4x bolts for the fan
* 1x fan (30x30x7mm 5v)
* 1x case top
* 1x case bottom
* 1x OLED display (0.91 IIC 128x32 LCD)
* 2x bottom plastic risers
* 1x plastic top riser
* 1x plastic OLED holder that is also a front riser
* 2x small FCC ribbon cables
* 1x small rubber square that break out to 4x small rubber feet

!!! warning "OLED is sensitive to pressure, do NOT push down on the very thin glass as it will crack and become non-functional"

## Step 3

Take bottom part of the case, insert the RPI4 into the bottom case at an angle, you will need to flex the other side ever so slightly to get it to slot in.

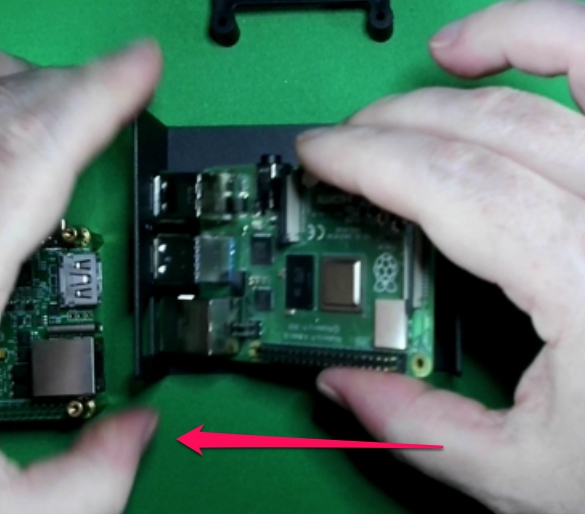
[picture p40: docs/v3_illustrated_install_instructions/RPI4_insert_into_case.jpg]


??? note "IF you bought heatsink's (sold seperatly), it's advised to install them now before installing the HAT"

## Step 4

Insert HAT at the same angle, take care to line up the pins on the Rpi with the HAT pin sleeve, the trick to this is to push the Rpi all of the way to the left then all of the way to the right for proper alignment, do NOT force till the pins are aligned. If properly aligned the pins will match up without issue.

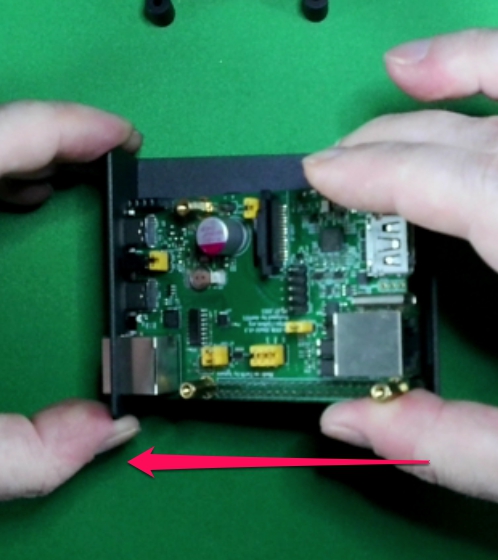
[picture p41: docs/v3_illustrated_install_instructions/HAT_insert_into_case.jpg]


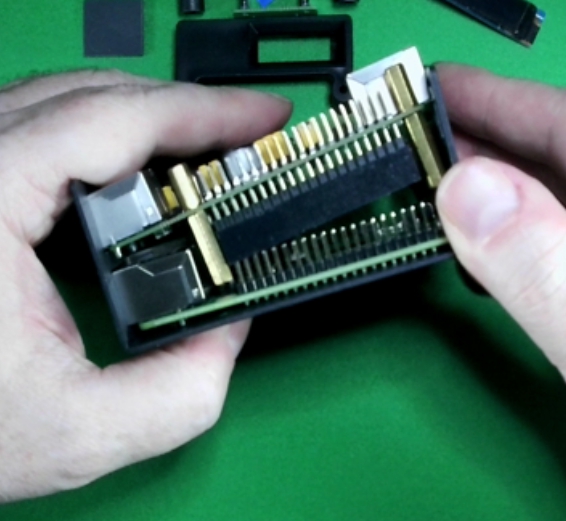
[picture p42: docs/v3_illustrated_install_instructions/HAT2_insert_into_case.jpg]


??? note "ALTERNATIVE: As an alternative to the above, you can pre assemble the hat+fcc cable onto the RPI4, then insert them into the bottom portion of the case however you will need to flex the sides more whereby creating a bigger gap when fully assembled."

## Step 5

There are 2 ways to insert the FCC cable, you can add it when you insert the RPI in Step 2 OR wait till you also have the HAT installed and slide it into the slot.

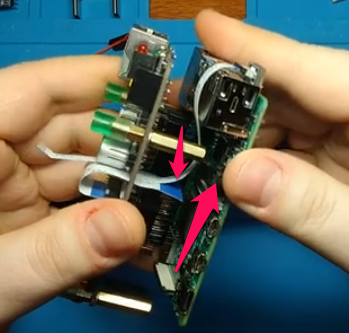
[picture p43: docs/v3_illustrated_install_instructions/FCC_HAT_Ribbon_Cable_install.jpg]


??? note "The blue stripes on the ends of the cable will ALWAYS face the side that will be used to tighten the FCC to the camera port or have it positioned towards the power - Ignore the smaller FCC cable that plugs into the USB, was phased out during the KS campaign. This image was used as a means of illustrating FCC placement and orientation"

## Step 6

Install the USB-C bridge.

??? note "This is packaged with the ATX board"
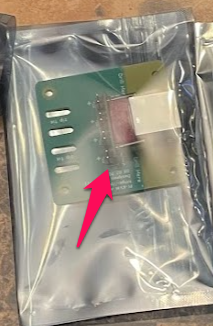
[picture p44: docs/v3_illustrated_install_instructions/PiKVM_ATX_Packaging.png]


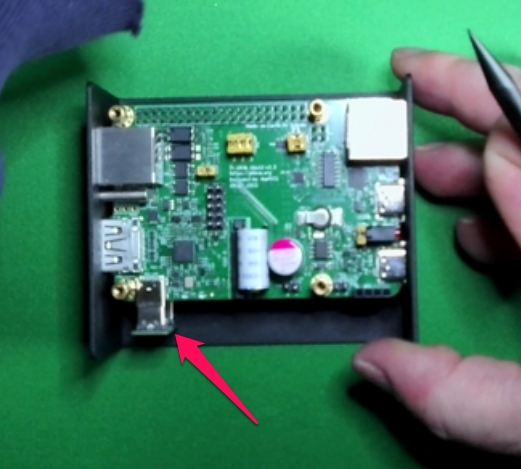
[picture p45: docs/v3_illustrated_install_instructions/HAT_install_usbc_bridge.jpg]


??? note "If you do not install this bridge, mouse/kb will not work"
??? note "HAT will still power on without this bridge installed"

## Step 7

Turn the bottom of the case upside down, install the 2 bottom plastic risers, it's best to install in a wing formation. Top first by inserting the top screws then slide the bottom part aligning the plastic to the holes then inserting the screws. At this point its OK to tighten the bottom screws. There is no need to use force, just tighten enough to prohibit movement.

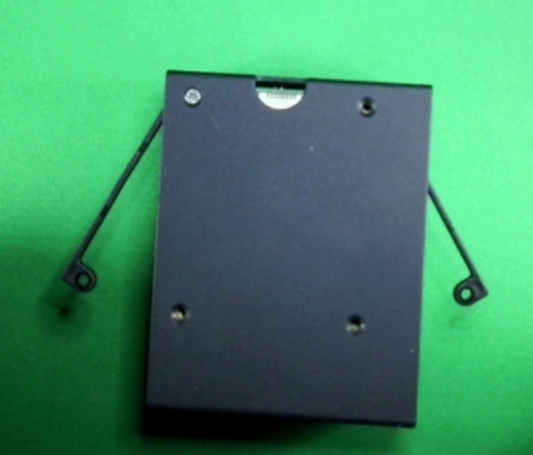
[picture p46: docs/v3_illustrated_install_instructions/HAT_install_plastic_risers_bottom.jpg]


## Step 8

Take the plastic OLED holder, turn the OLED over where the back side is facing you and insert at an angle so as to create a space between the OLED and holder arm, take a flat head screwdriver (medium normal) and twist it enough so you can clear the electronics on the bottom of the OLED and continue to gently slide in the remaining OLED till its fully inserted.

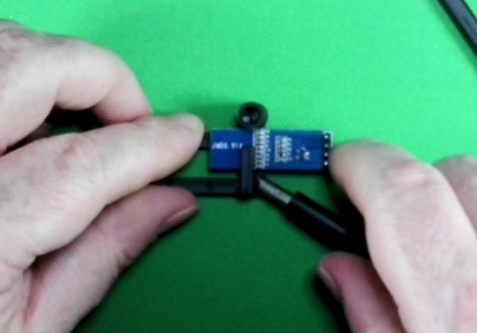
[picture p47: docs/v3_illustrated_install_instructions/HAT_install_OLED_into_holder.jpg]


!!! warning "Be careful on handling this display, slight pressure will damage the OLED, however in the event that this does happen, replacements are cheap and can be found in most electronic stores or Amazon, look for any IIC (I2C) .91 inch display for Arduino" 

## Step 9

Insert the OLED holder with the OLED display into the plug by gently rocking it back and forth till it's fully inserted.

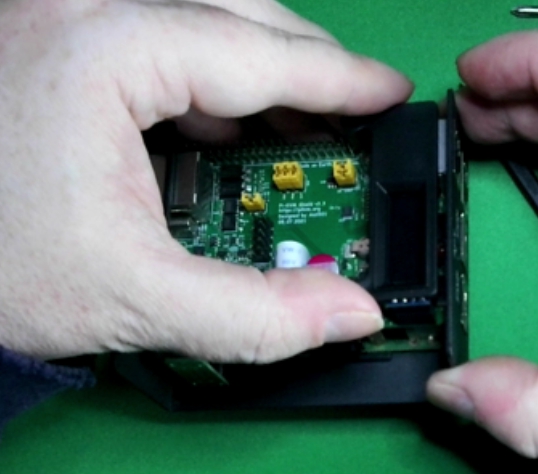
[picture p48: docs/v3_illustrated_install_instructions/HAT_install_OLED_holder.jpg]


## Step 10

Install plastic spacer.

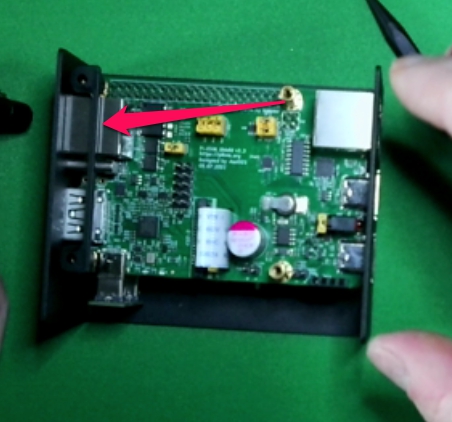
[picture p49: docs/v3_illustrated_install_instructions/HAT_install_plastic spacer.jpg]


## Step 11

Install the screws and bolts to secure the fan, it does not matter the orientation of the fan, push or pulling air will result in the same behavior, its personal preference.

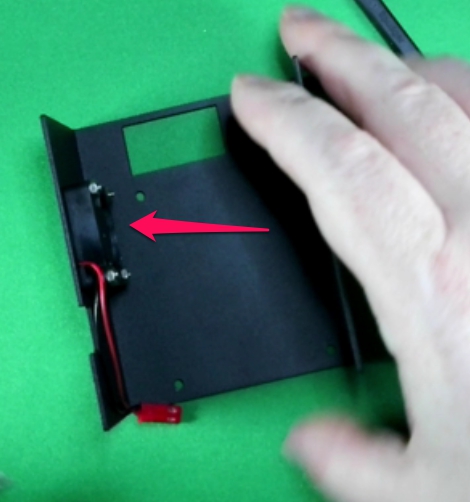
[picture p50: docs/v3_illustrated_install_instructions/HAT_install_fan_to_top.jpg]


## Step 12

Insert the fan leads and align Red with positive and Black with negative.

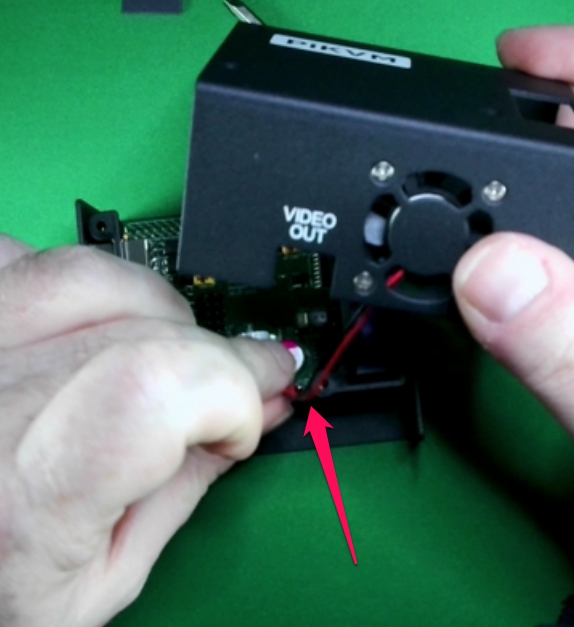
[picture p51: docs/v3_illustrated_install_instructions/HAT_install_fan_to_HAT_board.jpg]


!!! warning "You can damage the fan if installed incorrectly"

## Step 13

Install the top of the case to the bottom, use the 4 remaining screws to secure the top.

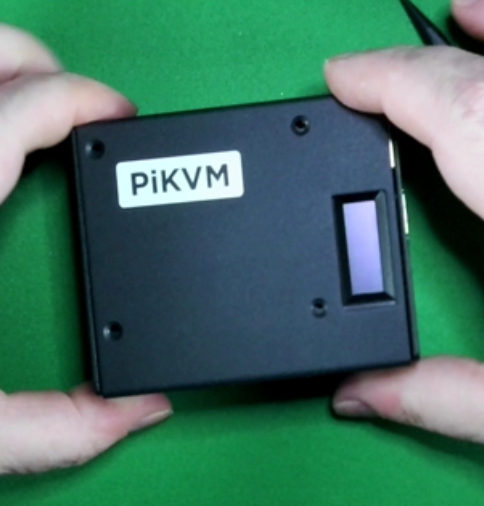
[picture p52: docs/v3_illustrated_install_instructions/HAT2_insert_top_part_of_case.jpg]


## Step 14

Please follow the [V3 quick start](../v3/) guide to activate your PiKVM.

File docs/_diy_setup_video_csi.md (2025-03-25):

---
search:
    exclude: true
---

Insert the flexible flat cable of the HDMI-CSI bridge into the narrow white connector on the Raspberry Pi
(the closest one to big USB sockets). It is labeled `CAMERA`. To insert you need to open the connector first.
On the Raspberry Pi side you can gently lift the black part up and a little bit sideways:

| Opening the MIPI CSI slot on the Raspberry Pi |
|-----------------------------------------------|
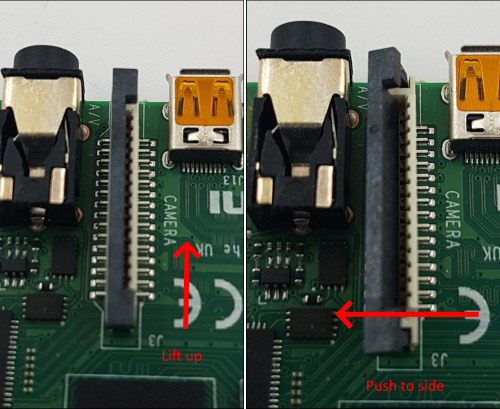
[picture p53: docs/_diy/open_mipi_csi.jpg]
|  |

For the HDMI-CSI bridge this operation depends on the version you bought.
Either pull it gently up as on the Raspberry or push it sideways.
Make sure that the cable is inserted on the correct side and until it stops, and then push the black latch back.
Avoid using force when pushing the cable in, as the slots bond to the PCB is quite fragile.
Never connect or disconnect the flat cable from a powered device. This is not Plug-and-Play, and you can damage it.
Also use only the cable that was included with the device package, or make sure that the third-party cable has the correct pinout.

| HDMI-CSI bridge connected to Raspberry Pi 4 |
|---------------------------------------------|
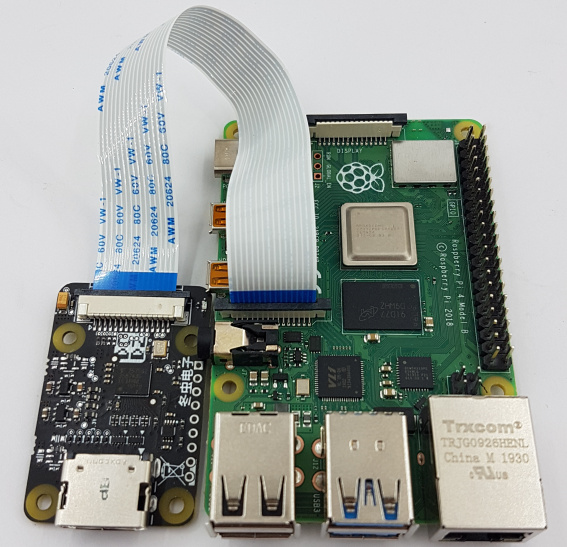
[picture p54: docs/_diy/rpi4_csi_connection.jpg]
|  |

| HDMI-CSI bridge connected to Raspberry Pi 2 W (using the adapter cable) |
|-------------------------------------------------------------------------|
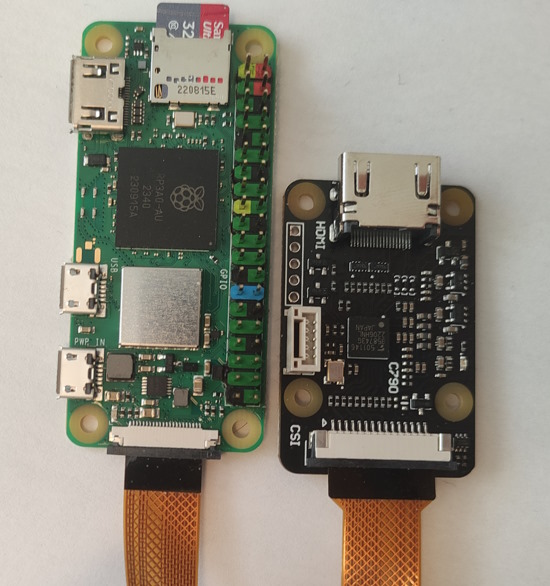
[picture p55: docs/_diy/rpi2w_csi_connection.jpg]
|                 |

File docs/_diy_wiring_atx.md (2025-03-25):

---
search:
    exclude: true
---

To control the power, two display LEDs (power and HDD activity) and two buttons (power and reset) are provided
on the front panel of the computer case. They are connected by wires to pins on the motherboard.

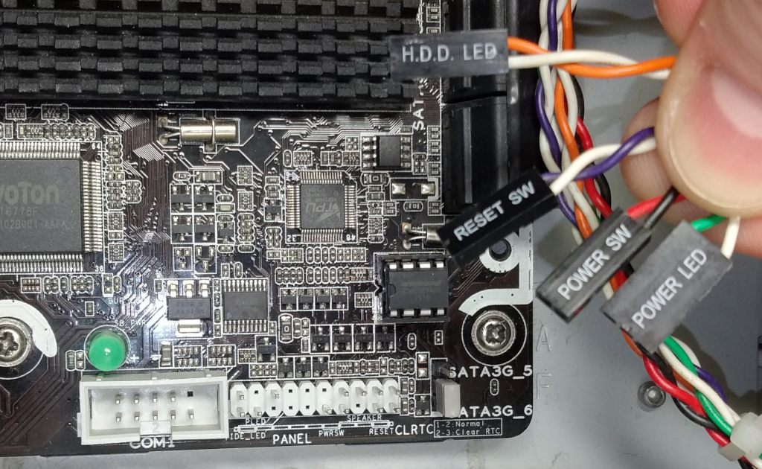
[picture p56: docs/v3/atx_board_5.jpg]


All you have to do is connect the PiKVM ATX controller to their wires by making a parallel connection.
Please note that the pinout differs on different motherboards, so before you continue,
check the documentation on your motherboard for correct pinout.

The following illustration shows how the connection between the power LED and the power button should be performed:

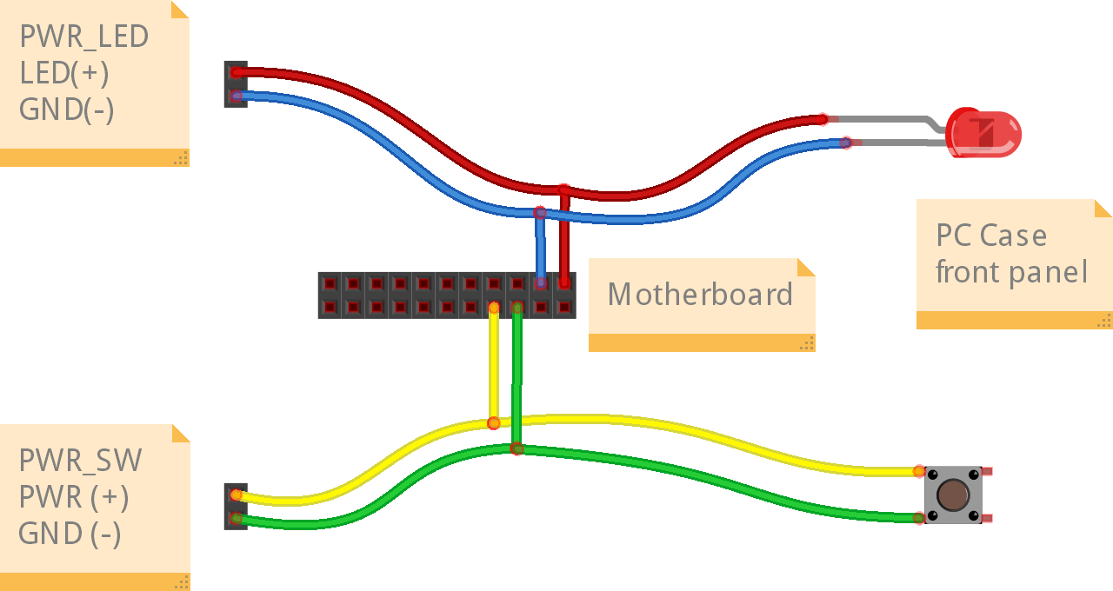
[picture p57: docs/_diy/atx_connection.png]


On the left are the wires from the PiKVM ATX controller, the pad in the middle indicates the pins on the motherboard,
and on the right are the LED and button of the target host. The implementation of this scheme is left to your discretion
and can be performed, for example, by cutting wires and performing twisting, followed by insulation with duct tape.

Be careful and respect the polarity of the LEDs. The polarity of the button does not matter (they have no polarity at all).
The connection of HDD LED and reset switch is performed in the same way.

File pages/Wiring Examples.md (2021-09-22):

### Some example wiring setups

# CSI (Geekworm) (Any brand will be the same)


List of items: (WARNING! Links may dissappear or no longer work, this just gives you an idea)

- USB-A male to USB-A male (For data)
- [PortaPow USB Power Blocker](https://www.amazon.com/gp/product/B092MLT2J3)
- [USB C OTG Splitter](https://www.amazon.com/gp/product/B08C5FWQND)
- Normal HDMI Cable
- DisplayPort TO HDMI pigtail (Cable) (Pic is displayed wrong)
- TARGET (Anything you want to control)

# Another CSI example using the PCB splitter


# USB


# Direct connect to target


Explanation of pic
- USB-C from PI to USB-A onto target which also powers the PI

Use case: 
- Trying to determine if the data cable is truly a data cable and not just a power cable
- Testing to see if the splitter or cable is defective
- Basic troubleshooting

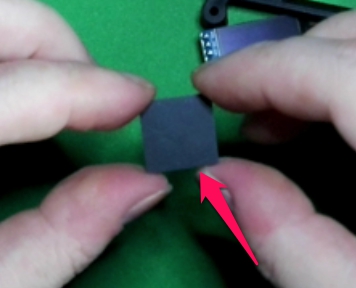
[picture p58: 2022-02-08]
docs/v3_illustrated_install_instructions/v3_feet.jpg

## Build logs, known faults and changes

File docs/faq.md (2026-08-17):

---
title: FAQ & Troubleshooting
description: Frequently asked questions and troubleshooting for your PiKVM
---

As a first step, we recommend carefully reading our documentation on [GitHub](https://github.com/pikvm/pikvm) or the updated [documentation](https://docs.pikvm.org). Most steps to successfully set up your PiKVM are already described there.

If you run into any issues you can check this page which will list common errors. If that still doesn't help you you're welcome to raise an [issue ticket](https://github.com/pikvm/pikvm/issues) or [contact our Support](https://pikvm.org/support/) for further help.

## Common questions

??? question "Where can I get a memory card image for PiKVM?"
    See here: https://pikvm.org/download

??? question "Can I connect multiple servers to a single PiKVM?"
    Yes, but it requires additional work to set up. See [this page](multiport.md).

??? question "How can I get the access to PiKVM in my local network over Internet?"
    You can use port forwarding for port 443 on your router if it has an external IP address. In all other cases, you can use the excellent free VPN service [Tailscale](tailscale.md), which can be configured on PiKVM with a [few simple commands](tailscale.md).

??? question "Can I assign a static IP to a PiKVM"

    Yes, we highly suggest using this [document](https://docs.pikvm.org/on_boot_config/#other-available-options) first for those that are not Linux savvy.

    [ONLY FOR ADVANCED LINUX USERS]
    
    Edit file `/etc/systemd/network/eth0.network` for Ethernet or `wlan0.network` for Wi-Fi and edit the `[Network]` section:

    ```ini
    [Network]
    Address=192.168.x.x/24
    Gateway=192.168.x.x
    DNS=192.168.x.x
    DNS=192.168.x.x
    ```

    Don't forget the `/24` suffix (CIDR), otherwise it will not work and your PiKVM will become unreachable.

??? question "How can I disable IPv6 on PiKVM?"

    To do this, you need at least KVMD 3.301 installed on your device. If this is not the case, update the OS.

    Next, append the `ipv6.disable=1` parameter to `/boot/cmdline.txt` and perform `reboot`.

??? question "How do I recover my PiKVM, it cannot be reached now"

    1. Take the USB-C end cable you have for your target and move to the PiKVM IOIO port or CON port
    2. Take the USB-A end cable and put this on the HOST(The controlling PC)
    3. Turn on or reboot your PiKVM, you should now see a COMx port on your HOST PC
    4. Connect using something like Putty, use 115200 as your baud rate
    5. Edit the file using nano or whatever text editor you are comfortable with, save the file
    6. Reboot your PiKVM, check for functionality
    7. If still unreachable, edit the same file to fix it
    8. ONLY Disconnect the IOIO port once you have fully recovered your PiKVM and place this back onto the Target system

??? question "Can I use PiKVM for gaming?"
    No, because:

    * For HDMI-CSI bridge, bus bandwidth is not enough to transmit more than 1080p50.
    * For HDMI-USB dongle, high latency and low video quality.
    * General hardware video capture differs from software streaming and introduces additional latency.

??? question "Where does the cursor/video latency come from?"
    [See here](latency.md).

??? question "Can PiKVM do 4K video?"
    * For HDMI-CSI bridge, no. There is not enough bandwidth in the CSI bus for that much data. 1080p50 will max out the bandwidth.
    * For the USB capture devices: technically yes, they will down sample to something smaller to meet the USB 2.0 bandwidth limitations, so the source may be 4k, but the stream will not.
    * The 4K real-time video will not fit through the network anyway.

??? question "I am expecting to see 60fps and I am not, why?"

    PiKVM receives the entire signal, but then the encoding is the bottleneck depends of the device model.

    [PiKVM V4](v4.md) is able to encode full 60fps with [enabled H.264 boost](video.md#boost-pikvm-v4-to-60fps-h264).

    [PiKVM V3](v3.md) and DIY can't process 60Hz and is only able to capture 50Hz, and they take every second frame to encode, so you get only 25fps. The reason why V3 and DIY does not encode 30 out of 50 is that the picture will be jerky, but smooth at 25.

??? question "Does PiKVM support sound?"
    Yes but the only officially supported version is the PiKVM V3+ devices, V2 we will attempt best effort but ultimately we do not support CSI modules or USB.

??? question "Can I power the Pi via PoE?"
    Yes! 

    For a POE HAT
    
    You still need a splitter to ensure you isolate the 5v connection between the Raspberry Pi and host PC to prevent back power issues that can cause instability or damage to either the host PC or the Pi. Power/Data cable + USB power blocker would work.

    For a POE Splitter
    
    No, there is no need for anything additional, you can power your RPi and or the PiKVM Mini with the USB-C variant.

??? question "Do I need a USB splitter for data and power lines? Why do I need one?"

    * This is the case of DIY PiKVM. You need a splitter to prevent backpowering from PiKVM to the host over the USB cable. See detauls [here](v4.md#required-parts).

    * This is not needed if you have a PiKVM V3 and V4, as they splits USB power and data on the board.

??? question "Can I use PiKVM with non-Raspberry Pi boards (Orange, Nano, etc)?"
    Yes, but you will have to prepare the operating system yourself. For the PiKVM software, you will need to replace some config files (such as UDEV rules). If you are a developer or an experienced system administrator, you will not have any problems with this. In addition, we are open to patches. If you need help with this, please contact us via [Discord](https://discord.gg/bpmXfz5) (#unofficial_ports channel).

??? question "Is PiKVM OS its own custom distro?"
    No. PiKVM OS is an [Arch Linux ARM](https://archlinuxarm.org) with our own repository for KVM-related packages. We distribute OS images (that is, our Arch Linux ARM build) to simplify installation, since PiKVM requires some tuning of the OS and special partitioning of the memory card.

??? question "Why is PiKVM OS based on Arch Linux ARM and not Raspbian / Raspberry Pi OS?"
    There are several reasons:

    * Several years ago, when PiKVM was just starting out, Raspbian didn't have a minimalistic image and the transition to systemd was in full swing, which is why the distribution was not too stable.
    * Raspbian did not have all the necessary packages in the repositories to satisfy most software dependencies.
    * PiKVM was born as a pet project, and the founder likes Arch the most.

    However, we plan to provide an alternative OS image based on Raspberry Pi OS in the future - now it is quite stable.

??? question "Can I use an iPad on PiKVM?"
    * Yes, with the correct hardware you can control an iPad.
    * In the opposite sense - yes, use VNC and use JUMP app (fully-featured but more expensive), or bVNC (cheap). RealVNC does NOT work.

??? question "How do I add my own SSL cert?"
    If you have a certificate (making a cert falls outside the scope of PiKVM - please reference OpenSSL documentation or use [Let's Encrypt](letsencrypt.md)), replace keys in `/etc/kvmd/nginx/ssl`, edit `/etc/kvmd/nginx/ssl.conf` if necessary and restart `kvmd-nginx` service.

??? question "How do I emulate various USB devices on the target machine?"
    For a detailed description, see [here](id.md).

    Use the following USB database to get the desired devices: https://the-sz.com/products/usbid or https://devicehunt.com.

??? question "Can I run a desktop on PiKVM?"
    Yes, but it's strongly not recommended OR supported as this OS should be used in read-only mode and it will need read-write enabled all of the time, however if you insist on running one, instructions are [here](https://www.linuxfordevices.com/tutorials/linux/how-to-install-gui-on-arch-linux).

??? question "How do I blank the oled screen?"
    Please run the following:
    ```
    # systemctl disable --now kvmd-oled kvmd-oled-reboot kvmd-oled-shutdown
    # kvmd-oled --height=32 --interval=0 --clear-on-exit --text=x
    ```
    To re-enable the display:
    ```
    # systemctl enable --now kvmd-oled kvmd-oled-reboot kvmd-oled-shutdown
    ```
    
??? question "How do I rotate the OLED display?"
    Please run the following:
    ```
    1. mkdir -p /etc/systemd/system/kvmd-oled.service.d
    2. Create file /etc/systemd/system/kvmd-oled.service.d/override.conf:
    [Service]
    ExecStart=
    ExecStart=/usr/bin/kvmd-oled --height=32 --clear-on-exit --rotate=2
    ```

??? question "I am getting a 500/503 error when I try and access the main KVM page!"
    This maybe due to a few of the following:

    * Missing `/etc/kvmd/override.yaml` file, to resolve it run `rw; touch /etc/kvmd/override.yaml; ro`
    * Bad YAML syntax, edit your `/etc/kvmd/override.yaml` file and undo what you did and restart PiKVM.

    To validate your configuration run `kvmd -M` before reboot.

??? question "How can I use the serial console to gain access to other devices"
    You need to stop the service which listens on the `/dev/ttyAMA0`:

    ```
    rw
    systemctl stop serial-getty@ttyAMA0.service
    ```

    If you want this change permanent (not starting again after reboot), you can disable this service, ('enable' to reverse this decision):

    ```
    systemctl disable serial-getty@ttyAMA0.service
    ```

    !!! note
        * Only USB OR the RJ-45 serial connector will work, you can't use them together!
        * If you disable the service permanently, you can't recover your device via serial console if you need this.
        * There are some reports, that you need to remove `ttyAMA0` from /boot/cmdline.txt, but this is not needed on new installations.

??? question "Can I run PiKVM in a docker?"
    No, technically it might be possible but the OS requires many specific settings that cannot be performed inside the container.

??? question "How can I change the HTTP/HTTPS ports?"

    To do this, you need at least KVMD 3.301 installed on your device. If this is not the case, update the OS.

    Add some of these lines to `/etc/kvmd/override.yaml`:

    ```yaml
    nginx:
        https:
            port: 4430
        http:
            port: 8080
    ```

    After that, restart the server: `systemctl restart kvmd-nginx`.

??? question "Can I control IR devices using PiKVM?"
    This goes far beyond the usual use of PiKVM, so there is no official way to do this, but there are [some ways](https://github.com/pikvm/pikvm/issues/291) from the community that you can try if you know how to handle a soldering iron.

## First steps

??? question "I can't find the PiKVM IP address in my network"

    Follow the device guide of your PiKVM [here](cheatsheet.md).

??? question "What is the default password? How do I change it?"
    See [here](auth.md).

??? question "How do I add another user?"
    See [here](auth.md#changing-the-kvm-password).

??? question "How do I get root access in the web terminal?"
    See [here](auth.md#root-access-in-the-web-terminal).

??? question "Where is the PiKVM configuration located?"
    See [here](config.md)

??? question "I can't edit any file on PiKVM. Why is the system in read-only mode?"
    The PiKVM file system is always mounted in read-only mode. This measure prevents it from being damaged by a sudden power outage. To change the configuration you must first switch the filesystem to write mode using the command `rw` from root. After the changes, be sure to run the command `ro` to switch it back to read-only. If you get a message that the file system is busy, then the easiest way is to perform a `reboot`.

??? question "I want to get read-write filesystem all of the time"
    !!! danger "DON'T DO THIS"
    !!! danger "DON'T DO THIS"
    !!! danger "DON'T DO THIS"

    **Seriously, DON'T**. Read-only mode increases the life of the memory card and protects the filesystem from power loss failures. See the question above ^ ^ ^

    You can turn it off, but don't say you weren't warned.

    ??? danger "DON'T OPEN THIS SPOILER AND DON'T DO THIS"
        Okay, fine.

        * Edit `/boot/cmdline.txt` and change option `ro` to `rw`.
        * Do the same in `/etc/fstab` for the `/boot` partition.
        * Comment `tmpfs` lines in `/etc/fstab` for `/var/lib` and `/var/log`.
        !!! danger "But again: DON'T DO THIS"
        !!! warning "If you do plan on doing this, no assistance will be provided beyond this point other than the existing documentation."

??? question "How to set the date, time and timezone from command line?"
    * Become root with the command `su -` or `sudo -s`.
    * Enable read/write with the command `rw`.
    * Find your timezone string e.g. `timedatectl list-timezones` or `timedatectl list-timezones | grep -i australia`.
    * Set the timezone with `timedatectl set-timezone <YourTimeZoneHere>` e.g. `timedatectl set-timezone Australia/Victoria`.
    * Stop the time syncing service with `systemctl stop systemd-timesyncd` as this will prevent the next step if running.
    * Set the time and date with `timedatectl set-time 'YYYY-MM-DD HH:MM:SS'` e.g. `timedatectl set-time '2023-02-26 14:50:10'`.
    * If you have hardware clock e.g. V3+, update it with `hwclock --systohc` , then check it with `hwclock --show`.
    * Switch filesystem to RO-mode with the command `ro`.

??? question "How do I update PiKVM with the latest software?"

    {!_update_os.md!}

??? question "How do I install or remove packages in PiKVM OS?"
    PiKVM OS is based on Arch Linux ARM and uses the [pacman](https://wiki.archlinux.org/title/Pacman) package manager.

    * Ensure the date is correct: `date`. Otherwise you may get the error `SSL certificate problem: certificate is not yet valid`
    * It is recommended to update the OS before installing new packages (see the tip upper ^^^).
    * Switch filesystem to RW-mode: `rw`.
    * Find some packages (`emacs` for example): `pacman -Ss emacs`.
    * Install it: `pacman -Syy` to update local packages list and `pacman -Su emacs` to install.
    * Remove it: `pacman -R emacs`.
    * Switch filesystem to RO-mode: `ro`.

??? question "I don't need ATX functions. How do I disable this in the Web UI?"
    If you don't need ATX power control you can disable the relevant Web UI menu in `/etc/kvmd/override.yaml`:

    ```yaml
    kvmd:
        atx:
            type: disabled
    ```

    ... then restart `kvmd`:

    ```
    # systemctl restart kvmd
    ```

??? question "How do I disable the web terminal?"
    ```
    # rw
    # systemctl disable --now kvmd-webterm
    # ro
    ```

??? question "How do I completely disable authorization in PiKVM?"

    See [here](auth.md).

??? question "Can I have different hostnames for each of my PiKVMs?"
    Yes! And it's easy to do. Using a SSH session or the web terminal:

    ```console
    [root@pikvm ~]# rw
    [root@pikvm ~]# systemctl restart systemd-hostnamed
    [root@pikvm ~]# hostnamectl set-hostname yournewhostname.domain
    [root@pikvm ~]# reboot
    ```

??? question "Why not add software support for another codec?"
    Encoding is a heavy process and will add significant latency, its best to have hardware support to avoid additional latency.

## Video problems

??? question "I can see the video but I can't see the WebRTC / video mode switch"
    [WebRTC and Direct H.264](video.md) modes are only available on V2+ platforms with HDMI-CSI capture device,
    including PiKVM [V3](v3.md) or [V4 Plus/Mini](v4.md). See the [modes guide](video.md) to solve any problems.

??? question "PiKVM does not show the video from the computer at all"
    * Double-check that the video capture device is connected correctly.
    * Some laptops do not output any signal until you switch the output (usually via the FN + and an F5 key on the keyboard).
    * Your computer may have turned on sleep mode for the monitor. Move the mouse to turn it off.
    * For windows you might need to check for the active signal resolution. To change the active signal resolution you have to go to Settings>System>Display>Advanced display settings>Display adapter properties then, click "List All Models" and choose the one you want. Keep trying different Hz settings.

??? question "The video works in the booted OS, but not in the BIOS/UEFI"
    This problem appears on Intel NUC, GA-H77-DS3H, and some other devices when using a CSI bridge. All you need to do is [change the EDID data](edid.md). This is the information about supported resolutions that the CSI bridge reports to your computer.

??? question "Glitchy or wrong BIOS/UEFI resolution"
    On some motherboards, the BIOS may be displayed at a lower resolution, or with some rendering issues/glitches, specially on newer ASUS ones. Like this:

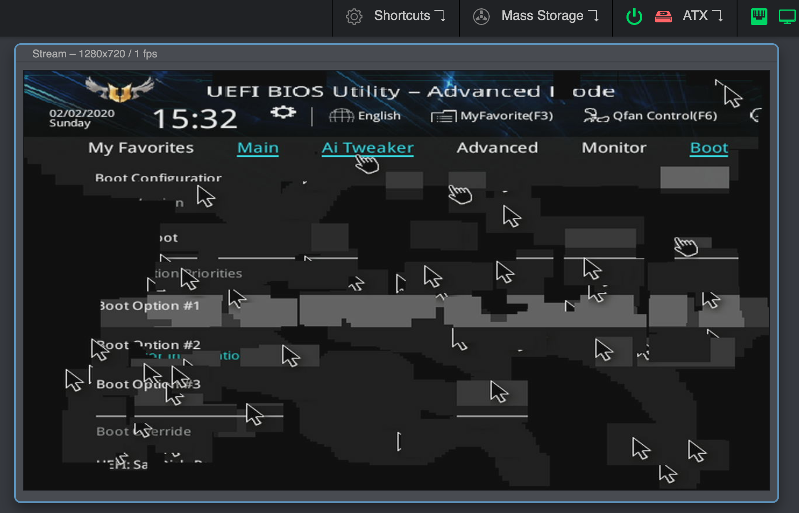
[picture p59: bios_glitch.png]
ASUS BIOS glitch
    

    This can be solved by enabling the **Compatibility Support Module (CSM)** in your BIOS, usually under the **Boot** options.

    If you can't or don't want to enable the CSM, you can try connecting a DisplayPort (DP) monitor, or a [dummy plug](http://amazon.com/s?k=displayport+dummy+plug). If you remove the DP cable/adapter the bug will reappear.

    If none of this works, try connecting the DP cable first, boot into the BIOS, disable the CSM and shutdown (do not restart) your PC. Then, boot into the BIOS and enable the CSM before shutting down your PC. Then connect the HDMI and turn your PC on again.

??? question "There is no video in GRUB2, but there is before and after"
    Sometimes this can be caused by the specifics of the BIOS/UEFI and how GRUB2 works with video.

    This can be solved by enabling the **Compatibility Support Module (CSM)** in your BIOS, usually under the **Boot** options. The video mode will be located in the same section. Switch the **Video** mode from **UEFI** to **Legacy**.

??? question "Why does the CSI bridge does not work with official Raspberry Pi PoE HAT?"
    Details [here](https://github.com/pikvm/pikvm/issues/6). The reason is that the [official HAT](https://www.raspberrypi.org/products/poe-hat) has a built-in fan controller that conflicts with the TC358743 chip of the bridge. The solution is to disable the fan control and connect the fan to the power line so that it works continuously. To turn off the controller you need to add the line `disable_poe_fan=1` to `/boot/config.txt`.

??? question "The video freezes a few seconds after the start, restarting the Web UI or VNC does not help"
    The story is [here](https://github.com/raspberrypi/firmware/issues/1562). Very very rarely, Raspberry Pi boards can have a hardware defect that causes some of the chip blocks to be unstable under normal power. The solution is to slightly increase the power supply, as you would when overclocking. Add `over_voltage=1` (or `over_voltage=2` if previous doesn't help) to `/boot/config.txt` and perform `reboot`.

    To make sure that you are facing this particular problem, first perform a diagnostic:

    * Boot the PiKVM without the specified options.
    * Open Web-UI and wait for freezing.
    * Click `System -> Reset Stream`.
    * Click `System -> Open log` and make sure that the log contains messages like `H264: Can't wait for the VCOS semaphore`.
    * Make sure that the last message from ustreamer was `H264: Configuring MMAL encoder` (not counting messages about connecting and disconnecting stream clients).

??? question "No image from computer with Linux + Awesome WM"
    Sometimes Awesome WM on Linux can't recognize a video output change on a cable. That is, if the cable was first inserted into the monitor, and then you reconnected it to PiKVM - it may happen that you will not see the image. It seems that the problem is Awesome WM, since for example with KDE, it is not reproducible. If you turn on your workstation with PiKVM already connected, everything will work fine.

??? question "Windows shows limited Available Resolutions"
    This is due to a driver issue. A possible resolution can be found [here](https://github.com/pikvm/pikvm/issues/577#issuecomment-998713201).

??? question "Firefox ESR from the Debian repo shows the black screen in H.264 mode"
    Make sure the OpenH264 Plugin both exists and is enabled (known issue on Debian GNU/Linux). Press `Ctrl+Shift+A` to open the Add-ons Manager, then press `Plugins`. You should see *OpenH264 Video Codec provided by Cisco Systems, Inc.*. Make sure it is enabled by pressing the "more options" button (3 horizontal dots), then pressing `Always Activate`.

??? question "Apple TB/USB-C HDMI video doesn't work"
    A possible solution can be found [here](https://github.com/pikvm/pikvm/issues/1011).

??? question "I am seeing a NO SIGNAL, what can I do?"
    If you are using PiKVM V2 or a V3, you need to ensure that your target is using the maximum resolution **1920x1080@50Hz**, 60Hz will not work.

    If you are using the PiKVM V4, ensure that you are getting a signal out from the target by using a physical monitor using the same exact cable/dongle, ensure that you are using the maximum resolution **1920x1200@60hz**, 2K/4K resolutions will not work.

## USB problems (keyboard, mouse, mass storage, etc)

??? question "My computer does not recognize USB of PiKVM V2+ at all"
    * Make sure that you have used the correct USB cable with DATA lines to connect the OTG port for the Raspberry to the computer. You may have decided to use a USB hub instead of a Y-cable and **it won't work**. Use good cables and follow the instructions :)
    * In rare cases, some very buggy BIOS's do not like HID and Mass Storage in one USB device. You can either [disable Mass Storage](msd.md#disable-msd), or use the [Pico HID](pico_hid.md) to physically separate them.

??? question "BIOS/UEFI does not recognize USB of V2+, but computer does"
    If you are using a USB hub or USB PCI controller, this may not be handled by your BIOS. Try to use another USB port. Some ports may have a built-in hub on the motherboard and a buggy BIOS that can't handle it.

??? question "My keyboard works in BIOS/UEFI, but my mouse does not"
    The BIOS does not support absolute mouse mode, which is preferred by PiKVM. In this case, [you can enable relative or dual positioning mode](mouse.md).

??? question "My mass storage drive works (I can boot an image from PiKVM V2+), but my keyboard/mouse does not"
    In rare cases, some very buggy BIOS's does not like HID and Mass Storage in one USB device. You can either [disable Mass Storage](msd.md#disable-msd), or use the [Pico HID](pico_hid.md) to physically separate them.

??? question "Buggy absolute mouse on Windows 98 as managed server"
    How to fix:

    * [V2+](mouse.md#fixing-the-absolute-mouse-on-windows-98).
    * [Pico HID](pico_hid.md#configuring-the-hid-modes).

??? question "The mouse does not work with NVR/DVR CCTV"
    Often these devices have a buggy USB driver that does not understand an absolute mouse and/or a mouse with horizontal scrolling. In this case, the following configuration for `/etc/kvmd/override.yaml` will help you:

    ```yaml
    kvmd:
        hid:
            mouse:
                absolute: false
                horizontal_wheel: false
            mouse_alt:
                device: ""
    ```

    It will make the relative mouse without horizontal scrolling the only mice.

??? question "There's big mouse latency on another Raspberry Pi as managed server"
    Unusual case: RPi4 is used as a PiKVM to control RPi3. In this case, the mouse delay may be several seconds. To fix it, append `usbhid.mousepoll=0` to the boot line in `/boot/cmdline.txt` on the managed server (i.e. RPI3 in our case) and reboot it. [Source.](https://www.reddit.com/r/pikvm/comments/m4xs79/slow_mouse_response/)

??? question "What speed is the USB OTG port?"
    Per the official RPI documentation, this is a limitation of the SoC.  The OTG port is only USB2.0, so is limited to 455 Mbit/s.

??? question "On MacOSX, my mouse/keyboard does not work!"
    There are a few fixes the community has suggested:
    
    If using a USB-C to USB-C cable, you need to use the included USB-C to USB-A cable then use a USB-A to USB-C adapter
    
    You may need to allow new accessories to connect. [Source](https://support.apple.com/en-us/102282)

## Web UI problems

??? question "Chrome reports a Certificate Issue when I try to access the PiKVM web interface"
    The latest versions of Chrome do not allow access to the page with a self signed certificate, so if you see the following screen when loading the PiKVM website:

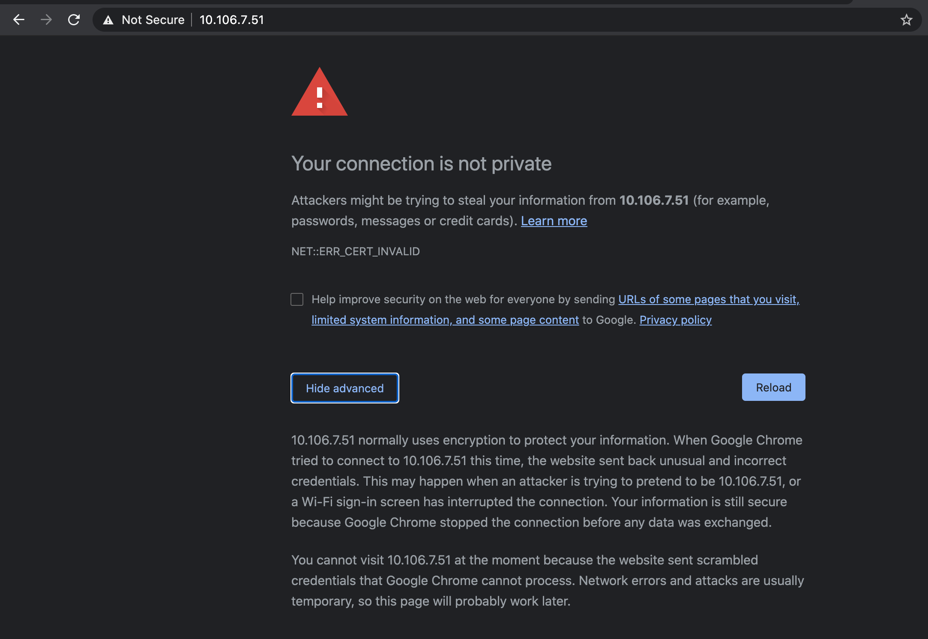
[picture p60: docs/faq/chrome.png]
Chrome Blocking
    

    You can proceed by typing `thisisunsafe` and Chrome will then load the page. Also see [Let's Encrypt](letsencrypt.md) page.

??? question "The Web UI doesn't work properly in Firefox while it works fine in Chrome"
    This might be related to your specific hardware combination or browser hardware acceleration. Try [disabling hardware acceleration in Firefox](https://support.mozilla.org/en-US/kb/hardware-acceleration-and-windowblinds-crash) or updating your GPU and chipset drivers.

??? question "Unexpected interruption while loading the image for Mass storage drive"
    If problems occur when uploading even a small disk image it may be due to unstable network operation or antivirus software. It is well known that Kaspersky antivirus cuts off PiKVM connections during uploading, so you should add the PiKVM website to Kaspersky's list of exceptions or not filter web requests with the antivirus. Antivirus programs can also affect the performance of certain interface elements, for example the quality slider. For Kaspersky, the steps to add the network address of PiKVM's website to the exclusion list is: `Protection -> Private browsing -> Categories and exclusions -> Exclusions`.

??? question "I can't click on anything when using the WebGUI on my phone"
    At this time, iOS has the buttons on the bottom if you have the correct resolution, sometimes you cannot see them due to the resolution.
    At this time, android is not supported, our suggestion is to use a VNC client.

??? question "I changed the Display Resolution to 720p but Windows still shows 1080p and the display looks blurry"
    This is mostly seen on Windows, open `Display Settings -> Advanced display settings -> Display adapter setting for Display 1 -> List all modes -> (Toggle between 720p30hz back to 50hz)`, this may need to be done if you need to change it back for 1080p.

## Hardware problems (Wi-Fi, ATX, etc)

??? question "I can't connect to Wi-Fi on a Raspberry Pi Zero W"
    * Some Zeros contain a defective Wi-Fi chip. You can either return the device to the store, or try the [software workaround](https://github.com/pikvm/pikvm/issues/137).

??? question "I can't connect to Wi-Fi at all!"

    * If your device is unable to connect to the Wi-Fi network that you have set up, check the 2.4 GHz Wi-Fi channel used by your Wi-Fi access point. 

    * If channels 12 to 14 are used (some countries have banned these channels) try to use a channel between 1 and 11.

??? question "LEDs/Switches do not work in ATX control"
    Double check your wiring. Make sure you placed the relays (G3VM-61A1) in the correct orientation. The relays for switches (Power, Reset) have a different orientation than the ones for LEDs.

??? question "My PiKVM keeps disconnecting from the Wi-Fi network"
    Try to edit `/etc/conf.d/wireless-regdom` and look for your region and uncomment it. For example: `WIRELESS_REGDOM="US"`.

??? question "PiKVM complains about low power warnings"
    * Are you using a "proper" power supply? Not one you hacked together?
    * Some USB power bricks advertise 5V 2.1A or higher, but can't deliver consistent 5V.  Best to use Raspberry Pi Foundation recommended power supplies.

??? question "PiKVM complains about a RTC low voltage detected, date/time is not reliable"
    * This is mearly a warning that can be ignored however, the following resolves the issue:
    * Leave plugged in for 24+ hours and or
    * Connect to the internet using the eth cable, the internal NTP service will set the time accordlingly
    * Force a time sync: `rw && hwclock --systohc"` or `"rw && hwclock -w"`
    * Set date and time manually can be found [here.](https://www.cyberciti.biz/faq/howto-set-date-time-from-linux-command-prompt/)

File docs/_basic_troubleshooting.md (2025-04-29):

---
search:
    exclude: true
---

* Ensure that you are using the right [OS image](flashing_os.md) for your platform
    by running the following command: `pacman -Q | grep kvmd-platform`.

* If you are not getting a display, run the two following commands:

    * `dmesg | egrep 'tc35|1-1.4|uvc'`
    * `systemctl status kvmd-tc358743`

    If you see a failed message on that output, be sure verify the orientation of the CSI cable or try reseating it.

    Note that this is not a hotplug device, and you must first turn off the power.

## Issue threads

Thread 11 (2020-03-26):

Why splitting the USB cable for RPI4? Works flawlessly without

JsBergbau, 2020-03-26:
> RPi4 only: since it uses one USB-C female connector to giving power and keyboard/mouse/drive emulation you also need to make a special cable to split DATA and POWER lines from USB-C. You can make it from two suitable connecting cables, or solder from scratch. Be sure to check the circuit diagram, otherwise you may damage your devices. Pinout specific used connectors you can easily find on request "USB pinout" in Google. Please note that if you will make a cable based on the two factory ones, the colors of the wires may not match those shown in the picture. Use a multimeter to make sure the connections are correct.

Why do you recommend splitting the cable? On a lot of PCs you can set that USB ports get always power even in OFF state. You can set that in BIOS. So I just want to understand the background of your advice.

With a good quality USB-C cable connected to a USB3.0 Port it provides even enough power that the PI doesn't print its undervolted message.
If power shouldn't be sufficient I would recomment using backpowering USB-A to USB-A cable. It is not possible to power it this way, but only to give it additional power. Even my RPI4 gets enough power via the PC USB3.0 connection it still draws 270 mA (=1,35W) when using backpower.

It works so smooth, just install, connect and you're ready. Splitting the cable is a effort you can easily avoid that way.

mdevaev, 2020-03-27:
The reason is that not all motherboards provide power in the off state. In addition, the USB current may not be sufficient for both stable RPI power supply and video capture operation. And in the latter case, you will not see any warnings from the kernel - just NO SIGNAL on the screen, this is a feature of the capture device.

If you want to bring power to the back panel via USB-A, then you may expect another surprise: some motherboards refuse to boot if the power to the USB is supplied from outside. For the same reason, you can't power the RPI via GPIO pins and just connect the USB to the computer - the current will flow towards it and you will get a problem when booting.

In short, our instructions describe how to make a device that is guaranteed to work in all cases. If the user wants to change something in the design, they must clearly understand what they are doing.

JsBergbau, 2020-03-27:
> If you want to bring power to the back panel via USB-A, then you may expect another surprise: some motherboards refuse to boot if the power to the USB is supplied from outside. For the same reason, you can't power the RPI via GPIO pins and just connect the USB to the computer - the current will flow towards it and you will get a problem when booting.

Thanks. I see you're a real expert. Didn't know that some mainboards won't boot then.

mdevaev, 2020-03-27:
Oh, come on. I'm just lucky to have strange problems :)

twisteroidambassador, 2021-01-27:
I think this may technically be a USB protocol violation. A self-powered USB device is not supposed to output on D+/D- unless a host is present, and on USB 2.0 the device can only detect the host by the 5V line being high. When the Pi is powered via the split cable, 5V is always high, therefore it may output on D+/D- even when the server is not turned on / not powering its USB port.

The above is assuming Pi 4 does not do the proper Type C host/device detection, and apparently it is the case: https://www.raspberrypi.org/forums/viewtopic.php?t=246348#p1504436

I'm sure the current splitter design works well in practice. Still, I wonder whether there's a more compliant solution.

mdevaev, 2021-01-27:
I know what you mean but there is no other solution at the moment as the pi power supply circuit is inseparable from the 5v detection. The USB controller is smart enough to handle this situation and it's better than backpowering.

outrullers, 2021-01-28:
> For the same reason, you can't power the RPI via GPIO pins and just connect the USB to the computer - the current will flow towards it and you will get a problem when booting.

That is the exact way I want to provide power to my Pi-KVM.
My setup:
1. power RPi-4 thru GPIO using standalone 5V PSU
2. connect RPi-4 USB port to server`s USB port

Can I add a diode to prevent current flow from RPi-4 USB towards the server`s USB port?

wzqvip, 2023-11-23:
That's fine. It's kinda optional. For some motherboard like "JINGYUE", if external power supply connected, the current will power the cooling fan, and for some reason it will prevent bootup. One lazy solution is not to connect the USB to the system first, use external 5V. After poweron, connect to PC and (may) remove the external power supply.

Closed 2020-03-27.

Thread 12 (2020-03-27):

Options for powersave

JsBergbau, 2020-03-27:
FIrst I want to thank you for your great project. You provide exactly the thing I was looking for. Thank you very much for all your effort you put into this project.

Powering Off HDMI saves 25 mA on the PI Zero W. Because powersupplies don't have 100 % efficiency you save 0.15-0.2 Watt. https://www.jeffgeerling.com/blogs/jeff-geerling/raspberry-pi-zero-conserve-energy It sounds not a lot, but in sum it is a lot. This amount also applies to the RPI4.
99 % of users won't need the HDMI output of the KVM Raspberry PI.
So we could savely turn off HDMI via `/opt/vc/bin/tvservice -o`
On Raspian I do this with a crontab "@reboot" line, however I'm not firm with ArchLinux. So it would be great if you add an option to disable HDMI.

mdevaev, 2020-03-27:
Okay, that makes sense. This option must be in config.mk what do you think?

JsBergbau, 2020-03-27:
Yeah, config.mk is the right place.

mdevaev, 2020-04-27:
Sorry for the delay.

I tried using this and found out that disabling HDMI can cause the RPi to hang on boot. I believe that you have this working in a particular case, but I would not like to add an option that can cause such problems.

mdevaev, 2020-04-27:
UPD: I did this: https://github.com/pikvm/packages/blob/master/packages/raspberrypi-hdmi/raspberrypi-hdmi-off.service

JsBergbau, 2020-04-28:
Hi. I have 4 PIs running 24/7 (except updates) and never hang on boot. What I do is to poweroff HDMI about 120-300 seconds after boot. This gives enough time to disable this feature if anything goes wrong at boot. Then you still see the output and could disable this feature before screen goes off.

E.g. thats my solution for disabling output

`@reboot sleep 120s && /opt/vc/bin/tvservice -o`

mdevaev, 2020-04-28:
I understand correctly that you also got a hang-up during boot, so you added a delay?

JsBergbau, 2020-04-28:
I've never tested the variant with the service. I had never a hang on boot because of disabling HDMI. It's just a safety measure. If any error occurs on boot, I can connect a monitor and see whats going on. All my raspberry PIs are headless, but if I ever had to configure them without network, I can attack a monitor and keyboard, then boot, disabling the delayed HDMI power off and then doing the necessary maintenance work.

mdevaev, 2020-04-28:
You can try the service. I made a package for this. Install `raspberrypi-hdmi` using pacman.

To enable HDMI:
`systemctl start raspberrypi-hdmi-off`; to disable stop the service. To disable during boot: `systemctl enable raspberrypi-hdmi-off`. But be prepared to hang :)

mdevaev, 2020-06-28:
Okay, I've just finished package for this feature. You can install it and enable like this:
```
pacman -S raspberrypi-hdmi
systemctl enable raspberrypi-hdmi-off.timer
```
**Don't** enable raspberrypi-hdmi-off.service, it may cause a hang on boot.

Since this option is potentially dangerous and may cause end-user questions, I would prefer not to enable it by default and not add the parameter to the build environment. I assume that for non-standard pikvm configurations, you can edit Dockerfile.part yourself to install the desired package.

JsBergbau, 2021-03-10:
Just testet. Works like a charm.

bunducafe, 2024-03-20:
Unfortunately the package cannot be installed with the latest version as it conflicts with praspberrypi-utils.

Is there a workaround? Or is just manually disabling doing the trick here?

mdevaev, 2024-03-20:
@bunducafe It made sense for Zero, which is no longer supported. Why do you need this now on modern boards? 0.1W is a drop in the ocean.

bunducafe, 2024-03-20:
Actually, I found that very handy when it comes to c-states on my server. The piKVM does prevent that. Once I unplug the HDMI cable c8 / c10 states are reached immediately.... But now I limit myself to just being able to ssh into the server and start / stop it. That's why I was asking.

The other remedy would be to just switch off the hdmi port completely.

mdevaev, 2024-03-20:
Sorry, I don't understand anything about states. Could you explaing in details?

mdevaev, 2024-03-20:
Oh, I get it. This package has nothing to do with HDMI communication with the server. This was necessary to turn off the HDMI **output** on the PiKVM itself.

bunducafe, 2024-03-20:
Yes, that's what I understood. I will then disable the tvservice on the pi temporarily.

mdevaev, 2024-03-20:
This is no longer supported after Zero is decommissioned.

Closed 2020-06-28.

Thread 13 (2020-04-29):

Optocouplers problem

mallendeo, 2020-04-29:
Hi, the [optocoupler](https://www.aliexpress.com/item/32964487766.html) I bought isn't working for some reason, so I'm using this relay instead.

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

The problem I have, is that the logic needs to be inverted for this relay to work, otherwise it will initialized with the "on" state and the PC won't be able to start. Inverting the logic at the relay as "normally open" will work only if the rpi is on.

For the moment I am manually editing the `set_output` and `write` methods on
`/usr/lib/python3.8/site-packages/kvmd/gpio.py` for this to work.

We could use an ENV variable, like `GPIO_INVERT_WRITE` and `GPIO_INVERT_READ`.

mdevaev, 2020-04-29:
> Inverting the logic at the relay as "normally open" will work only if the rpi is on.

I didn't understand the problem. You need to have the relay normally open by default to simulate pressing a button. I didn't understand the problem. You need to have the relay normally open by default to simulate pressing a button. Your relay has a normally open channel, why not use it?

mallendeo, 2020-04-29:
Sorry, my bad. It's actually normally open. When kvmd starts, the relay is closed without inverting the logic.

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

mdevaev, 2020-04-30:
What is the status of the relay before starting kvmd? Starting kvmd immediately changes the relay state from open to closed?

mallendeo, 2020-04-30:
Before starting kvmd it's off (open), and yes, it immediately changes to closed once the rpi has booted.
With the change above, it keeps its initial state after boot.

mdevaev, 2020-04-30:
Ah, I see. Your relay is controlled by zero level. This means that in any uncertain situation, it can close and unexpectedly turn off / turn on your server. I strongly do not recommend using this module. If you are determined to use this particular relay, I will add an option for you. But this is a big source of problems.

mallendeo, 2020-05-01:
I'm using it only because I didn't have any luck trying with an optocoupler or the 817 module (rpi gpio output is 3.3v and the 817 module requires 5v).

The relay has been working well for now, although thinking about it again, if this option does not makes any sense for the project or makes the code harder to reason about, I wouldn't worry (since this is a workaround for my use case). Thanks anyway for your time! :)

mdevaev, 2020-05-01:
Relay modules for 5V should work well. Give me a link to your module, and I will see what the problem is with my hardware engineer comrade. Also show which optocouplers you use.

mdevaev, 2020-05-01:
Adding this feature is not very difficult, but I would prefer to help you with your problem rather than treat its symptoms :)

mallendeo, 2020-05-01:
Thank you. I really appreciate this!

These are the ones I tried first
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

Then I bought this board
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

It lights up a little, but it doesn't have enough power to fully activate the sensor with 3.3v.

mdevaev, 2020-05-01:
Okay, here's the thing. Your optocouplers are based on transistors. The module you bought uses the same optocouplers that you tried initially. Polarity is also very important for them. Now you have these options:

1. You may buy optocouplers OMRON G3VM-61A1 as recommended by our instruction. This is not too expensive and we have selected these parts according to their characteristics so that they work well with RPi.
2. You can also try to modify the mechanical relay module so that it is controlled by a non-zero signal. This will require some soldering and will deprive the module of its factory beauty, but it should work.

In any case, I suggest you go to our discord, where we will help you faster: https://discord.gg/bpmXfz5

mallendeo, 2020-05-05:
Sorry for the late response.

> You may buy optocouplers OMRON G3VM-61A1 as recommended by our instruction.

Awesome!, because I ordered two of them a month ago, they seem stuck at customs though :p

Can I just replace the optocouplers with the ones in the 817 module and use the same circuit? (at least for the switches)

mdevaev, 2020-05-05:
No, I told you. They use the same optocouplers that you've tried before. Look at the markings on their body.

mallendeo, 2020-05-05:
No no, I mean these hahaha

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

mdevaev, 2020-05-05:
Sorry. Yes, it will work.

mdevaev, 2020-05-12:
I added information to the documentation that you need to use normal relays. I think this issue can be considered resolved.

mallendeo, 2020-05-21:
Just wanted to say thank you so much! The optocouplers finally arrived and it's working now, I couldn't make it to work with the existing PCB so I put a 330 Ohm resistor and it worked flawlessly.

mdevaev, 2020-05-21:
Cool!

myself248, 2020-08-24:
Not sure where else to put this, but in every motherboard I've looked at, there's no need for optocouplers. Barely even a transistor, but transistors are pennies. The Power and Reset signals are floating, and their respective pushbuttons just ground them. Since the Raspberry Pi shares a ground with the PC being controlled, these can be tied directly to GPIO. I demonstrate it here:

https://www.youtube.com/watch?v=eXzK3U6huwY

The gate charge of those FETs is only a few pF so a gate resistor isn't even needed. Doesn't get much simpler. (Arguably it does, if you had 5v-tolerant GPIO like certain knockoff boards...)

mdevaev, 2020-08-24:
@myself248 The relays are used for galvanic isolation in case the KVM and server are connected to different power outlets. And if you mix up the poles, you can ruin something on both the motherboard and the Pi. You can use this method if you have checked everything carefully, but remember that this way you lose additional protection from errors. And you can manage something non-standard, not quite ATX. In any case, not using the relay is a great way to see the magic smoke.

somuchtyler, 2020-10-22:
@mdevaev just to double check, i've been using optocouplers (PC817 are really common on aliexpress) for a project a while back and it seemed to work fine and what I do is wire them like the attached picture, just wanted to double check if there's any downsides to using this setup...? the reason I do it this way is so I don't need to check for polarity at all
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

mdevaev, 2020-10-23:
@somuchtyler this circuit should work fine, but you need to hang a separate resistor on each anode to limit the current. The value of the resistor must be calculated based on the characteristics of the optocoupler.

somuchtyler, 2020-10-23:
@mdevaev good catch, I did forgot to put in resistors before each of the anodes in my picture. If doing 3.3V logic with a typical forward voltage of 1.2V and a max current of 50mA. If wanting to stay under that at say at 20mA, it would be 105ohms right?
(3.3-1.2)/0.020=105ohms

mdevaev, 2020-10-23:
@somuchtyler yep. 120 ohm is standard value. You can usse it I guess.

atesin, 2020-11-14:
hi ...  sorry i didnt read completely, but working with arduino i also had some troubles with these chinese relays, too bad they are poorly documented anyway

searching a lot i discover the *correct* way to use it ....  the mechanical module (the blue little box) is a coil relay with 12v sensitivity, so to get work with 5 or less volt were mede with optocopulers in the middle, so you have to feed the optocopulers with a little voltage (5v-2.5v?) and the coil relays with 9v-12v isolated

but the relays module comes by default with these 2 circuits shorted with a jumper, thats because 5v inputs are not enough to trigger the relays (or unpredictable)...  so you have to remove the jumper and feed with 12v apart to get the module work properly
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
DocJr90, 2024-01-12:
@mdevaev It appears the G3VM-61A1 has been EOL'ed. Any suggestions on a specific replacement? I'm currently searching through Omron's products but the naming scheme isn't particularly obvious and/or helpful to a novice.

DocJr90, 2024-01-12:
@mdevaev Finally found it after manually navigating Omron's website and locating the datasheet instead of looking for discontinuation notices. Mouser also wasn't immediately helpful due to the generic label ("Solid State Relays - PCB Mount MOS-FET RELAY"). The recommended part number that appears equivalent for new designs is:  G3VM-61AY1

mdevaev, 2024-01-12:
Added to the list, thank you

HotelMoted, 2024-01-13:
I've been using 2x PC817 per power switch for years now and never had a problem across dozens servers.

jiaxinonly, 2024-09-20:
> Ah, I see. Your relay is controlled by zero level. This means that in any uncertain situation, it can close and unexpectedly turn off / turn on your server. I strongly do not recommend using this module. If you are determined to use this particular relay, I will add an option for you. But this is a big source of problems.

Sorry, I do need an option to inverted power_switch_pin and reset_switch_pin, I need to control atx directly using gpio without adding any other relays. I wanted to do it despite the risks I had seen many times in the issue. The user can be strongly warned in the document, but the user can choose whether to use it or not

mdevaev, 2024-09-20:
I don't want to add solutions that allow the user to shoot himself in the foot. In my experience, such options always raise too many support questions and related problems.

jiaxinonly, 2024-09-20:
Well, you're right. It does cause unnecessary trouble :joy:

jiaxinonly, 2024-09-20:
If you need to inverted power_switch_pin and reset_switch_pin, you can do so, but make sure you are aware of the risks before doing so. (System demonstration based on pikvm v4 plus)
:warning: It is strongly not recommended that you do this！:warning:
1. ssh connects to pikvm
2. change the system to rw
    ```shell
    rw
    ```
3. edit /usr/lib/python3.12/site-packages/kvmd/plugins/atx/gpio.py
    ```shell
    vim /usr/lib/python3.12/site-packages/kvmd/plugins/atx/gpio.py
    ```
3. change the default level of power_switch_pin and reset_switch_pin to high
    ```python
    def sysprep(self) -> None:
        assert self.__line_req is None
        self.__line_req = gpiod.request_lines(
            self.__device_path,
            consumer="kvmd::atx",
            config={
                (self.__power_switch_pin, self.__reset_switch_pin): gpiod.LineSettings(
                    direction=gpiod.line.Direction.OUTPUT,
                    output_value=gpiod.line.Value(True),  # Set to high
                ),
            },
        )
    ```
4. modify the click logic. After clicking, the output is low and then restored to high
    ```python
    async def __inner_click(self, name: str, pin: int, delay: float) -> None:
        assert self.__line_req
        try:
            self.__line_req.set_value(pin, gpiod.line.Value(False))  # Set to low when you click
            await asyncio.sleep(delay)
        finally:
            self.__line_req.set_value(pin, gpiod.line.Value(True))  # Restore to high level
            await asyncio.sleep(1)
        get_logger(0).info("Clicked ATX button %r", name)
    ```
5. restore the system to read-only
    ```shell
    ro
    ```
6. restart the kvmd service
    ```shell
    systemctl restart kvmd
    ```

itiberiu, 2024-09-20:
ty very much! now my relay is premanent off, except when i use it!

itiberiu, 2025-04-19:
I just want to add a change. In the meantime, the path to the file has changed.

vim /usr/lib/python3.13/site-packages/kvmd/plugins/atx/gpio.py

Closed 2020-05-12.

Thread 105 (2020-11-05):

Shopping list for wired ethernet pikvm?

marmalodak, 2020-11-05:
Being unfamiliar with the Raspberry Pi ecosystem, I need a little help with putting together a complete build.

My preferences:

1. Wired ethernet
2. Display that will show me the IP address of the PIKVM
3. Plugs and power supplies so that I can plug it into the wall permanently
4. Case that can contain everything

This is what I have so far:

[Raspberry Pi 4 Model b](https://www.raspberrypi.org/products/raspberry-pi-4-model-b/)
[Raspberry Pi 4 case](https://www.raspberrypi.org/products/raspberry-pi-4-case/)
[Lusya Standard HDMI to CSI-2 Adapter Board](https://www.aliexpress.com/item/4000102166176.html)
[240×320, General 2inch IPS LCD Display Module](https://www.pishop.us/product/240-320-general-2inch-ips-lcd-display-module/)

Questions:

1. Can an ordinary macbook USB-C wall plug power the whole PIKVM device?
2. Are there any parts I'm missing or would be a better replacement?
3. If I don't need a touch screen, which display might you recommend?
4. Is this [Raspberry Pi HDMI to CSI-2 Adapter Board with 15 pin FFC cable](https://geekworm.com/products/raspberry-pi-hdmi-to-csi-2-adapter-board-with-15-pin-ffc-cable) an appropriate capture device?
5. Is this [HDMI Adapter Board HDMI to CSI-2 TC358743XBG for Raspberry Pi 4B 3B 3B+ Zero](https://www.amazon.com/Adapter-Board-CSI-2-TC358743XBG-Raspberry/dp/B08D3H6NR4) an appropriate capture device? Why is it so much more expensive?

mdevaev, 2020-11-05:
> Can an ordinary macbook USB-C wall plug power the whole PIKVM device?
Perhaps no baceuse the Pi have a broken power delivery. I recommend the official RPi power supply.

> Are there any parts I'm missing or would be a better replacement?
USB-C wires and the power splitter.

> appropriate capture device?
Yep

> Why is it so much more expensive?
Becaus it's Zero compatible I guess.

marmalodak, 2020-11-06:
Thanks for the feedback.

Is the power splitter needed because the capture device and the screen each need their own power supplies? I don't see a product on the raspberry pi site that is an obvious power splitter.

Is [this](https://www.amazon.com/Headphone-Charger-Splitter-Charging-Compatible/dp/B087N52WD2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) an appropriate splitter?

If I get [this power supply](https://www.canakit.com/official-raspberry-pi-4-power-supply.html?cid=usd&src=raspberrypi), can I power both the RPi and the capture device with it?

I gather that I also need micro SD card. [Like this one maybe?](https://www.amazon.com/dp/B06XWN9Q99/ref=cm_sw_em_r_mt_dp_x0kPFb0N2D2EF)

mdevaev, 2020-11-06:
The splitter is required so that your server does not try to power the raspberry and power from the raspberry does not go back to the server.

> Is this an appropriate splitter?

No, you need a [separate power circuit](https://github.com/pikvm/pikvm/blob/master/img/v2_splitter.png). Like [this](https://www.tindie.com/products/8086net/usb-cpwr-splitter/)

> If I get this power supply, can I power both the RPi and the capture device with it?

The capture device does not need its own power supply. This power supply is a great choice.

> I gather that I also need micro SD card. Like this one maybe?

mdevaev, 2020-11-12:
I'm closing this issue, since apparently the problem is solved. If you encounter any difficulties, you can get support from discord :smirk_cat:

Closed 2020-11-12.

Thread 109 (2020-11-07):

Failed to start Pi-KVM - EDID loader for TC358743

ndastur, 2020-11-07:
**Describe the bug**
I can open the KVM but I don't get a HMDI stream
The error message on console says to look at the status. That is pasted below.

```shell
# systemctl status kvmd-tc358743.service
* kvmd-tc358743.service - Pi-KVM - EDID loader for TC358743
     Loaded: loaded (/usr/lib/systemd/system/kvmd-tc358743.service; enabled; vendor preset: disabled)
     Active: failed (Result: exit-code) since Sat 2020-11-07 15:53:17 GMT; 4min 19s ago
    Process: 367 ExecStart=/usr/bin/v4l2-ctl --device=/dev/kvmd-video --set-edid=file=/etc/kvmd/tc358743-edid.hex --fix-edid-checksums (code=exited, status=1/FAILURE)
   Main PID: 367 (code=exited, status=1/FAILURE)

Nov 07 15:53:16 pikvm systemd[1]: Starting Pi-KVM - EDID loader for TC358743...
Nov 07 15:53:16 pikvm v4l2-ctl[367]: Cannot open device /dev/kvmd-video, exiting.
Nov 07 15:53:17 pikvm systemd[1]: kvmd-tc358743.service: Main process exited, code=exited, status=1/FAILURE
Nov 07 15:53:17 pikvm systemd[1]: kvmd-tc358743.service: Failed with result 'exit-code'.
Nov 07 15:53:17 pikvm systemd[1]: Failed to start Pi-KVM - EDID loader for TC358743.
```

**To Reproduce**
Steps to reproduce the behavior, like:
1. Burn brand new image
2. Connect to HMDI source
3. Turn on both
4. Goto to https server and click KVM
5. No stream

**Expected behavior**
A stream

**Screenshots**
None

**Desktop (please complete the following information):**
 - OS: Windows 10 OS as source. Pi Zero W
 - Browser Safari
 - Version From Git. Built own image as per docs

**Pi config.mk for image build**

```
cat config.mk
# rpi3 for Raspberry Pi 3; rpi2 for the version 2, zerow for ZeroW
BOARD = zerow

# Hardware configuration
PLATFORM = v2-hdmi

# Target hostname
HOSTNAME = pikvm

# ru_RU, etc. UTF-8 only
LOCALE = en_GB

# See /usr/share/zoneinfo
TIMEZONE = Europe/London

# For SSH root user
ROOT_PASSWD = root

# Web UI credentials: user=admin, password=<this>
WEBUI_ADMIN_PASSWD = xxxx

# IPMI credentials: user=admin, password=<this>
IPMI_ADMIN_PASSWD = xxxx

# SD card device
CARD = /dev/mmcblk0
```

**Pi-KVM info:**
  - Raspberry Pi board version: Pi Zero W
  - Pi-KVM platform v2-hdmi
  - Video capture type HDMI board https://www.aliexpress.com/item/4000152180240.html?spm=a2g0s.9042311.0.0.66ca4c4dvnIGZi. Standard board with a Pi to Pi zero CSI connector
  - KVMD version:

```
kvmd 2.3-1
kvmd-platform-v2-hdmi-zerow 2.3-1
kvmd-webterm 0.35-1
```

  - uStreamer version: ```ustreamer 2.1-1```
  - Linux kernel: ```Linux pikvm 5.4.74-1-ARCH #1 SMP PREEMPT Wed Nov 4 16:52:07 UTC 2020 armv6l GNU/Linux```

mdevaev, 2020-11-07:
Try dmesg|grep tc3

Сб, 7 нояб. 2020 г. в 19:07, Neville Dastur <notifications@github.com>:

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

ndastur, 2020-11-08:
```
# dmesg|grep tc3
[   25.911242] tc358743 10-000f: i2c_rd: reading register 0x0 from 0xf failed
[   25.911254] tc358743 10-000f: not a TC358743 on address 0x1e
```

mdevaev, 2020-11-08:
You probably connected the cable incorrectly. Look carefully at the location of the contacts, make sure that you have inserted the cable all the way and snapped the connector's latch.

ndastur, 2020-11-08:
How silly. Thank you. That's exactly right.

For anyone else. The connectors go into both devices facing downwards.

Next step is adding a pzem-004t power monitor.

mdevaev, 2020-11-08:
Great)

Priyadharshini494, 2024-02-29:
I'M facing the same issue although i have connected the cables properly

allquixotic, 2024-03-31:
I'm facing the same issue on a stock PiKVM v4 Plus. I haven't opened or touched anything internal to the device - I've only ever used it from the "outside" (plugging things into the ports) and it still fails with this exact dmesg error. Any clues?

Closed 2020-11-08.

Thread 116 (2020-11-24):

I'm using H2C-RPI-B01 device as HDMI-CSI bridge, but PIKVM doesn't seem to be able to communicate with it.

hradec, 2020-11-24:
**Describe the bug**
I'm using H2C-RPI-B01 device as HDMI-CSI bridge with a pizerow, but PIKVM doesn't seem to be able to communicate with it.
the device is this one: https://www.aliexpress.com/item/4000152180240.html?spm=a2g0s.9042311.0.0.27424c4d2kwBtm

I get these on dmesg as well:
```
[   24.160100] tc358743 10-000f: i2c_rd: reading register 0x0 from 0xf failed
[   24.285521] tc358743 10-000f: not a TC358743 on address 0x1e
```

I've tried `i2cdetect -y 1` and got the error:
```
Error: Could not open file `/dev/i2c-1' or `/dev/i2c/1': No such file or directory
```

maybe the module for i2c is not loaded for some reason?

I've created the image successfully using arch on kernel 5.9.9, using `make os`.

**Pi-KVM info:**
  - Raspberry Pi board version: pizerow
  - Pi-KVM platform: v2-hdmi
  - Video capture type: CSI bridge - H2C-RPI-B01 - https://www.aliexpress.com/item/4000152180240.html?spm=a2g0s.9042311.0.0.27424c4d2kwBtm
  - KVMD version: kvmd 2.4-1 / kvmd-platform-v2-hdmi-zerow 2.4-1 / kvmd-webterm 0.35-1
  - uStreamer version: ustreamer 2.1-1
  - Linux kernel: Linux pikvm 5.4.79-1-ARCH #1 SMP PREEMPT Mon Nov 23 22:17:50 UTC 2020 armv6l GNU/Linux

mdevaev, 2020-11-24:
Make sure that you have inserted the correct side of the cable into both connectors. Attach a photo of both ends of the cable.

hradec, 2020-12-03:
I tried booth sides of the cable, and also switching the ends between the HDMI and PiZeroW, and still get the same error.
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

But I think I've figured it out. I'm using one of those "usb dongle" boards for the PiZeroW:
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
so I can plug it directly into a usb port on the computer I wanna to control, and plug a short HDMI on the other end. It's a really neat solution!

Turns out the power that comes from the USB2 on the computer is not enough to power the CSI-HDMI bridge board. That's why it was failing.

As soon as I plugged a 2amp power supply directly in the usb micro connector of the PiZeroW, it started up correctly:
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

So, a computer USB port powers up the PiZeroW (with the wifi) without issues, but it doesn't have enough power to power up the CSI-HDMI bridge I'm using.

mdevaev, 2020-12-03:
Lack of power can lead to such problems, which is why I show in the interface and README that a good power supply is required.

I guess this problem is solved.

mdevaev, 2020-12-04:
> Maybe another one would work? someone?

I don't think so. All bridges consume the same current.

Closed 2020-12-25.

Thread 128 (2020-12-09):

KVM 4 port switches supported list add to docs

db260179, 2020-12-09:
**Is your feature request related to a problem? Please describe.**
Keep a documented list of 4 port KVM hdmi switches that work with this project [...]

**Describe the solution you'd like**
Maintain a list of these KVM switches so customers know what they can use.

https://a.aliexpress.com/_BSpS8t

This 4 port KVM switch is a good price and has adaptive EDID on the hdmi port, which means you can plug/unplug and it will show up again with know issues. Also the keyboard shortcuts work from the web interface - CTRL + CTRL then port number (1,2,3,4)

My setup is a Raspberry pi zero W and is connected via the OTG and not using the arduino.

Be good to keep a list of these for future use and customers using your project.

mdevaev, 2020-12-10:
Good idea. Does this switch require an Arduino HID or works with OTG?

https://github.com/pikvm/pikvm/blob/master/pages/multiport.md#list-of-tested-kvms

db260179, 2020-12-10:
> Good idea. Does this switch require an Arduino HID or works with OTG?
>
> https://github.com/pikvm/pikvm/blob/master/pages/multiport.md#list-of-tested-kvms

So i've updated my main quote above.

Im using this on a Raspberry pi zero W via the OTG.

This particular kvm switch has usb hub ports as well, so you can plug in usb keys etc.

mdevaev, 2020-12-17:
Added

hberntsen, 2021-01-29:
When I connect my Auvidea B101 to the output of this KVM switch and apply power, the raspberry does not boot (green led of the Auvidea also does not light up). At the moment I unplug the HDMI cable, the raspberry starts and the auvidea led turns on. I can then plug it back in again and everything is fine. So as long as there is no power outage it works fine :)

BernhardLinz, 2021-01-29:
> When I connect my Auvidea B101 to the output of this KVM switch and apply power, the raspberry does not boot (green led of the Auvidea also does not light up). At the moment I unplug the HDMI cable, the raspberry starts and the auvidea led turns on. I can then plug it back in again and everything is fine. So as long as there is no power outage it works fine :)
>
> (I have the AM-KVM401K-V2.1 2020-09-19)

Same Problem her. Need to unplug HDMI or to turn of the KVM switch (which have a little Power Switch at the front). The green LEDs of the KVM switch will still shine but the raspberry start to boot

joBr99, 2021-01-29:
Same problem here, but with a different kvm switch

hberntsen, 2021-01-29:
My AM-KVM401K-V2.1  HDMI switch has an AX68002. I found the datasheet on the ASIX website and found the reset pin for the chip. I tried keeping the CPU in reset but that did not help :(. I did find a UART port with a baud rate of 19200. It prints
```
[Virtual HUB] VID = 0b95, PID = 6804
 System Informaiton:
  (v) USB Storage Device:Yes,PageSize=512
HDMI_CH4
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
HDMI_CH3
HDMI_CH2
> DC_Port:0, Reset
> DC_Port:0, Reset
> DC_Port:0, Suspend
HDMI_CH1
```
It prints the HDMI output line when a button on the front panel is pressed. It also prints some info on the attached USB port. I couldn't find the protocol to send commands to the device.

Unfortunately they removed the text on the chips so I don't know which HDMI switch chips they used. Looks like there are 2 3:1 chips on the board.

ingo916, 2021-04-14:
I have the AIMOS 4 port hdmi switch and seems to be working great, how do I add the UI elements to control the KVM switch? pressing ctrl ctrl then the port number will change the display? how do i replicate this in the UI?

strausmann, 2021-04-28:
I see in the Discord Chat that some people would like to buy this HDMI Switch from Tendak:

https://www.amazon.com/Tendak-Keyboard-Printer-Switcher-Include/dp/B08B7XXBGZ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

The Switch has an external Controller connected via Micro USB to the HDMI Switch. I can change the HDMI Source with the four buttons on this controller.

How can I connect the Control Port now with my Raspberry Pi 4?

arch1mede, 2021-04-28:
@strausmann from my search, it was 2 others that were asking about it. That specific model needs to be controlled by gpio and requires much more work than an average person can do, I would recommend finding a kvm that supports hotkey switching and a usb printer port for the OTG. Physical kb switching is still needed though.

@ingo916 At this time its not supported, physical kb is still needed.

mdevaev, 2021-07-04:
I suppose this issue can be closed since we have a list of supported switches. Problems with them and other models should be solved in Discord or other dedicated issues among users who have them.

rkkotnik, 2022-11-23:
I have PiKVm with raspberry 4 and i Love it! I have a plan to add another server to my homelab and i would like to also manage that over PIKVM.

I found some KVM switch:
https://www.aliexpress.com/item/1005003157653420.html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

But IDK if that will work. I know you have a list of devices that work, but many are for too many devices and are expensive. + I saw something about back power, which I don't quite understand, what is up with that?

arch1mede, 2022-11-24:
Hi, yes as was explained on Discord, we have not tested this, its likely it will not work and have the same or more limitations as the 4 port. If you are planning on getting this, please let us know if it works or not.

Closed 2021-07-04.

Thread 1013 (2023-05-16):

TESMART 16 Port KVM GPIO offline

joelidrive, 2023-05-16:
**Describe the bug**
After about 1-2 hours the GPIO buttons to switch inputs on the PiKVM are greyed out and do not work (does not switch input when pressed). This is on a 16-port TESMART switch. Model: HKS1601A10. Switch is still online and able to switch inputs through Network control on the TESMART Switch Controller. Only action that fixes the issue is by powering the TESMART KVM switch on and off again. After a power cycle the GPIO button LEDs become green and available again. Restarting kvmd service does not fix the issue either.

**To Reproduce**
Steps to reproduce the behavior, like:
1. After about 1-2 hours from a power cycle of the TESMART KVM switch, the GPIO buttons that were made available through the overide.yaml file are greyed out and do not function anymore.
2. Updating and rebooting PiKVM still has the GPIO buttons greyed out. Restarting kvmd service still has buttons greyed out.
3. Issue repeats after the TESMART KVM switch power cycles.

**Expected behavior**
GPIO buttons for switching inputs does not grey out after a couple of hours and is able to switch inputs. Stays consistently green and available unless switch is powered off or PiKVM is updated.

**Screenshots**
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

**Desktop (please complete the following information):**
 - OS: Windows 11 Build 22621
 - Browser Firefox
 - Version 113.0.1
 - No VNC client used.

**PiKVM info:**
  - Raspberry Pi 4
  - PiKVM platform v3 HDMI
  - Video capture type CSI Bridge
  - KVMD version: 3.217-1
  - uStreamer version: 5.38-3
  - Linux kernel: 5.15.68-3-rpi-ARCH

**Additional context**
Unsure if this is an issue with the TESMART switch, PiKVM, or local network environment. Don't really know where to go to help solve this issue, but here. If specific logs are required let me know and I can provide.

mdevaev, 2023-06-04:
Please attach the full output of `journalctl -u kvmd`

joelidrive, 2023-06-05:
Was able to solve the issue.

It was a local environment issue.

A random PC on my network was always attempting to grab the same static IP set for the switch. Changed IP for the Tesmart switch.

I longer have this issue. Thanks for reply :)

mdevaev, 2023-06-05:
:ok_hand:

timblaktu, 2023-08-20:
@joelidrive I wonder if you would be willing to share with me your use case and some detail and feedback about your design and control setup?

I bought one of these tesmart hdmi kvm switches and i'm looking for existing code/projects to use and contribute to before rolling my own.

I've got the 16 port version, connected to some dell poweredge servers and optiplex sff workstations and rpis and other small devices in my basement homelab. I use the switch in the lab space, but would like to automate control from a pc, and also eventually connect its output to  something like a pikvm to allow remote access.

joelidrive, 2023-08-21:
@timblaktu

Sure! My use case is very unorthodox. It's used in a work environment to make my workflow a lot simpler.

I use this to not go back and forth from my desk (physically speaking) when I install Vanilla Debian on multiple servers. It's really helpful when using ISO images as well. Being able to mount and unmount without physically touching servers saves even more time.

While there are more automated ways to do this, we have a specific way of doing things which makes the automated way of deployment more difficult. To avoid issues I use a PiKVM connected to the TESMART 16 Port KVM while driving the logic inputs via the GPIO pins as you mentioned :)

It works very well for what I need it to do and the bonus is that I can do that all from the comfort of my actual workstation versus the space used to setup servers.

I have not played around with remote access straight to the PiKVM using Tailscale since I already have remote access to my workstation setup. Might be something I do in the future!

Closed 2023-06-05.

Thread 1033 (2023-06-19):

Arudino HID: Program error "obsolete use of -b <clock> option for bit clock; use -B <clock>"

jcormier, 2023-06-19:
**Describe the bug**
Programming an Arduino SparkFun Pro Micro 3v3 following the instructions:
https://docs.pikvm.org/arduino_hid/#ps2-keyboard
https://docs.pikvm.org/flashing_hid/#spi-firmware

I've attached the SS to the RX LED as mentioned in the note. As well as connecting MOSI/MISO/SCLK to pins 16/14/15. As well as the reset with a transistor.
https://images.theengineeringprojects.com/image/webp/2020/12/Introduction-to-Arduino-Pro-Micro-2.png.webp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

I've updated the platformio file "board = sparkfun_promicro8".

Is the "obsolete use of -b <clock>" warning relevant?  The 3.3V part runs slower than the normal Micro, so perhaps the spi clock is set too high?
Where would I change this in the hid project?

```
platformio run --environment 'spi' --project-conf 'platformio-avr.ini' --target upload
Processing spi (platform: atmelavr; board: sparkfun_promicro8; framework: arduino)
-------------------------------------------------------------------------------------------------------------------------------------------------------------------------------------------------------------------
Verbose mode can be enabled via `-v, --verbose` option
CONFIGURATION: https://docs.platformio.org/page/boards/atmelavr/sparkfun_promicro8.html
PLATFORM: Atmel AVR (4.2.0) > SparkFun Pro Micro 3.3V/8MHz
HARDWARE: ATMEGA32U4 8MHz, 2.50KB RAM, 28KB Flash
DEBUG: Current (simavr) External (simavr)
PACKAGES:
 - framework-arduino-avr @ 5.1.0
 - tool-avrdude @ 1.70100.0 (7.1.0)
 - toolchain-atmelavr @ 1.70300.191015 (7.3.0)
LDF: Library Dependency Finder -> https://bit.ly/configure-pio-ldf
LDF Modes: Finder ~ chain, Compatibility ~ soft
Found 11 compatible libraries
Scanning dependencies...
Dependency Graph
|-- HID-Project @ 2.8.2+sha.afae388
|   |-- HID @ 1.0
|-- ps2dev @ 0.0.3+sha.a043002
|-- digitalWriteFast @ 1.0.0
|-- HID @ 1.0
|-- drivers-avr
|   |-- drivers
|   |   |-- digitalWriteFast @ 1.0.0
|   |-- ps2dev @ 0.0.3+sha.a043002
|   |-- HID-Project @ 2.8.2+sha.afae388
|   |   |-- HID @ 1.0
|-- drivers
|   |-- digitalWriteFast @ 1.0.0
Building in release mode
Checking size .pio/build/spi/firmware.elf
Advanced Memory Usage is available via "PlatformIO Home > Project Inspect"
RAM:   [==        ]  15.6% (used 399 bytes from 2560 bytes)
Flash: [====      ]  36.5% (used 10464 bytes from 28672 bytes)
Configuring upload protocol...
AVAILABLE: custom
CURRENT: upload_protocol = custom
Uploading .pio/build/spi/firmware.hex
avrdude warning: obsolete use of -b <clock> option for bit clock; use -B <clock>

avrdude error: AVR device not responding
avrdude error: initialization failed, rc=-2
        the programmer ISP clock is too fast for the target
        - use -B to set lower ISP clock frequency, e.g. -B 125kHz
        - use -F to override this check

avrdude done.  Thank you.

*** [upload] Error 1
```

mdevaev, 2023-06-21:
Hello. You can find the config in `avrdude-rpi.conf`:
```
programmer
id = "rpi";
    desc = "RPi SPI programmer";
    type = "linuxspi";
    reset = 25;
    baudrate = 400000;
;
```
You can play with `baudrate` option I think. Try to reduce it by half, but I am not sure which configuration will be correct since I have not encountered this.

jcormier, 2023-06-21:
Thanks.  I get the same error when changing the baudrate.  Is there a way to update the code so it uses the correct -B argument?

mdevaev, 2023-06-21:
> Is there a way to update the code so it uses the correct -B argument?

This is a warning, not a critical error. The option is still working.

> Additionally is there a way to program the device over USB instead of over SPI.

Edit `platformio-avr.ini` and replace `upload_*` options in `_common_spi` to single `upload_port = /dev/ttyACM0`.

PS: I don't know how to make it in arduino ide, I'm not using it.

mdevaev, 2023-06-29:
Hi. How it's going?

jcormier, 2023-06-29:
Hi, yeah sorry was on vacation and am trying to catch up on other projects.  I hope to get back to this soon. Thanks for checking in.

mdevaev, 2023-08-08:
Sup?

jcormier, 2023-08-09:
My TODO list just keeps getting longer xD.  Its still setup on my desk, I just need a few hours of breathing room to get back to it...

mdevaev, 2023-08-09:
What do you think about making the HID on Raspberry Pico?

mdevaev, 2023-10-07:
Ping

mdevaev, 2023-10-08:
So, I'm closing it. Please contact support in discord if you want to continue this.

jcormier, 2023-10-09:
> So, I'm closing it. Please contact support in discord if you want to continue this.

Thanks, that fair.

> What do you think about making the HID on Raspberry Pico?
I do have some Picos at home.  Did someone get one of those working as a HID?

mdevaev, 2023-10-09:
Ofc. This solution works, but has not yet been officially released. Are you using Raspberry 3?

jcormier, 2023-10-09:
I'm not sure which PI this is.  The case doesn't mention a version and the cape is blocking access to the PI.  The cape is labeled "PI-KVM Shield v3.3"

mdevaev, 2023-10-09:
Take a photo

jcormier, 2023-10-18:
I got it working with the raspberry pico w. Posted in the discord. Yay

mdevaev, 2023-10-19:
Bueno :)

Closed 2023-10-08.

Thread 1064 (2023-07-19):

ATX Control is not working if made using relay

justicecurcian, 2023-07-19:
**Describe the bug**
I am using v2 made with RPI 4. I DIYed an ATX Control using cheap relay that is being contolled by 3.3V ( https://aliexpress.ru/item/1005001994042589.html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 ), but it's not working. I manually triggered relay using 3.3V from RPI and it closed, but when I click power/reset in the web control panel the relay won't close. I am using correct pins (23 for power and 27 for reset), I tried creating my own button using gpio plugin, but had no luck setting it up correctly. I am using only two relays for buttons and nothing for power light, so this might be an issue, but I found nothing about mandatory connection of power led in the docs.

**To Reproduce**
Click power/reset in ATX menu

**Expected behavior**
Relay closed and PC power/reset button "clicked"

**Screenshots**
If applicable, add screenshots to help explain your problem.

**Desktop (please complete the following information):**
 - OS: Windows / Mac OS
 - Browser: Chrome
 - Version: No idea how to find it

**PiKVM info:**
  - Raspberry Pi board version: RPi 4
  - PiKVM platform: v2-hdmi
  - Video capture type: CSI bridge
  - KVMD version: 3.173
  - uStreamer version: 5.31-1
  - Linux kernel: Linux pikvm 5.15.68-3-rpi-ARCH #1 SMP Mon Oct 31 20:56:54 MSK 2022 armv7l GNU/Linux

mdevaev, 2023-07-20:
What do you mean, did you perform the direct connection of relay coil to gpio? Without any transistors?

justicecurcian, 2023-07-20:
>What do you mean
If something particular from my message is hard to understand, please quote it and I will try to rephrase it.

>Did you perform the direct connection of relay coil to gpio? Without any transistors?
Yes, direct connection without any transistors, since RPI 4 gpio is 3.3V it should be able to control relay directly. 3.3V power pin from RPI in fact can close relay easily. If I connect LED to pins 23 and GROUND it won't highlight too, so I think it's either a software problem or I am wiring it wrong. When I click on "Click Power" in ATX control is it supposed to emit 3.3V or ground pin 23?

mdevaev, 2023-07-20:
> Yes, direct connection without any transistors, since RPI 4 gpio is 3.3V it should be able to control relay directly.

Don't ever do that! You can burn your Raspberry. The coil consumes a lot of power for operation, and when de-energized generates a reverse polarity current. I recommend you to buy a relay module that has a separate power input and a control wire. But it is better if you follow our scheme.

justicecurcian, 2023-07-20:
>You can burn your Raspberry.

Oh, that's not good. I will use a separate module later, thank you.  Maybe it's good it didn't work, since I could kill my kvm.
But the problem is still presented, LED is not highlighting, 23 pin is not getting power. I didn't follow docs scheme because listed parts are unavailable here.

justicecurcian, 2023-07-20:
On second thought, maybe relay did kill the pin, so this is why led is not highlighing...

mdevaev, 2023-07-20:
Yes, maybe that's the reason.

mdevaev, 2023-07-20:
You can use other pins, but before that, find a good relay module.

justicecurcian, 2023-07-20:
How do I change pins? I thought they are hardcoded.

justicecurcian, 2023-07-20:
I flashed raspbian and pulled up pin 23 using raspi-gpio and it flashed LED, I've got back to pikvm and ATX control works now (without relay, dummy led). Really weird, sorry for useless issue and big thanks for telling me about relays, you saved my PI!

mdevaev, 2023-07-21:
No problem :)

Closed 2023-07-20.

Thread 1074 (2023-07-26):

usb emulation error with y splitter

manasmgkar, 2023-07-26:
i have a weird error,whenever i connect directly my pikvm to the system no y splitter it works fine,just powered by it(my mobo supports always power on states and enough current to power dacs etc(gaming board)) it works fine but whenever i use a usb data splitter and external power this is the error i get or i get no usb emulation if the error does not show

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

my data splitter looks like this basically,i am using a cheap usb 4 way splitter no chips just all ports connected physically/dumb to each other,cant get the power splitter due to the Chinese shipping ban here. The splitter below i have cut the red power line from the microusb to usb a cable that way only d+,d- and ground are connected

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

I tried connecting usb-a to usb c and then usb-a to c to my kindle via the 4 way usb pictured above and it works fine so does my phone,tablet etc so its not a problem in the 4 way usb board since its nothing but dumb connections that go from each port to each port.

I think this is a problem with how i am splitting the data only cable. i at first thought since data cables are not split at the power supply side this may be a problem but even using a data blocker on the power supply side does not solve the non recognition error. now technically it looks exactly like the diagram from the read me with only data and ground cables connected to the c port.

i tried connecting to two different machines and both machines the device isnt recognized. only works if the device is powered/usb c of pi directly connected to the machine.

this seems relevant https://urukrama.wordpress.com/2009/01/27/usb-drive-not-recognised-error-71/ maybe this can fix it ?

One weird thing i noticed is if i do have have the data cable plugged in to my 4way splitter the device works fine but if i do have the data cable connected just to the 4way splitter not even the target sytem then i get this error on all platforms,windows,linux,
connected to windows i get this error

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

seems like a issues on the data cable side,maybe the ground is shorted or something,if i plug in the pi to the power supply and the data cable to the target system the device is not even detected(no faliure nothing just no detection at all).

manasmgkar, 2023-07-27:
Turns out it was the 4 way splitter
 it is wired across. so usb female goes to usb male and usb c goes to usb micro only the power and ground are common

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

Closed 2023-07-27.

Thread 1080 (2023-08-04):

Can't move web windows on non-mobile touch screen

spoelstraethan, 2023-08-04:
**Describe the bug**
PiKVM virtual keyboard doesn't allow repositioning via touch, requires mouse (or possibly stylus) input to get 4 way arrow to drag via title bar.

**To Reproduce**
Steps to reproduce the behavior, like:
1. Open PiKVM's KVM interface and view the connected device
2. Click on the top right menu and "Show keyboard"
3. If the remote device isn't currently displaying anything the keyboard shows up in the middle of the screen, if it is showing something it still shows up near the middle
4. Attempt to drag the keyboard by touching the title bar area of the floating "window" inside the PiKVM interface
5. Fail to drag with a finger and resort to an attached mouse or trackpad IF one is available.

**Expected behavior**
Allow repositioning the virtual keyboard/terminal/HDMI view with a finger and not just the mouse.

**Desktop (please complete the following information):**
 - OS: ChromeOS r115
 - Browser:  Chrome
 - Version: 115

**PiKVM info:**
  - Raspberry Pi board version: RPi 4
  - PiKVM platform: PiKVM 4 Plus
  - Video capture type: CSI bridge
  - KVMD version: `pacman -Q | grep kvmd`
    ```
    [kvmd-webterm@pikvm ~]$ pacman -Q | grep kvmd
    kvmd 3.238-1
    kvmd-fan 0.26-1
    kvmd-oled 0.24-1
    kvmd-platform-v4plus-hdmi-rpi4 3.238-1
    kvmd-webterm 0.43-1
    ```
  - uStreamer version: `pacman -Q | grep ustreamer`
    ```
    [kvmd-webterm@pikvm ~]$ pacman -Q | grep ustreamer
    ustreamer 5.41-1
    ```
  - Linux kernel: `uname -a` `Linux pikvm 5.15.68-3-rpi-ARCH #1 SMP Mon Oct 31 20:56:54 MSK 2022 armv7l GNU/Linux`

arch1mede, 2023-08-06:
While this is a known issue right now, there are plans on improving the mobile experience this fall, loose ETA.

mdevaev, 2023-08-09:
This is not related with generic mobile ui, but I don't know why it's not working. `ontouch*` events is not firing on the desktop chrome.

spoelstraethan, 2023-08-09:
I can try enabling the input logging flag on ChromeOS and see if it shows
the browser interaction portions on the PiKVM page. If there is a verbose
mode for the web server I can enable that as well.

I can also test in Chrome on a Windows touchscreen device to see if Google
is messing with things on ChromeOS causing the bad behavior.

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

mdevaev, 2023-08-09:
I found a device with touch, but I just don't know how to fix it yet. If I come up with something, I'll fix it.

spoelstraethan, 2023-08-24:
I think I figured out at least a hint of what is happening, when I touch
the screen I'm seeing everything in the PiKVM interface jump a couple
pixels, so that's telling me it is treating it like a hold and drag for the
top level of the interface and not passing the events into the internal
modals.

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

mdevaev, 2025-05-10:
I found a way to fix it. God only knows why it works. It will be available in the next release.

Closed 2025-05-10.

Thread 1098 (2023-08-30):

HP Elite Mini 800 G9 - not entering startup menu with PiKVM

bogd, 2023-08-30:
**Describe the bug**
The unit does not enter the startup menu when connected to PiKVM. If I connect a "normal" monitor via HDMI, everything works fine.

**To Reproduce**
Steps to reproduce the behavior, like:
1. Power on the unit
2. Press Esc to enter startup menu
3. The unit hangs at "Entering startup menu..."

If I repeat the steps using an external monitor (instead of PiKVM), the unit enters startup menu without any issues.

**Expected behavior**
The startup menu should be displayed, allowing for firmware updates, boot menu, etc.

**Screenshots**

**Desktop (please complete the following information):**
 - OS: [e.g. iOS]
 Windows 10
 - Browser [e.g. chrome, safari]
 Chrome
 - Version [e.g. 22]
115.0.5790.171
 - VNC client (if used)
N/A

**PiKVM info:**
  - Raspberry Pi board version [e.g. RPi 4]
 RPi 4
  - PiKVM platform [e.g. v2-hdmi]
 v3
  - Video capture type [e.g. CSI bridge]
 CSI
  - KVMD version: `pacman -Q | grep kvmd`
kvmd 3.252-1
kvmd-fan 0.26-1
kvmd-oled 0.25-1
kvmd-platform-v3-hdmi-rpi4 3.252-1
kvmd-webterm 0.43-1

  - uStreamer version: `pacman -Q | grep ustreamer`
 ustreamer 5.42-1

  - Linux kernel: `uname -a`
`Linux pikvm 5.15.68-3-rpi-ARCH #1 SMP Mon Oct 31 20:56:54 MSK 2022 armv7l GNU/Linux`

**Additional context**

Initially, I had problems using the PiKVM virtual keyboard before boot (even the Esc keypress was not recognized). I fixed it by disabling mass storage device in PiKVM (which kinda makes it impossible to use PiKVM to install the OS on the unit? But that's another problem, for another issue). Now I can press Esc on PiKVM, I see the "Entering startup menu..." message, but the HP unit hangs there.

The same issue persists even when I connect an external keyboard directly to the HP unit's USB port, and trigger the startup menu by pressing Esc on the physical keyboard - unit still hangs.

If I connect the physical keyboard and external monitor directly to the HP unit, the unit enters boot menu without any issues.

mdevaev, 2023-08-31:
Hello. Do you mean that you don't see the BIOS or there is a hang? What happens if you connect a physical monitor during a potential hangup?

bogd, 2023-09-01:
Unclear which one it is. As far as I can tell, the HP unit hangs - however, it makes all the "normal" noises, so I am not really sure if it actually hangs or it simply is unable to display the screen.

If I switch to a physical monitor during the hangup, all I get is a black screen.

The strangest thing is that no other connection (other than HDMI) is moved - I have USB connected to both PiKVM and an external keyboard, and those stay in place. I just switch the HDMI output - connect it to a "normal" monitor, everything is fine; connect it to PiKVM, the screen hangs.

I have also reproduced the problem on an HP Elite 600 G9 mini (not really surprising, since the hardware is all but identical).

mdevaev, 2023-09-01:
Try some alternative edids for display emulation: https://docs.pikvm.org/edid/

mdevaev, 2023-09-02:
> Before I close this, there is still the problem of "keyboard is ignored before boot, unless I disable mass storage device". Which means that I cannot really use PiKVM to mount an OS installation ISO and install the OS remotely. To avoid opening another issue for this - is there a workaround I could use in this case? A way to get the keyboard working, AND MSD support? Can you point me in the right direction?

I believe that the reason for the problem is that the BIOS on HP wants something strange that is missing in the Linux kernel modules on PiKVM. I could fix this, since I have a USB protocol analyzer, but there is not a single sample of devices with a similar problem.

As a temporary solution, you can use a [dynamic USB configuration](https://docs.pikvm.org/usb_dynamic). This is a bit unsafe for KVM (described in detail in the documentation), but it works. Even if a kernel panic occurs in V3, the device will simply reboot.

bogd, 2023-09-07:
Closing as "should have read the documentation, but in my defense I had no idea that EDID even existed, let alone that it could be changed... :) " . Thank you once again for all your help!!

mdevaev, 2023-09-07:
Ur welcome :)

Closed 2023-09-07.

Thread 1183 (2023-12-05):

Any recommendation for hdmi csi-2?

haze1986, 2023-12-05:
Dear all, I'm tempted to try with newer revisions of the hdmi csi-2 that may allow for 1080p 60hz. Does anyone know other than the offical, is there a list of working modules?

mdevaev, 2023-12-05:
There are no modules for RPi2-4 supporting 60Hz at all, because 1080p50Hz is a physical limitation of the bus, that is, the number of wires inside the connector. In order to implement 60Hz, we had to develop a V4 with our own circuitry. So if you really need 60Hz, then you need V4.

mdevaev, 2023-12-05:
I do not recommend using bli* at all, because these are, in fact, low-quality basement fakes. According to reports in the discord, they burn out, simply do not boot, suffer from poor design (the official recommendation is to seal part of the board with duct tape to avoid a short circuit with the CM4 module), and their chips fall off due to poor soldering, etc. Well, not to mention that actually bli* steal our schematics, send spam, use my software and give nothing in return, trying to expose themselves as the original authors of open source kvm. Do you really want to support these guys? :)

The V4 has its price not because we are greedy, but to ensure the reliability of the device itself. We use automation grade components, test batches at the factory, test boards, do X-ray inspection, test the finished device, and so on. You are buying a device for emergency remote access, it must be reliable, once and for a long time. If a miracle happens and our device turns out to be defective, you will have no problems changing it. And the broken device will go to our laboratory and be dissected to find out the cause and add another factory test to prevent this in the future.

haze1986, 2023-12-05:
> I do not recommend using bli* at all, because these are, in fact, low-quality basement fakes. According to reports in the discord, they burn out, simply do not boot, suffer from poor design (the official recommendation is to seal part of the board with duct tape to avoid a short circuit with the CM4 module), and their chips fall off due to poor soldering, etc. Well, not to mention that actually bli* steal our schematics, send spam to discord pm with advertising, use my software and give no contributions in return, trying to expose themselves as the original authors of open source kvm. Do you really want to support these guys? :)
>
> The V4 has its price not because we are greedy, but to ensure the reliability of the device itself. We use automation grade components, test batches at the factory, test boards, do X-ray inspection, test the finished device, and so on. You are buying a device for emergency remote access, it must be reliable, once and for a long time. If a miracle happens and our device turns out to be defective, you will have no problems changing it. And the broken device will go to our laboratory and be dissected to find out the cause and add another factory test to prevent this in the future.

Understood, I happen to want to test this just cos I have a spare pi zero 2 and would like to absolute minimum cost. Thank you for your clarifications though.

mdevaev, 2023-12-05:
As I said, there is a physical limitation and cannot be done without a whole small motherboard around compute module. A couple of days ago, [I updated the instructions for DIY solutions](https://docs.pikvm.org/v2). If you want the cheapest possible testing, then just buy any compatible module. Yes, you'll be limited to 1080p 50Hz, but it still works great.

haze1986, 2023-12-05:
> As I said, there is a physical limitation and cannot be done without a whole small motherboard around compute module. A couple of days ago, [I updated the instructions for DIY solutions](https://docs.pikvm.org/v2). If you want the cheapest possible testing, then just buy any compatible module. Yes, you'll be limited to 1080p 50Hz, but it still works great.

Is there a list of compatible modules? The link for DIY solutions shows the waveshare model with 1080p30.

Thanks.

mdevaev, 2023-12-05:
All modules are compatible except Auvidea B101, but you are unlikely to buy it somewhere. Zero only requires a special CSI cable, I described this in the instructions.

Closed 2023-12-05.

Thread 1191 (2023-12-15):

Windows HID not working?

deanfourie1, 2023-12-15:
**Describe the bug**
The PICO HID device is not recognized by windows. Instead, it shows in device manager as a RP2 Boot device and the keyboard and mouse does not work on target machine. I tested this previously on a different machine and it worked without issue.

The only real difference is the previous machine had internet, this one does not. But I have tried it with internet too to see if it will download a driver, it does not.

**To Reproduce**
Steps to reproduce the behavior, like:
1. Using a PICO, setup as per the instructions, plug in USB and no mouse/keyboard control.

**Expected behavior**
keyboard and mouse to work.

**Screenshots**
If applicable, add screenshots to help explain your problem.

**Desktop (please complete the following information):**
 - OS: [e.g. iOS]
 - Browser: Chrome/Edge

**PiKVM info:**
  - Raspberry Pi board version: rpi4
  - PiKVM platform: v2
  - Video capture type: HDMI USB Capture
  - KVMD version: `pacman -Q | grep kvmd`

**Additional context**
Add any other context about the problem here.

mdevaev, 2023-12-15:
Are you sure that you did not press the reset button on the board when connecting? If this happens, then Pico will remain in boot mode. Try to completely disconnect the KVM from the host (including power) and reconnect it.

deanfourie1, 2023-12-15:
I'm sure, the the unit is completely boxed.

Thanks

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

mdevaev, 2023-12-16:
You have two devices with Pico, as I see it. Does the second one behave exactly the same, or is the problem only observed on one?

deanfourie1, 2023-12-16:
Yes, both behave the same.

This is strange, as I tested both these devices prior to deployment and they worked.
I then took the device out that is not working and tested it again on the same machine I first tested on, and same result. It just showed up in device manager as RP2 boot and did not work.
I dropped the firmware back on the pico as it was showing up as a USB drive, so i take it it was in flash mode? Anyway, I dropped it back on, it rebooted and it worked again.

Here I was thinking I had sorted out the issue, but when I put it back on the other machine, it still doesnt work. I no longer shows as RP2 Boot, and I can see a HID Compliant Keyboard and Mouse in device manager, but no go!

I have the same issue on both, only difference is one is on windows, and one on my Proxmox host (debian).

Neither HID keyboard and mouse passthrough are working.

Thanks

mdevaev, 2023-12-16:
Could you check vendor and product ID when Pico boots in RP2 Boot mode?

deanfourie1, 2023-12-17:
Sorry, not exactly sure where to find that. I did however find this,

deanfourie1, 2023-12-17:
One question, One thing that I did not do was this. Is this required for the PiKVM v2? As I have had it working without doing the following steps.

I am again, plugging the device into multiple machine, and yet I still have NO HID keyboard and mouse control on either of the two PiKVM devices. Its almost like it only works on first boot initially after flashing the Pico.

```
The final steps[¶](https://docs.pikvm.org/pico_hid/#the-final-steps)
Connect the Pico HID to the target host using the USB cable.

If you are building PiKVM [V1](https://docs.pikvm.org/v1/), no further action with the Pico HID is required.

If you are making the Pico HID for [V2](https://docs.pikvm.org/v2/) or [V3](https://docs.pikvm.org/v3/), add the following lines to the PiKVM configuration and reboot it:

/boot/config.txt

dtoverlay=spi0-1cs
/etc/kvmd/override.yaml:

kvmd:
    hid:
        type: spi
        chip: 0
        bus: 0
        sw_cs_pin: 7
        sw_cs_per_byte: true
        reset_pin: 25
        reset_inverted: true
        reset_self: true
        power_detect_pin: 16
        power_detect_pull_down: true
```

I'm really at a loss here now. I have the USB of the Pico plugged in and the devices (Both HID keyboard and mouse show in windows) but I have no control.

deanfourie1, 2023-12-17:
Ok here's an update. I added the above to /boot/config.txt and /etc/kvmd/override.yaml and now its working but not 100%.

Sorry, I completely missed this step.

However, I still have no control over keyboard in the BIOS or PRIOR to windows booting,

Even after windows has booted, I have to select the "Reset HID" option in PiKVM before it will start working. One I reset the HID, the mouse and keyboard work find on both, but still absolutely no BIOS support.

Any ideas?

Thanks

mdevaev, 2023-12-17:
> I completely missed this step.

Why you're making pico hid / v1 build for rpi4? Why not v2 build? You will have mass storage.

By the way, I don't see you connecting a wire with a diode to the pico. Is that true?

deanfourie1, 2023-12-17:
I'm pretty sure I've done the v2 build.

Also, no I have not connected the red wire with the diode. As it says I don't need to connect it.

mdevaev, 2023-12-17:
The V2 is build without Pico.

https://docs.pikvm.org/v2

deanfourie1, 2023-12-17:
Sorry, documentation is a little confusing. Are you saying that I dont need the Pico for the v2 build?

I see it mentions using a USB Type C Y cable, but is this for keyboard/mouse support ot just for the Flash drive access?

Is it possible to leave the Pico in place as this is already setup.

Thanks, I hope we get to the bottom of it.

mdevaev, 2023-12-18:
> I see it mentions using a USB Type C Y cable, but is this for keyboard/mouse support ot just for the Flash drive access?

Yes

> Is it possible to leave the Pico in place as this is already setup.

Yes but mass storage will not work.

Just to be sure, do you have a diode to make that connection?

deanfourie1, 2023-12-18:
Im sure I could dig one out somewhere.

deanfourie1, 2023-12-18:
Question regarding the USB, could I just solder join a USB cable together,

ITs only D+ and D- required and GND right? Better yet, could I just use 1 usb cable and power the PI from the PC.

mdevaev, 2023-12-18:
You can use two suitable cables to make it.

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

deanfourie1, 2023-12-19:
Ok, I have connected the TypeC usb as per the diagram above,

Everything looks good in device manager, still no keyboard and mouse.

Any ideas?

mdevaev, 2023-12-19:
You should revert your modifications in override.yaml, or just reflash os using v2-hdmiusb-rpi4 image.

deanfourie1, 2023-12-20:
Thanks, all is working nicely now.

I do seem to have one issue with the linux Proxmox serer, video keeps cutting out randly like ever 5 seconds.

Is there anything special that needs to be done on Linux machines or any reason you can think this may be hapenning?

Seems fine on windows with same setup.

Closed 2023-12-20.

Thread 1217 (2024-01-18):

Video capture stops permanently when HDMI output stops

rgov, 2024-01-18:
**Describe the bug**
When the HDMI input is lost, PiKVM's video capture seems to fail and ~~the PiKVM device~~ ~~`kvmd.service`~~ `ustreamer` requires a reboot.

I was using PiKVM attached to a Windows 10 PC. When I shut down the PC, the PiKVM browser interface froze on the Windows 10 shutdown animation. Refreshing the browser, switching between WebRTC and HTTP streaming, rebooting the target PC, and replugging the HDMI cable did not resolve the issue.

When I rebooted the PiKVM and got video capture back.

Later, with the target PC booted (this time to Ubuntu), I allowed the computer to fall asleep (at least, display sleep), and the same thing happened.

**To Reproduce**

I'm trying to find better repro steps.

1. Connect a target PC to the HDMI capture port of the PiKVM.
2. Cause the PC to turn off its displays (e.g., suspend it).
3. Wake the displays and try to get video captured via the browser.

**Screenshots**
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

**Desktop (please complete the following information):**
 - OS: macOS 14.2
 - Browser: Safari 17.2

**PiKVM info:**
  - Raspberry Pi 4
  - PiKVM platform: V4 Mini
  - Video capture type: HDMI
  - KVMD version:

        kvmd 3.293-1
        kvmd-fan 0.29-1
        kvmd-oled 0.26-1
        kvmd-platform-v4mini-hdmi-rpi4 3.293-1
        kvmd-webterm 0.48-1

  - uStreamer version: `ustreamer 5.48-2`
  - Linux kernel: `Linux pikvm 6.1.61-1-rpi-ARCH #1 SMP Fri Nov  3 20:48:52 MSK 2023 armv7l GNU/Linux`

rgov, 2024-01-18:
Trying to step through this more slowly.

When the PiKVM first boots:

```
[   17.620865] dwc2 fe980000.usb: bound driver configfs-gadget.kvmd
[   23.713142] dwc2 fe980000.usb: new device is full-speed
[   23.869880] dwc2 fe980000.usb: new device is high-speed
[   23.903209] dwc2 fe980000.usb: new address 3
```

When booting into the GRUB menu (no video capture):

```
[  139.419855] configfs-gadget.kvmd gadget.0: error in submission: ep1out --> -11
[  139.474382] dwc2 fe980000.usb: new device is high-speed
[  139.480701] dwc2 fe980000.usb: new address 1
```

Then when I select to boot into Ubuntu (video capture works):

```
[  178.253814] configfs-gadget.kvmd gadget.0: End Point Request ERROR: -108
[  178.253832] configfs-gadget.kvmd gadget.0: error in submission: ep1out --> -11
[  178.308367] dwc2 fe980000.usb: new device is high-speed
[  178.435054] dwc2 fe980000.usb: new device is high-speed
[  178.508078] dwc2 fe980000.usb: new address 2
```

When Ubuntu goes to sleep, and PiKVM video capture fails, **there is no dmesg output** corresponding to this moment.

rgov, 2024-01-18:
It is sufficient to restart the `kvmd.service`, not the whole device.

rgov, 2024-01-18:
Here is what ustreamer debug log looks like at the point the display falls asleep:

```
Jan 18 01:16:11 pikvm kvmd[5062]: kvmd.apps.kvmd.streamer           INFO --- => -- DEBUG [2884.947    stream] -- H264: Fetching OUTPUT buffer ...
Jan 18 01:16:11 pikvm kvmd[5062]: kvmd.apps.kvmd.streamer           INFO --- => -- DEBUG [2884.947    stream] -- H264: Releasing OUTPUT buffer=0 ...
Jan 18 01:16:11 pikvm kvmd[5062]: kvmd.apps.kvmd.streamer           INFO --- => -- VERB  [2884.947    stream] -- H264: Compressed new frame: size=13, time=0.037, force_key=0
Jan 18 01:16:11 pikvm kvmd[5062]: kvmd.apps.kvmd.streamer           INFO --- => -- VERB  [2884.947    stream] -- H264-sink: >>>>> Exposing new frame ...
Jan 18 01:16:11 pikvm kvmd[5062]: kvmd.apps.kvmd.streamer           INFO --- => -- VERB  [2884.947    stream] -- H264-sink: Exposed new frame; full exposition time = 0.000
Jan 18 01:16:11 pikvm kvmd[5062]: kvmd.apps.kvmd.streamer           INFO --- => --------------------------------------------------------------------------------
Jan 18 01:16:11 pikvm kvmd[5062]: kvmd.apps.kvmd.streamer           INFO --- => -- DEBUG [2884.948    stream] -- Waiting for worker ...
Jan 18 01:16:11 pikvm kvmd[5062]: kvmd.apps.kvmd.streamer           INFO --- => -- DEBUG [2884.948    stream] -- Releasing device buffer=1 ...
Jan 18 01:16:11 pikvm kvmd[5062]: kvmd.apps.kvmd.streamer           INFO --- => -- DEBUG [2884.948    stream] -- Exposed ALIVE video frame
Jan 18 01:16:11 pikvm kvmd[5062]: kvmd.apps.kvmd.streamer           INFO --- => -- PERF  [2884.948    stream] -- ##### Encoded JPEG exposed; worker=jw-1, latency=0.097
Jan 18 01:16:11 pikvm kvmd[5062]: kvmd.apps.kvmd.streamer           INFO --- => -- DEBUG [2884.948    stream] -- Calling select() on video device ...
Jan 18 01:16:11 pikvm kvmd[5062]: kvmd.apps.kvmd.streamer           INFO --- => -- DEBUG [2884.950      http] -- HTTP: Updating exposed frame (online=1) ...
Jan 18 01:16:11 pikvm kvmd[5062]: kvmd.apps.kvmd.streamer           INFO --- => -- VERB  [2884.950      http] -- HTTP: Dropped same frame number 7; cmp_time=0.000000
Jan 18 01:16:11 pikvm kvmd[5062]: kvmd.apps.kvmd.streamer           INFO --- => -- DEBUG [2884.959      jw-0] -- JPEG-0: Fetching OUTPUT buffer ...
Jan 18 01:16:11 pikvm kvmd[5062]: kvmd.apps.kvmd.streamer           INFO --- => -- DEBUG [2884.959      jw-0] -- JPEG-0: Releasing OUTPUT buffer=0 ...
Jan 18 01:16:11 pikvm kvmd[5062]: kvmd.apps.kvmd.streamer           INFO --- => -- VERB  [2884.959      jw-0] -- JPEG-0: Compressed new frame: size=41317, time=0.049, force_key=0
Jan 18 01:16:11 pikvm kvmd[5062]: kvmd.apps.kvmd.streamer           INFO --- => -- VERB  [2884.959      jw-0] -- Compressed new JPEG: size=41317, time=0.049, worker=jw-0, buffer=4
Jan 18 01:16:11 pikvm kvmd[5062]: kvmd.apps.kvmd.streamer           INFO --- => -- DEBUG [2884.959      jw-0] -- Worker jw-0 waiting for a new job ...
Jan 18 01:16:11 pikvm kvmd[5062]: kvmd.apps.kvmd.streamer           INFO --- => -- DEBUG [2885.530    stream] -- Device select() --> 1
Jan 18 01:16:11 pikvm kvmd[5062]: kvmd.apps.kvmd.streamer           INFO --- => -- DEBUG [2885.530    stream] -- Frame is ready
Jan 18 01:16:11 pikvm kvmd[5062]: kvmd.apps.kvmd.streamer           INFO --- => -- DEBUG [2885.530    stream] -- Grabbing device buffer ...
Jan 18 01:16:11 pikvm kvmd[5062]: kvmd.apps.kvmd.streamer           INFO --- => -- DEBUG [2885.530    stream] -- Grabbed new frame: buffer=0, bytesused=4147200, grab_ts=2884.901, >
Jan 18 01:16:11 pikvm kvmd[5062]: kvmd.apps.kvmd.streamer           INFO --- => -- PERF  [2885.530    stream] -- A new second has come; captured_fps=24
Jan 18 01:16:11 pikvm kvmd[5062]: kvmd.apps.kvmd.streamer           INFO --- => -- VERB  [2885.530    stream] -- Correcting pool's JPEG approx_job_time: 0.052 -> 0.052 (last_job_t>
Jan 18 01:16:11 pikvm kvmd[5062]: kvmd.apps.kvmd.streamer           INFO --- => -- VERB  [2885.530    stream] -- Fluency: delay=0.025, grab_after=2885.555
Jan 18 01:16:11 pikvm kvmd[5062]: kvmd.apps.kvmd.streamer           INFO --- => -- DEBUG [2885.530    stream] -- Assigned new frame in buffer=0 to worker=jw-1
Jan 18 01:16:11 pikvm kvmd[5062]: kvmd.apps.kvmd.streamer           INFO --- => -- VERB  [2885.530      jw-1] -- Compressing JPEG using M2M-IMAGE: worker=jw-1, buffer=0
Jan 18 01:16:11 pikvm kvmd[5062]: kvmd.apps.kvmd.streamer           INFO --- => -- DEBUG [2885.530      jw-1] -- JPEG-1: Compressing new frame; force_key=0 ...
Jan 18 01:16:11 pikvm kvmd[5062]: kvmd.apps.kvmd.streamer           INFO --- => -- DEBUG [2885.530      jw-1] -- JPEG-1: Grabbing INPUT buffer ...
Jan 18 01:16:11 pikvm kvmd[5062]: kvmd.apps.kvmd.streamer           INFO --- => -- DEBUG [2885.530    stream] -- H264: Compressing new frame; force_key=0 ...
Jan 18 01:16:11 pikvm kvmd[5062]: kvmd.apps.kvmd.streamer           INFO --- => -- DEBUG [2885.530    stream] -- H264: Using INPUT-DMA buffer=0
Jan 18 01:16:11 pikvm kvmd[5062]: kvmd.apps.kvmd.streamer           INFO --- => -- DEBUG [2885.531    stream] -- H264: Sending INPUT-DMA buffer ...
Jan 18 01:16:11 pikvm kvmd[5062]: kvmd.apps.kvmd.streamer           INFO --- => -- DEBUG [2885.531      jw-1] -- JPEG-1: Grabbed INPUT buffer=0
Jan 18 01:16:11 pikvm kvmd[5062]: kvmd.apps.kvmd.streamer           INFO --- => -- DEBUG [2885.531    stream] -- H264: Polling encoder ...
Jan 18 01:16:11 pikvm kvmd[5062]: kvmd.apps.kvmd.streamer           INFO --- => -- DEBUG [2885.544      jw-1] -- JPEG-1: Sending (releasing) INPUT buffer ...
Jan 18 01:16:11 pikvm kvmd[5062]: kvmd.apps.kvmd.streamer           INFO --- => -- DEBUG [2885.545      jw-1] -- JPEG-1: Polling encoder ...
Jan 18 01:16:11 pikvm kvmd[5062]: kvmd.apps.kvmd.streamer           INFO --- => -- DEBUG [2885.582      jw-1] -- JPEG-1: Fetching OUTPUT buffer ...
Jan 18 01:16:11 pikvm kvmd[5062]: kvmd.apps.kvmd.streamer           INFO --- => -- DEBUG [2885.593      jw-1] -- JPEG-1: Releasing OUTPUT buffer=0 ...
Jan 18 01:16:11 pikvm kvmd[5062]: kvmd.apps.kvmd.streamer           INFO --- => -- VERB  [2885.593      jw-1] -- JPEG-1: Compressed new frame: size=1733370, time=0.063, force_key=0
Jan 18 01:16:11 pikvm kvmd[5062]: kvmd.apps.kvmd.streamer           INFO --- => -- VERB  [2885.593      jw-1] -- Compressed new JPEG: size=1733370, time=0.063, worker=jw-1, buffer>
Jan 18 01:16:11 pikvm kvmd[5062]: kvmd.apps.kvmd.streamer           INFO --- => -- DEBUG [2885.593      jw-1] -- Worker jw-1 waiting for a new job ...
Jan 18 01:16:12 pikvm kvmd[5062]: kvmd.apps.kvmd.streamer           INFO --- => -- DEBUG [2885.963      http] -- HTTP: Repeating exposed ...
Jan 18 01:16:12 pikvm kvmd[5062]: kvmd.apps.kvmd.streamer           INFO --- => -- DEBUG [2886.532    stream] -- H264: Polling encoder ...
Jan 18 01:16:13 pikvm kvmd[5062]: kvmd.apps.kvmd.streamer           INFO --- => -- DEBUG [2886.975      http] -- HTTP: Repeating exposed ...
Jan 18 01:16:13 pikvm kvmd[5062]: kvmd.apps.kvmd.streamer           INFO --- => -- DEBUG [2887.533    stream] -- H264: Polling encoder ...
Jan 18 01:16:14 pikvm kvmd[5062]: kvmd.apps.kvmd.streamer           INFO --- => -- DEBUG [2887.980      http] -- HTTP: Repeating exposed ...
```

These last logs repeat forever even after the display comes back.

rgov, 2024-01-18:
I think I narrowed it down enough to track in https://github.com/pikvm/ustreamer/issues/253.

Closed 2024-01-18.

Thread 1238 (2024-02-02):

PiKVM 4 Plus hardware case issue with official RPi CM4 antenna kit

wb6vpm, 2024-02-02:
**Describe the bug**
Unable to install the official CM4 antenna kit, as the hole for the antenna is too small (yes, I did make sure that I was attempting to do it with the flat spot oriented correctly).

**To Reproduce**
Steps to reproduce the behavior, like:

1. Attempt to install SMA antenna connector into either one of the 2 holes on the case.
2. SMA connector will not go through the hole, as the hole is too small

**Expected behavior**
SMA connector goes through the hole

**Screenshots**
(multiple pictures)
https://share.icloud.com/photos/0d2-hayiwKevMLQ2CED75iJCg

**Desktop (please complete the following information):**
NA, hardware issue

**PiKVM info:**
Brand new PiKVM 4 Plus kit

**Additional context**
Both items (PiKVM 4+ & CM4 antenna kit) were received this week from pishop.us webstore

mdevaev, 2024-02-03:
Hello. Did you try just to screw it with some force? Most likely the painting is too thick.

wb6vpm, 2024-02-03:
> Hello. Did you try just to screw it with some force? Most likely the painting is too thick.

It’s a keyed hole (has flat side on it, making it kind of look like a D, instead of an O), which is done specifically to prevent that from happening, so unfortunately, there is no way to screw it in.

mdevaev, 2024-02-03:
What about pushing it through? I still think the problem is the paint.

wb6vpm, 2024-02-03:
I gave it a pretty hard push against it, but I can try again on Monday.

Out of curiosity, according to the design files for the case, what size hole is it supposed to be? I ask because it’s almost like they inadvertently grabbed the wrong dimension off the connector (such as the tip instead of the threaded part) as their basis for the hole.

mdevaev, 2024-02-03:
The hole was correct in the drawings and in the first batches, we checked it. If there is a problem now, it is either painting, or the factory messed up with a new batch and we will deal with it.

wb6vpm, 2024-02-03:
Sounds good. After I attempt the push through, I’ll go ahead and scrape the paint off inside the hole to see if that fixes it and then let you know.

wb6vpm, 2024-02-08:
Sorry about that, this week has just gotten away from me. I did test it, and with scraping the paint off, it does fit, barely, with a pretty significant amount of force needed (comparatively, given the small size and delicacy of the part). I would recommend on the next run, going up 0.5mm to allow for the paint and tightness of the hole in general. Also as an aside, I would recommend posting the recommended cable routing path in the documentation, or alternatively to all of this, just include the antenna kit pre-installed in the next revision, and add $10 to the cost (or whatever it takes to offset the additional parts/labor costs), because honestly, getting to that connector, and then getting it seated on the CM4 board is a complete PITA once the PiKVM is assembled.

mdevaev, 2024-02-08:
Thank you for the information and I'm sorry for this inconvenience.

I will pass this on to the developer of the case and we will fix it in the next batch.

Closed 2024-02-08.

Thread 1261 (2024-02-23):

Keyboard+mouse doesn't work in UEFI on HP EliteBook

Sislik42, 2024-02-23:
Keyboard and mouse doesn't work in UEFI on HP EliteBook 840 14" G10 (Product number: 818Q7EA#UUZ).
When Windows boots, there is no issue, and keyboard and mouse is working properly.

We tried all USB A ports on mentioned NB as described in FAQ.
(We even tried USB on docking station, but we were expecting it will probably not work too.)

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

**Desktop (please complete the following information):**
 - OS: macOS
 - Browser: Safari
 - Version: 17.3.1 (19617.2.4.11.12)
 - VNC client: no

**PiKVM info:**
PiKVM V4 Plus, bought here https://www.pi-shop.ch/pikvm-v4-plus
PiKVM was just bought and updated to the latest version today
 - Raspberry Pi board version: ???
 - PiKVM platform: ???
 - Video capture type: ???
 - KVMD version:
kvmd 3.306-1
kvmd-fan 0.30-1
kvmd-oled 0.26-1
kvmd-platform-v4plus-hdmi-rpi4 3.306-1
kvmd-webterm 0.48-1
 - uStreamer version: ustreamer 5.51-1
 - Linux kernel: Linux pikvm 6.1.61-1-rpi-ARCH #1 SMP Fri Nov  3 20:48:52 MSK 2023 armv7l GNU/Linux

mdevaev, 2024-02-24:
Hello. For the first action, please try to disable mass storage drive: https://docs.pikvm.org/msd/#disabling-mass-storage

mdevaev, 2024-02-25:
:ok_hand:

jnstockley, 2024-03-02:
I am also having issues with my host device responding to input from my keyboard and/or mouse. I tried disabling the USB mass storage device, but that hasn't resolved the issue. Currently, TrueNAS Scale is installed, but also had an issue with the same device running Windows 10. When I unplug and re-plug the USB cable connected to the PiKVM I can see it's recognized. I am using a prebuilt PiKVM V3. I've also tried to re-install the OS which also didn't fix the issue.
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

mdevaev, 2024-03-03:
@jnstockley For the replugging case we have a special option. Switch it to OFF and back to ON. This is equivalent to reconnecting the cable, but can be done remotely in case of problems like yours.
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

jnstockley, 2024-03-08:
Thanks that is useful to know, but that doesn't seem to resolve the issue with the host not responding to keyboard and mouse interactions made through PiKVM. I'm assuming my issue is related to the original poster issue, but I could be wrong.

mdevaev, 2024-03-11:
@jnstockley What you see in dmesg when you're using usb switch in the menu?

mdevaev, 2024-03-11:
@Sislik42 You're welcome!

Closed 2024-03-25.

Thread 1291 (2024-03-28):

Split mouse/keyboard to usb hid and pico bridge

No0ne, 2024-03-28:
Looking at https://docs.pikvm.org/pico_hid_bridge/#the-final-steps both mouse and keyboard gets handed over to the pico hid.
But can you also split it up, so that the mouse gets routed thru the pi usb and the keyboard thru the pico ps/2?

Full issue see: https://github.com/No0ne/ps2x2pico/issues/29

mdevaev, 2024-03-28:
The current plugin interface does not allow this, there can only be one HID.

No0ne, 2024-03-29:
Ok, alternativly is it possible to connect a Pico HID via SPI on the PiKVM V4 board, e.g. by routing cables thru the wifi holes?

mdevaev, 2024-03-29:
V4 has no available SPI :(

No0ne, 2024-04-04:
Ok, thanks for that info, I'll try out the UART-way for this.

No0ne, 2024-04-06:
Thanks for the info, we got it working using the serial connection aka. GPIO22 jumpered to GND: https://github.com/No0ne/ps2x2pico/issues/29#issuecomment-2040496088

mdevaev, 2024-04-06:
Good to know :ok_hand:

JeWe37, 2024-05-15:
Hi @No0ne, what does your config look like in the end? I'm trying to do exactly this, have the mouse, usb drive etc. run through the OTG port and the keyboard through the pico HID. If I'm misunderstanding and you worked around this another way, could this issue be reopened? I would be interested in such functionality.

No0ne, 2024-05-15:
Hi, the main problem was that the pikvm v4 doesn't have SPI pins for the pico HID. We solved it by connecting via the serial interface as seen here: https://github.com/No0ne/ps2x2pico/issues/29#issuecomment-2040496088

What keyboard do you want to emulate, USB or PS/2?

JeWe37, 2024-05-15:
The issue is that I am trying to hook up the PiKVM to a traditional KVM. In order to switch it, I have to have a keyboard connected to its keyboard port, such that I can use the shortcuts to switch between PCs. That would be fine, except its dedicated keyboard port only supports keyboards, and no other peripherals. So to have other peripherals, I need to hook it up another USB port on it.

TLDR; I genuinely need 2 separate USB ports. I have a USB OTG port and a Pico HID, I want to combine them to be able to connect to two different USB ports.

No0ne, 2024-05-15:
You need to go thru PS/2 as shown here: https://github.com/No0ne/ps2x2pico/issues/29#issuecomment-2017771665
As mdevaev mentioned https://github.com/pikvm/pikvm/issues/1291#issuecomment-2026195470 its not possible to split keyboard and mouse right now so both have to go thru the pico.

JeWe37, 2024-05-15:
> You need to go thru PS/2 as shown here: [No0ne/ps2x2pico#29 (comment)](https://github.com/No0ne/ps2x2pico/issues/29#issuecomment-2017771665) As mdevaev mentioned [#1291 (comment)](https://github.com/pikvm/pikvm/issues/1291#issuecomment-2026195470) its not possible to split keyboard and mouse right now so both have to go thru the pico.

I see, though that won't work in my case. But given that that is very much a workaround. Therefore I'd appreciate if this could be reopened. I will perhaps see how complicated it would be to allow for multiple HID interfaces depending on the device and submit a PR if I can figure it out.

Closed 2024-04-06.

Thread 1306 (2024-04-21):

Improve guide for XH-HK4401

Ultranium, 2024-04-21:
I'd like to share my experience using what seems to be a slightly newer version of the XH-HK4401 4-port switch.

The main difference is it uses 3.3V non-inverted UART protocol for the remote control.
This is actually great, because it eliminates need of using an inverting FTDI adapter, and also allows to connect the switch control interface directly to Pi's UART without using any extra circuitry.

The markings on PCBs are:
- HDMI switch board: `PCB-HK4501-V0.2-A1-HDMI`
- USB/Control board: `PCB-HK4401-V2.0-B-USB`

Connecting this switch using the [current guide for the XH-HK4401](https://docs.pikvm.org/xh_hk4401/#switching-between-hosts-in-the-ui) won't work because of the different control interface implementation, so here are some instructions on how to do it.
I think, adding this information to the docs may help people with newer HK4401 switches.

**Before interfacing the switch with Raspberry using the following guide, one should first check the voltage levels on the control interface, because the manufacturer can change the implementation at any moment!!! If you accidentally connect a 5V version to your Pi, you can permanently damage it!**

### Using with FTDI adapter
I successfully used a $1 fake FTDI adapter from Aliexpress which looks like this:
<details>
<summary>FTDI adapter</summary>

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
</details>

1. Switch the jumper on the FTDI adapter to the position `3.3V`
2. Connect wires:
  - GND to USB GND (and shield, if present on cable)
  - TX to USB D- (white)
  - RX to USB D+ (green)
3. Remount the filesystem in read-write mode using the `rw` command
4. Append the following lines to `/etc/kvmd/override.yaml`:
<details><summary>override.yaml</summary>

```
kvmd:
    gpio:
        drivers:
            hk:
                type: xh_hk4401
                protocol: 2
                device: /dev/ttyAMA0
        scheme:
            ch0_led:
                driver: hk
                pin: 0
                mode: input
            ch1_led:
                driver: hk
                pin: 1
                mode: input
            ch2_led:
                driver: hk
                pin: 2
                mode: input
            ch3_led:
                driver: hk
                pin: 3
                mode: input
            ch0_button:
                driver: hk
                pin: 0
                mode: output
                switch: false
            ch1_button:
                driver: hk
                pin: 1
                mode: output
                switch: false
            ch2_button:
                driver: hk
                pin: 2
                mode: output
                switch: false
            ch3_button:
                driver: hk
                pin: 3
                mode: output
                switch: false
        view:
            table:
                - ["#Input 1", ch0_led, ch0_button]
                - ["#Input 2", ch1_led, ch1_button]
                - ["#Input 3", ch2_led, ch2_button]
                - ["#Input 4", ch3_led, ch3_button]

```
</details>

5. Remount the filesystem back to read-only mode using the command `ro`
6. Run `systemctl restart kvmd`

### Using with direct UART connection
1. Remount the filesystem in read-write mode using the `rw` command
2. Remove the `console=serial0,115200` parameter from `/boot/cmdline.txt`
3. Append the following lines to `/etc/kvmd/override.yaml`:
<details><summary>override.yaml</summary>

```
kvmd:
    gpio:
        drivers:
            hk:
                type: xh_hk4401
                protocol: 2
                device: /dev/ttyAMA0
        scheme:
            ch0_led:
                driver: hk
                pin: 0
                mode: input
            ch1_led:
                driver: hk
                pin: 1
                mode: input
            ch2_led:
                driver: hk
                pin: 2
                mode: input
            ch3_led:
                driver: hk
                pin: 3
                mode: input
            ch0_button:
                driver: hk
                pin: 0
                mode: output
                switch: false
            ch1_button:
                driver: hk
                pin: 1
                mode: output
                switch: false
            ch2_button:
                driver: hk
                pin: 2
                mode: output
                switch: false
            ch3_button:
                driver: hk
                pin: 3
                mode: output
                switch: false
        view:
            table:
                - ["#Input 1", ch0_led, ch0_button]
                - ["#Input 2", ch1_led, ch1_button]
                - ["#Input 3", ch2_led, ch2_button]
                - ["#Input 4", ch3_led, ch3_button]

```
</details>

5. Reboot
6. Connect wires:
  - GPIO pin 6 to USB GND (and shield, if present on cable)
  - GPIO pin 8 to USB D- (white)
  - GPIO pin 10 to USB D+ (green)

arch1mede, 2024-05-11:
Hi, Thank you for this feedback, This has been added to the existing documentation as additional follow-up. This issue will be closed.

empty2k, 2024-05-26:
Hi Ultranium I bought the same HDMI switch, but I have a different FTDI adapter. I bought this one here.
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

Unfortunately, I haven't been able to control the switch via the GPIO using the PiKVM so far. Would it be possible for you to show your setup? How does the wiring look from the switch to the PiKVM? A couple of photos would be appreciated.

Best regards and thank you

Ultranium, 2024-05-26:
Hi @empty2k .

You're using the UART adapter the wrong way.

You should plug it into a Pi's USB port, and then connect wires from adapter pins to the HDMI switch micro-USB control port like this (adapter side <-> switch side):

GND to USB GND (and shield, if present on cable)
TXD to USB D- (white)
RXD to USB D+ (green)

And no wires need to be connected to Pi GPIO.

My current setup is different from the reference one (because I use a custom solution to connect multiple ATX control boards), so it wouldn't be relevant here.

empty2k, 2024-05-26:
Wonderful! I must have mixed up a few things. I didn't really understand that I had to cut a Micro or Mini USB cable to connect the wires accordingly. However, I had to use /dev/ttyUSB0 in /etc/kvmd/override.yaml instead of /dev/ttyAMA0.
Apparently, I was lucky and nothing is damaged; at least, I haven't noticed any limitations so far.

Thank you very much @Ultranium

Ultranium, 2024-05-26:
Awesome!

You are absolutely right about using the `/dev/ttyUSB0`. It seems I forgot to change it in FTDI config in my manual. It's fixed now.

Ultranium, 2024-06-04:
> hi , i have: PCB-HK4501-V0.1-A-HDMI PCB-HK4401-V1.2-B-USB version and the method you mentioned not worked on me with cheap ftdi adapter same as yours. do you have any suggestion?
Hi @serkansmg.

Well, the best thing to do is to monitor exchange between the KVM switch and the remote first (using an oscilloscope or at least a multimeter), to find out what type of UART implementation is used on your particular unit.

If it's inverted (meaning there is about ~0V in idle mode on RX and TX lines), then you have to use an inverter IC the way it is described [here](https://docs.pikvm.org/xh_hk4401/#an-inverter-circuit-the-cheap-way).

If it is not inverted (there is ~3.3V or ~5V on RX and TX), set the FTDI adapter voltage switch accordingly, check your wiring and try to play with protocol version in `override.yaml` (line `protocol: 2`, possible values are 1 and 2).

serkansmg, 2024-06-04:
hi thanks for the fast reply.
on multimeter, placing probes to gnd-tx, gnd-rx, rx-tx it is not 0 on idle time. always there is ~3.2v
so is that mean it is not inverted?

also i replaced rx tx
because on your document it is:
GND to USB GND (and shield, if present on cable)
TXD to USB D- (white)
RXD to USB D+ (green)

and on original document https://docs.pikvm.org/xh_hk4401/ it is like:

D- | White | RX
D+ | Green | TX
Gnd | Black | GND

i also switch +5v and 3.3v nothing changed.
also echo "SW1\r\nG01gA" > /dev/ttyUSB0 did not made any change (1-2-3-4)

Ultranium, 2024-06-04:
Well, it seems to me that your FTDI adapter may be broken.
Since you found out that your KVM switch uses 3.3V non-inverted UART, you can try to connect it to Pi's GPIO directly (see the "Using with direct UART connection" section in my original post).

If it doesn't work even via direct connection, I recommend you to get an oscilloscope with UART decoder or a logic analyzer (you can get these for just a few bucks on Aliexpress nowadays) for further debugging, just to be sure that the signal is being sent from Raspberry indeed. You can also then compare data exchange between Pi and KVM switch to the data stream between KVM switch and the original remote to find discrepancies.

serkansmg, 2024-06-04:
today i will try with waveshare usb-ttl adapter. i guess it is not a fake one..
anyway if it not works.
i will try another interesting way..
i will use an esp32 and wire buttons on the controller's push buttons to esp32 gpio pins. :)) then from serial port on pikvm i will make it work to send commands to it..
so how will i configure override.yaml to send console commands?

Ultranium, 2024-06-04:
Wow, that's quite a complication!
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
Ultranium, 2024-06-05:
Well, what can I say... Wow!

But still, I found it strange that the original solution didn't work in your case.
I kind of feel sorry that you had to go through all this, because my experience with PiKVM and XH-HK4401 went way smoother (although, I also had to spend a couple of days just to find out that the initial schematics with ICs or inverting FTDI adapters is redundant for newer versions of the HDMI switch).

aqxa1, 2024-07-16:
Does the USB to TTL adapter need to be FTDI (or clone) on the newer XH-HK4401? Given that the inverting isn't needed.

Since I already have a ch341 converter with 3.3V support.

thecode, 2024-07-25:
> Does the USB to TTL adapter need to be FTDI (or clone) on the newer XH-HK4401? Given that the inverting isn't needed.
>
> Since I already have a ch341 converter with 3.3V support.

CH341 with 3.3V should work fine, I suggest to measure voltage & verify that your both your `XH-HK4401` and the converter are 3.3V, if they are it will work.

bluewhitep, 2025-01-11:
My setup is working with the following configuration:
- FTDI Device: DSD TECH SH-U09C
- Wiring:
  - TX → USB D− (white)
  - RX → USB D+ (green)
- Reasoning: Because the KVM’s TX and RX idle around 3.2V, the following settings are used:
  - No inversion on TX and RX
  - FTDI set to 3.3V

In operation, the RX LED blinks every 1–2 seconds.
When running `echo "SW3\r\nG03gA" > /dev/ttyUSB0` the TX LED flashes once.

FuNK3Y, 2025-02-15:
Is the connection communication bi-directional? Does pressing a physical button on the XH-HK4401 generate an event that can be caught by the pi kvm?

thecode, 2025-02-15:
> Is the connection communication bi-directional? Does pressing a physical button on the XH-HK4401 generate an event that can be caught by the pi kvm?

Yes, it works bidirectional, the web UI track the selected input even if changed from the physical button:
https://github.com/pikvm/kvmd/blob/02740aef374a2914cf85ba1cad16f5e93d0650f1/kvmd/plugins/ugpio/xh_hk4401.py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

maxpaine69, 2025-08-15:
so sorry to awaken this post, im trying to do something like described in this post.

- i have a swithc like that
- i already have a usb cable connected to it on the control port, and im receiving on the white and green cable 3.3v.

My question are is it possible to connect directly to the Pi usint the uart gpio pins?
I also read that its possible to get feedback back from the selection im i right?

serkansmg, 2025-08-16:
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

sure you can directly connect it to pi.

Closed 2024-05-14.

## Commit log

2020-11-22 Add instructions for 5GHz Wifi networks in the US
    Based on https://wimsworld.wordpress.com/2019/09/15/5ghz-wifi-on-raspberry-pi-4/
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2021-02-01 SPI and multiport Updates (#166)
    * Add Arduino SPI diagram for HID
    * Arduino SPI wiring and configuration
    * Arduino SPI Photos
    * Update arduino_hid.md
    Some wordsmithing and technical review, some of the parts list has been stated elsewhere but included here with some comments on different parts or other considerations.
    * Add TESmart 8 port switch
    * Corrected diagram
    Corrected diagram of the Arduino SPI HID layout wiring
    * Corrected wiring layout
    Corrected wiring layout of the Arduino Pro MIcro SPI HID
    * moved spi hid image to correct directory
    * Updated SPI HID pictures
    Updated pictures of the SPI HID wiring to match the updated circuit diagrams.
    * Upda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
2021-02-01 SPI Flashing Instructions (#167)
    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
2021-02-18 Updated link in multiport to current github directory for the TESmart script and documentation I wrote on using the KVM. (#199)
2021-02-27 Added Aimos 8port KVM HDMI switch (#213)
    Added another working configuration using Aimos 8port HDMI switch
2021-03-06 Update arduino_hid.md (#224)
    Found out that in the newer images in the cmdline.txt the entries have change.
    console=ttyAMA0,115200 is now console=serial0,115200 and kgdboc=ttyAMA0,115200 is now kgdboc=serial0,115200
2021-04-12 Update Community_FAQ.md (#273)
    Fixed a spelling error under "Power splitter" section
    Changed some verbiage around "Is Pi-KVM an OS" section
    ReWorked the "Multi-Monitor" section, moved the more relevant answer to the top
    Moved up "Why Arch Linux" section under "Is Pi-KVM an OS" section"
    Added more verbiage to "Pi keeps disconnecting" section
    Fixed some grammatical errors in "Things to do after install" section
    Added some more verbiage to the "Troubleshooting" section
    Added some missing bits to the script in the "Troubleshooting" section
    Fixed some formatting in the "Common Wifi" section
    Added verbiage in the "Common Wifi" section
    Separator added to the "Connection issues" section
    A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
2021-05-09 Update Community_FAQ.md (#301)
    Added instructions how to Emulate different USB devices
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2021-05-24 Update Community_FAQ.md (#319)
    Changed formatting for 3D cases under Useful Links section
    Added more verbiage in emulate USB devices section
2021-05-24 Update 3d_printing.md (#320)
    Added R4C3R PCIe bracket designs for PiKVM based on RPI Zero W
2021-06-05 Update multiport.md (#331)
    * Update multiport.md
    Added solution for the HDMI back power - Just found out about it
    * Update multiport.md
    Added link for the hdmi splitter
2021-06-20 Update Community_FAQ.md (#354)
    Added verbiage to Useful links
    Made 1 line out of Latency section
    Added more clarity and verbiage to power splitter section
    Added more clarity to using KB on a zerow
    Removed a section that seemed 3x as redundant
    Added a url reference back to the original information in how to get root section
    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
2021-06-21 Update README.md (#355)
    Added power blocker option as Variant #1 and moved the others down
    Replaced "appropriate" with "Official" for the power supply
2021-06-21 Update Community_FAQ.md (#356)
    Removed redundant power splitter boards
    Removed redundant power blocker as it was moved to the front page
2021-06-25 v3.3 stl
    [case_a.stl, case_a_no_oled.stl, case_b.stl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]
2021-07-06 Update Community_FAQ.md (#379)
    * Update Community_FAQ.md
    Added a 503 section and possible solutions
    * Update Community_FAQ.md
    * Update Community_FAQ.md
    Added Linux and Windows delineations to the cant find IP section
    Added verbiage to Power the pi over POE section
    Corrected URL for Why you need a splitter section
    Added more verbiage to Can I use a KB on the ZeroW section
    Removed how to get root as it was redundant
    Removed some verbiage in the different IP section, too advanced and outside the scope of PiKVM
    Added more verbiage to ran out of room section
    Added some verbiage for clarity in the have more questions section
    Added more verbiage to somethings not working section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
2021-07-08 Update multiport.md (#383)
    Added 1 backpower solution to the AMIOS 8 port and removed the arduino as it did not work.
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2021-07-12 Update Community_FAQ.md (#390)
    Forgot to remove how to get root in the web terminal index reference, removed
    Added verbiage to the different IP section
    Added new section for switching from USB to CSI and visa versa
2021-07-14 ZeroW wiring examples (#394)
    * Add files via upload
    * Add files via upload
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2021-08-25 v3.3 case
    [case_a.stl, case_a_no_oled.stl, case_b.stl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]
2021-09-04 Create Wiring Examples.md (#443)
    New wiring example document thats linking the pics in one document
2021-09-05 Update Wiring Examples.md (#444)
    Fixed the pics display issue ¯\_(ツ)_/¯
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2021-09-11 Update README.md (#462)
    Removed a line that was no longer relevant and conflicted with the main wiring examples page
2021-09-22 Update Wiring Examples.md (#475)
    Fixed spelling mistake
    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
2021-10-05 Update README.md (#500)
    Verbiage change, fixed cable type needed for one of the variants.
2021-10-14 atx long pci bar
    [pci_long.stl]
2021-10-15 atx pci short
    [pci_short.stl]
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2021-11-26 multiport.md: Fix Arduino typo (#546)
2021-11-28 Improved xh-hk4401 docs (#550)
    - Changed order so FTDI is first since this is the easier option
    - Changed the circuit for the inverter to one that is easier to
    make and is safer (doesn't send 5v to RPi GPIO and prevents
    back power)
    - Added table to show which uart to use based on which method
    is used
    - Added connetion details to FTDI method
    - Added note about checking if FTDI settings are saved
2021-12-12 spi fix
2021-12-28 ezcoo wiring example (#586)
    * Update Wiring Examples.md
    Fixed the picture display issue ¯\_(ツ)_/¯
    Ezcoo wiring example
    * Delete ezcoo wiring.png
    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
2021-12-29 Update ezcoo.md (#587)
    * Update ezcoo.md
    Added verbiage for a wiring example
    * Update ezcoo.md
    * Update ezcoo.md
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2022-01-25 FAQ cleanup suggestions (#623)
    * Clarify how to append mouse poll to cmdline.txt
    * FAQ spelling and wording changes
    * Corrected a couple of spelling errors.
    * Changed some phrasing into more idiomatic English.
    * Merged the two almost identical questions on 500/503 errors.
    * Separated the hardware question about the Pi Zero W from the general "I can't connect to Wi-Fi" FAQ.
    * Tried to standardise on "I" and question syntax in the question headers.
    * Updated and added context for the statement that only Chrome supports a particular extension.
    * Changed code quoting in a couple of answers to clarify what is code and what is commentary.
2022-02-08 New illustrated instructions (#629)
    * Create .gitkeep
    Adding new folder
    Adding pics
    * Create v3_illustrated_install_instructions.md
    New instructions
    * Update v3_illustrated_install_instructions.md
    * Update v3_illustrated_install_instructions.md
    * Update v3_illustrated_install_instructions.md
    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
2022-02-15 Adding plastic spacer (#651)
    Plastic spacer image
    Adding plastic spacer
    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
2022-02-21 usb ethernet compatibility and rndis5 driver inf for windows xp to windows 7 (#615)
    * Added inf driver for rndis5
    * driver compatibility
2022-03-11 Add notes about serial port voltages, device, etc (#662)
    * Add notes about serial port voltages, device, etc
    * Update v3.md
    * Update v3.md
    * Update v3.md
    * Add note about priority
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2022-06-19 Assembly instructions for v3.3 printed case (#743)
    * Assembly instructions for v3.3 printed case
    * Update to fan
    * Adds tip about tightening standoffs
2022-07-05 Added Aten KVM to the list of tested KVM devices and added a note abo… (#770)
    * Added Aten KVM to the list of tested KVM devices and added a note about VGA adapters to the readme
    * Fixed typo in link
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2022-11-09 update documentation to reflect best-practices (#857)
    * update tailscale.md to reflect best-practices
    The provided -Syy is supposed to be used to redownload all package databases,
    while the command chain itself is a partial upgrade which is not recommended
    either for rolling release distributions.
    Replace the full database redownload with a database update and run a system
    upgrade while installing tailscaled.
    * remove unnecessary sync command from video.md
    * remove unnecessary sync command from bluetooth_hid.md
    * remove unnecessary sync command from arduino_hid.md
    * update faq.md to reflect best practices
    * update letsencrypt.md to keep system up-to-date when installi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
2023-01-16 Update ezcoo.md (#914)
    Moved tip info regardings connections to be within the connections area.
    Added Tip regarding that the EZ-SW41HA-KVMU3L includes cables
2023-04-17 ATX Board documentation update (#995)
    * ATX Board details
    * Update on to the
    ---------
2023-05-01 update timer instructions (#1007)
    as per https://github.com/pikvm/pikvm/issues/833 filesystem needs to be rw to enable the timer
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2023-06-16 Update multiport.md (#1031)
    HK switching doesn't work when connected to Aimos HUB port
2023-06-22 Ensure credential files are owned by kvmd-certbot (#1036)
    The current instructions will lead to the file being owned by root with
    rw permissions only granted to the owner. However, the kvmd-certbot
    script around certbot will invoke certbot as the user kvmd-certbot.
    Therefore the credential files must be owned by kvmd-certbot.
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2024-02-13 Added manufacturer link since unavailable to the US via Amazon.de (#1237)
    * Added manufacturer link since unavailable to the US via Amazon.de
    * Changed link to Amazon.com as requested
    * Updated to Amazon.com
2024-04-09 Align WebRTC docs with current config (#1299)
    In pikvm/kvmd, kvmd/configs/janus/janus.jcfg, the port range is specified as 20000-40000.
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2024-08-01 Update v2.md (#1378)
    For Pi 4 and Pi Zero 2 W instructions:
    Added Raspberry Pi to the beginning of the official usb power supply name to clarify brand.
    For Just Pi Zero 2 W instructions:
    Corrected purchase link for Raspberry Pi Official USB-Micro Power Supply
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2024-12-06 pikvm/pikvm#1435: Fixed ethernet cable info link
2024-12-12 3d_printing.md: Fix link for one DIY case (#1439)
    It's not a case for the USB-C/PWR splitter
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2024-12-30 Add exfat warning for USB thumb drives (#1444)
    By default, exfat drives are mounted owned by root, with 755 perms
    on the mountpoint. Rather than going into setting 'uid' and 'gid'
    params, which rely on the uid and gid of the kvm user never changing,
    I thought it would be simpler to just give users the hint to set the
    default umask to 0000 (aka, 777) for all files. This allows the
    thumb drive to be visible as read-write.
2025-04-29 Quickstart guide updates (#1502)
    * Skeleton of the rewritten v4 quick start page
    * Front matter, what's in the box, config update for material, placeholders
    * Separate DIP switches doc into a separate file
    * Separate USB 3.0 support doc into a separate file
    * Reorganize V4 quick start page a little
    * Mention the mirror mode
    * Supported on-box controls, placeholder image, doc update
    * Cosmetic fixes
    * Add F° and Basic Troubleshooting
    * Initial V3 docs update
    - Applied the same general structure as with V4
    - Added front matter
    - Explained the HAT vs pre-assembled thing
    - Moved assembly bits to the assembly instructions page
    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
2025-05-18 Update v1.md (#1521)
    Corrected page title below title/description block to read “V1” instead of “V2”.
2025-05-19 Re-add quick wifi antenna how-to (#1523)
    * Re-add quick wifi antenna how-to
    * Embed a video about the antenna
2025-05-19 Update TESmart links for multiport.md (#1524)
    I have several of the TESmart switches both 8 and 16 port and 4k30/4k60 models that all work great with the v4mini and v4plus and DIY models.
2025-05-26 Passthrough (#1529)
    * Add USB passthrough documentation
    * Add front matter to HDMI passthrough
    * Add front matter and Materialize some formatting in Switch docs
2025-07-14 Major update of the API documentation (#1557)
    * Add initial HID API documentation
    The first version has placeholders for responses, to be filled at a later time.
    * Add initial Streamer API documentation
    Currently missing information about query parameters and a few others things.
    To be fixed after the first pass at all APIs.
    * Add initial PiKVM Switch API and Redfish API documentation
    This covers the basics and requires some testing to finalize the documentation
    * Cleanup, part 1 of N
    - Write short intro for HID and Streamer sections
    - Fix the structure in HI and Streamer
    - Standardize descriptions
    * Cleanup, part 2 of N: more standardization
    * Cleanup, part 3 of N:
    - Standardize t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
2025-09-12 Fix spelling error in Raspberry Pi 4 documentation (#1582)
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2025-11-30 Fixed minor typo, added link to Pico 2 (which isn't ausable yeet) (#1619)
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2026-06-22 #1569: document disabling MSD at startup for Dell/HP UEFIs (#1673)
    Some Dell (OptiPlex/Pro Micro 7020) and HP (EliteDesk 800 G4) UEFIs
    can't handle Mass Storage + HID on a single USB port, causing a black
    screen, boot loop, or lost BIOS settings.
    Document the recommended workaround `otg/devices/msd/start: false`,
    which keeps MSD configured but unstarted at boot (re-enable on demand
    via kvmd-otgconf), alongside the existing full-disable method. Note the
    affected hardware and warn against confusing the `msd` and `drives`
    config sections.
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
